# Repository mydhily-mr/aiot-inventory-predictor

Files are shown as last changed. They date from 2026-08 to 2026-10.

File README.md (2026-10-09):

# PRISM — Predictive Replenishment & Inventory Stock Monitoring

**PRISM predicts what you're about to run out of, before you run out.**

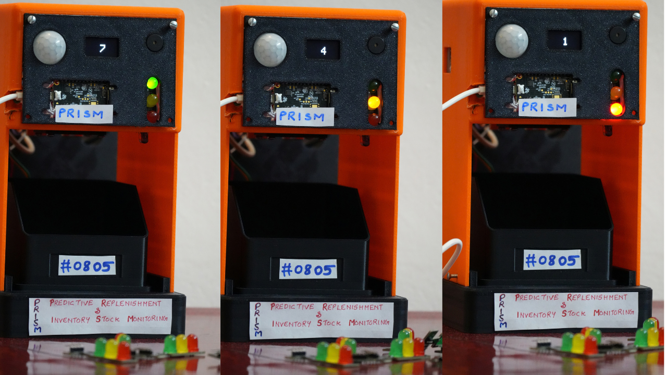
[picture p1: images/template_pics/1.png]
PRISM – three units showing green, yellow and red stock levels


📺 **Demo video:** [youtu.be/odlPvgT5Zeg](https://youtu.be/odlPvgT5Zeg?si=Ek_2I9EwPxp-R_3K)  
📖 **Full build write-up:** [PROJECT_DETAILS.md](https://github.com/mydhily-mr/aiot-inventory-predictor/blob/main/docs/PROJECT_DETAILS.md)  
📺 **Website:** [Website Link](https://mydhily-mr.github.io/prism/)  
🛠️ **Sensor testing docs:** [docs/](https://github.com/mydhily-mr/aiot-inventory-predictor/tree/main/docs)

---

## What is PRISM?

PRISM turns an ordinary component bin into a smart AIoT inventory node. A load cell under the bin counts components in real time on an Analog Devices **MAX32630FTHR**. An IR sensor and the weight drop together estimate each pick. A red/yellow/green LED, an OLED display and a buzzer show the stock level right at the shelf.

Readings flow through a **NodeMCU Wi-Fi gateway** into **Firebase**. A web dashboard gives the stock manager a live view, and a machine-learning model forecasts **days-to-empty** for every bin.

The aim is to know how much stock is left, and also when it is going to run out.

## Why build it?

- **Counts are stale.** Stock is counted by hand or updated at the end of a shift, so the record never matches the shelf.
- **Systems track issues, not what is left.** Barcode and ERP entries record what was booked out, not what is physically in the bin.
- **Stock-outs are found too late.** A bin is found empty after the time to reorder has passed.
- **Reorder points ignore real usage.** Fixed minimum levels don't follow actual consumption or supplier lead time.
- **Workers get no signal.** Nothing at the shelf warns that a bin is nearly empty.

## Key Features

- **Counts by weight:** no scan per pick, because the bin always knows its own count.
- **Sensor fusion for picks:** the IR sensor sees a hand enter, and the weight drop after the hand leaves shows how many pieces were taken.
- **Forecasts learned from data:** reorder timing comes from the measured depletion trend, not a fixed minimum level.
- **Alerts work offline:** the LED, OLED and buzzer run on the MAX32630FTHR itself, so the shelf still warns the worker if Wi-Fi drops.
- **One protocol for any bin:** each bin's identity lives on the device and the gateway is a generic relay, so adding a bin only needs a new `binId`.

## Who It Serves

| Who | What they get | Built with |
|---|---|---|
| Worker at the shelf | Live piece count, green / yellow / red stock light, and a 10-second buzzer at 20% stock | MAX32630FTHR, load cell, OLED, RYG LED, buzzer |
| Stock manager | Live dashboard with stock KPIs, bins ranked by which runs out first, per-bin forecast charts, reorder timing, shipments and FIFO checks | Firebase + web dashboard |
| Purchasing | Days-to-empty from each bin's consumption trend, plus an email alert when a bin drops inside its lead time | Python regression model |

## How It Works

```
Inventory → Sensors → MAX32630FTHR → NodeMCU Wi-Fi → Firebase → Dashboard → Prediction → Email Alert
```

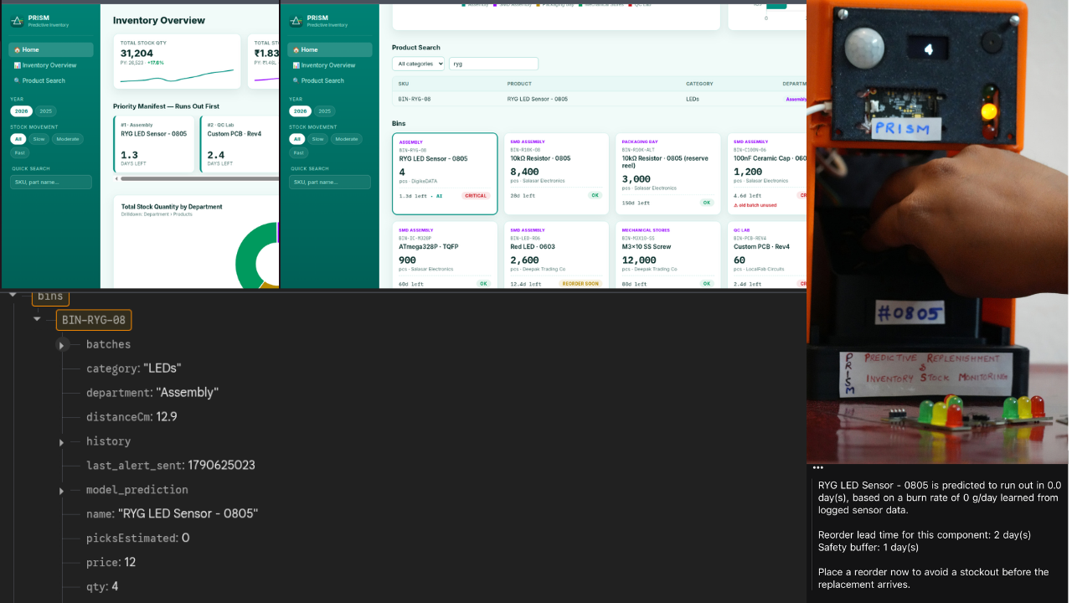
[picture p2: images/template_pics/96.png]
PRISM system concept


### Stock Level Indication

Count estimate: **Number of pieces = (Measured Weight − Empty Tray Weight) / Weight of One Piece**
(demo: tray ≈ 55 g, one RYG LED ≈ 3.55 g)

| Light | Rule | Action |
|---|---|---|
| 🟢 Green | above 50% | Normal |
| 🟡 Yellow | 21% to 50% | Worker is alerted that stock is decreasing |
| 🔴 Red | 20% or less | Red LED + 10-second buzzer, so the worker notifies the store manager |

## Hardware

| Component | Qty |
|---|---|
| [MAX32630FTHR](https://www.analog.com/media/en/technical-documentation/data-sheets/max32630fthr.pdf) + MAX32625PICO (DAPLink) | 1 |
| Load Cell 5 kg + HX711 amplifier | 1 |
| SSD1306 OLED Display 0.96" | 1 |
| HC-SR04 Ultrasonic Sensor | 1 |
| IR Sensor | 1 |
| PIR Sensor | 1 |
| Piezo Buzzer | 1 |
| RYG LED indicator | 1 |
| RYG LEDs (demo inventory items) | 14 |
| NodeMCU (ESP Wi-Fi) | 1 |
| Zero / dotted PCB, jumper wires, 3D-printed enclosure | — |

🛒 Full BOM: [DigiKey MyList](https://www.digikey.in/en/mylists/list/48SZ6VB09U)

### Pin Connections (MAX32630FTHR)

| Module | Pins |
|---|---|
| HX711 | VCC → 3.3 V, GND → GND, DOUT → P5_5 (pin 45), SCK → P5_4 (pin 44) |
| ESP Wi-Fi | GND → GND, D7 (RX) → P3_1 (TX), D8 (TX) → P3_0 (RX) |
| SSD1306 OLED | VCC → 3V3, GND → GND, SDA → P3_4, SCL → P3_5 |
| HC-SR04 Ultrasonic | VCC → 3V3, GND → GND, TRIG → P5_6, ECHO → P4_0 |
| RYG LED | GND → GND, R → P5_0, Y → P5_1, G → P5_2 |
| Piezo Buzzer | VCC → 3V3, GND → GND, SIG → P5_3 |
| IR Sensor | VCC → 3V3, GND → GND, O/P → P3_3 |
| PIR Sensor | VCC → 3V3, GND → GND, OUT → P3_2 via 1K resistor to GND |

Load cell → HX711: Red → E+, Black → E−, Green → A+, White → A−

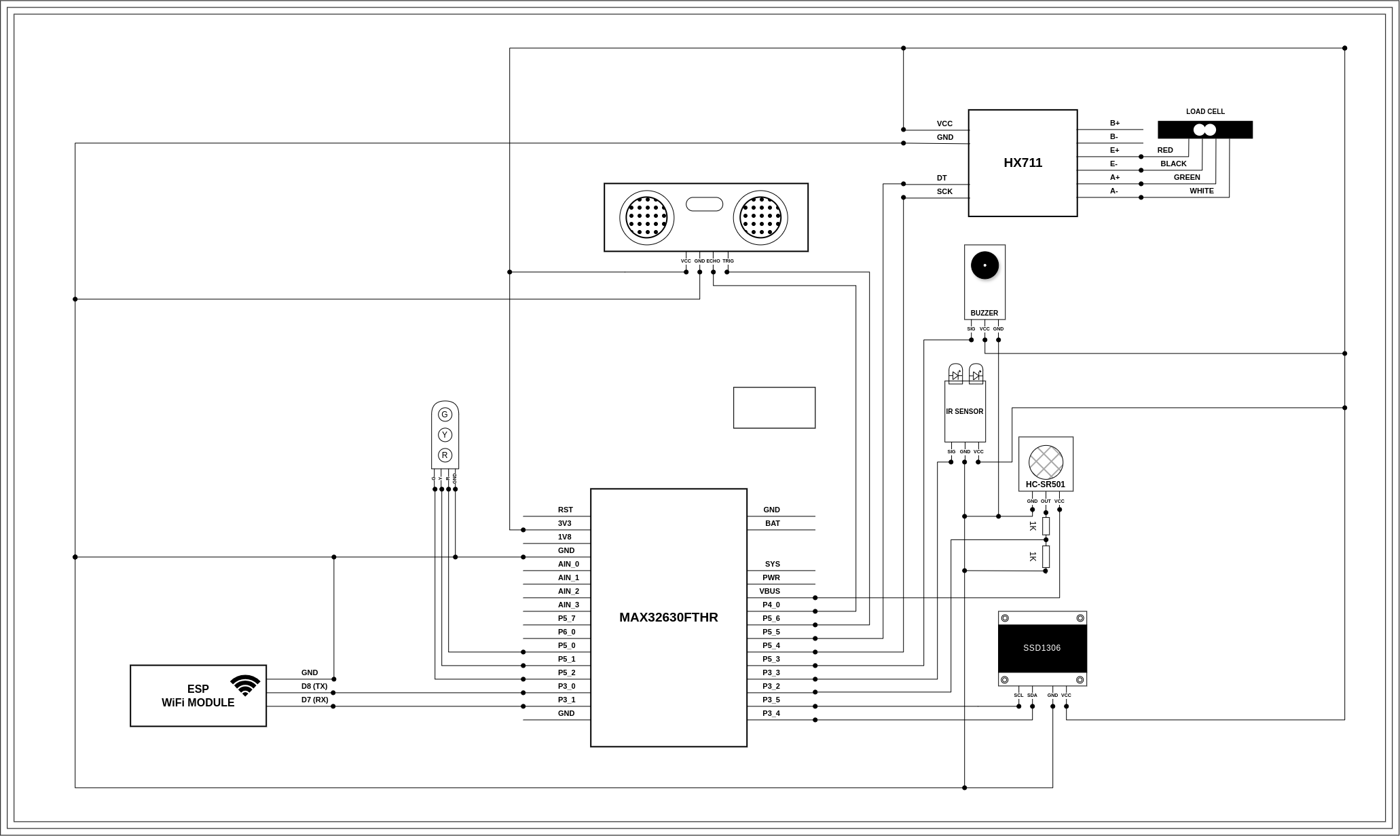
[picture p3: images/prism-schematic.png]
Schematic


## Tech Stack

- **Firmware:** Arduino IDE with the Maxim MAX326xx board package (MAX32630FTHR, DAPLink programmer)
- **Gateway:** NodeMCU Wi-Fi module over UART
- **Cloud:** Firebase Realtime Database
- **Dashboard:** Web GUI with inventory overview, category filtering, per-bin forecasts, trend and history charts, invoice PDF tracking and night mode
- **AI:** Python Linear Regression model for days-to-empty forecasting, with email alerts
- **Enclosure:** Designed in Fusion 360 and 3D-printed

## Getting Started

1. **Set up the board.** In Arduino IDE, add this URL under *File → Preferences → Additional Boards Manager URLs*:
   ```
   https://raw.githubusercontent.com/analogdevicesinc/arduino-max326xx/master/package_maxim_index.json
   ```
   Install **Maxim's 32-bit Microcontroller** from the Boards Manager. Then select **MAX32630FTHR**, your port (e.g. `/dev/ttyACM0`) and the **DAPLink** programmer.
2. **Wire the sensors** using the pin table above.
3. **Test each sensor individually** by following the guides in [`docs/`](https://github.com/mydhily-mr/aiot-inventory-predictor/tree/main/docs).
4. **Flash the firmware**, calibrate the load cell (empty tray weight and single-piece weight), and connect the NodeMCU gateway to Firebase.
5. **Run the dashboard and prediction model** locally.

See [PROJECT_DETAILS.md](https://github.com/mydhily-mr/aiot-inventory-predictor/blob/main/docs/PROJECT_DETAILS.md) for the complete step-by-step build.

## Dashboard

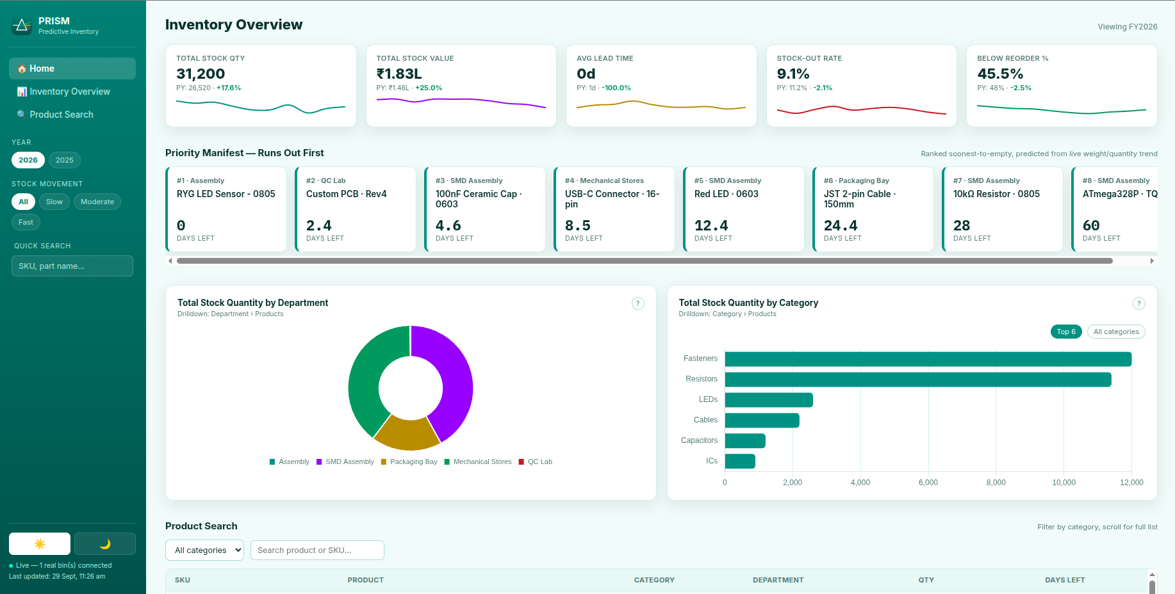
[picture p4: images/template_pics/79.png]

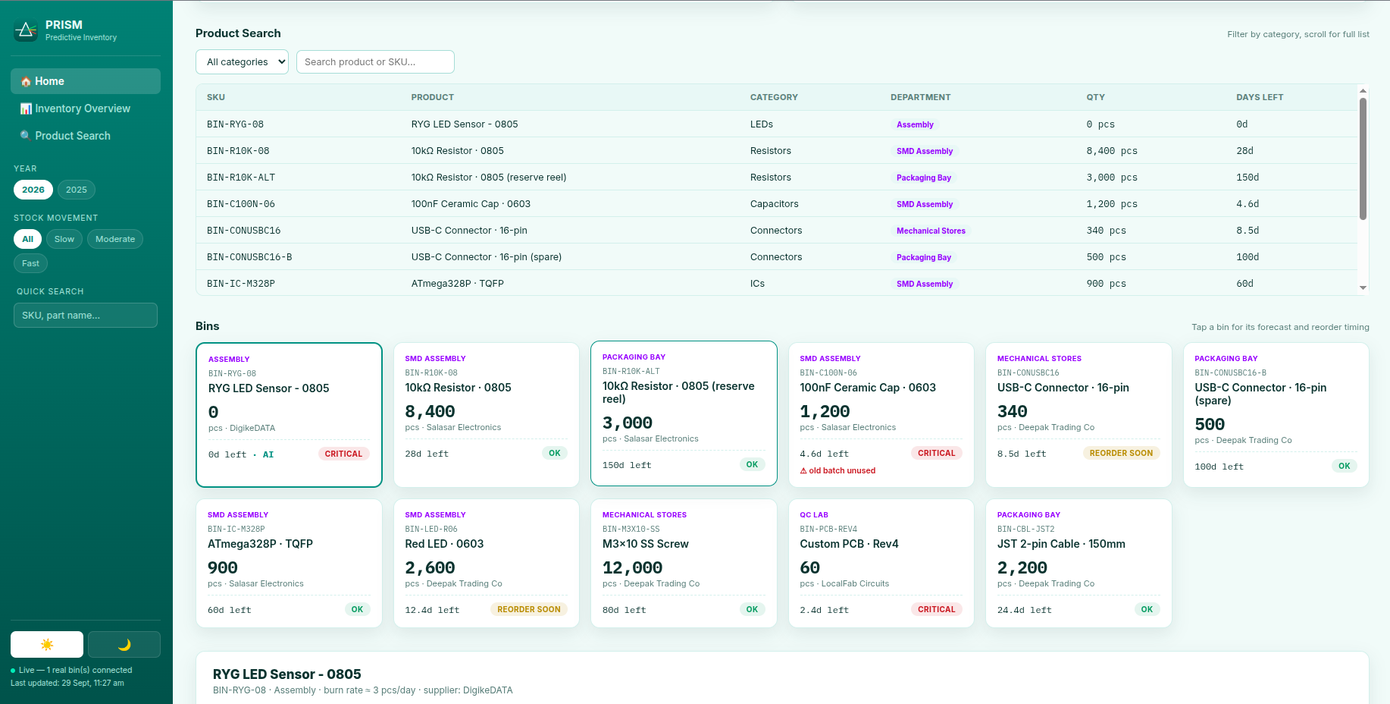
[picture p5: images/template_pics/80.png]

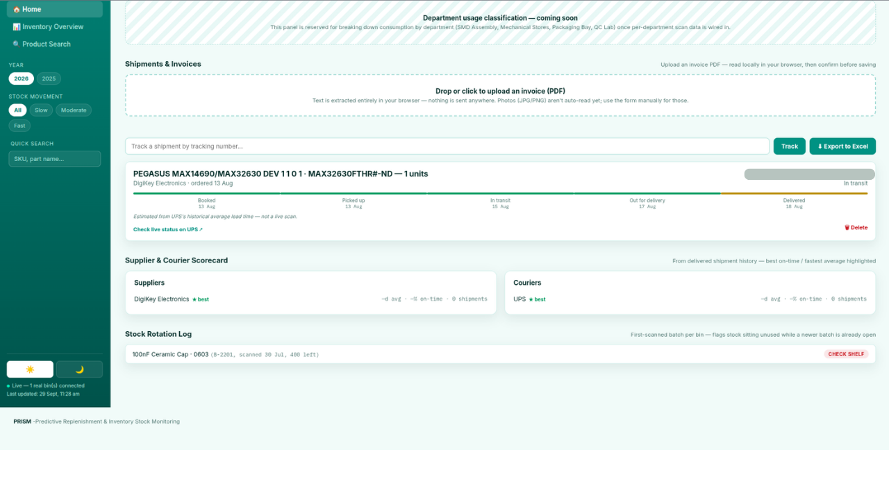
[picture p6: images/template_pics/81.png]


## Project Status

PRISM is a working prototype. The GUI and prediction model currently run locally, and the RYG LED bin is the live real-time dataset. Next steps include more inventory categories, larger datasets, better prediction models and production-level deployment.

## Author

**Mydhily M R**. Built for the AIoT Design Challenge 2026.

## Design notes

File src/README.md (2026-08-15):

# aiot-inventory-predictor
#AI-Based Predictive Inventory Management System (PIMS)

**AIoT Inventory Predictor** is an edge-based IoT system using the **Analog Devices MAX32630FTHR** to monitor material consumption and predict potential stockouts before they disrupt manufacturing.

##Files and Descriptions:
store_board.html  -  Front end website display for the inventory prediction,

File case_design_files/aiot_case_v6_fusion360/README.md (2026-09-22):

# AIoT Smart Storage Bin — Case v6

A case sized to your **real sensor geometry** (measured from the STEP files
in `sensors.zip`, not the PDF's numbers — several of those were clearly
wrong, e.g. HC-SR04 listed as 13x13x8cm when the actual part is
45.7 x 27.3 x 19.3mm). Layout follows your annotated photo (`claud_image.PNG`);
styling (rounded "kiosk" body, raised top sensor pod) takes cues from your
reference photo (`image_reference.jpeg`) without copying the previous
`case_design_v4` design.

## What changed in v6

You flagged three real problems after reviewing v5 — here's what was
actually wrong and what changed:

1. **"Camera/ultrasonic openings on top are closed."** True. The v5 holes
   only went 9mm deep from the pod's outer surface, which landed inside
   the pod's own solid mass — there was an ~11mm plug of material still
   blocking the path down into the hollow shaft (confirmed by ray-casting
   straight down through the mesh: the ray hit solid material well before
   reaching the interior). **Fixed**: the lens hole and both ultrasonic eye
   holes now cut from above the pod all the way through into the hollow
   interior. Re-verified with the same ray-cast test — now the only thing
   a ray hits on the way down is the floor. `verify_openings.py` in this
   folder is that test; run it any time you change hole positions.

2. **"PIR should face outside like the OLED, need a hole for that."** The
   PIR dome hole was actually already a real through-hole in v5 (confirmed
   separately by the same ray-cast method), so no change was needed there.
   What follows from your note is stated explicitly in this version:
   the PIR is on the **front face**, and its 24mm dome hole passes
   completely through the wall so the dome sits flush/exposed at the
   outside surface — the same "faces outward" relationship the OLED
   window has.

3. **NEW: hand-detect IR sensor.** Added the IR LM393 (from `sensors.zip`
   — it was in the parts list but unused in v5) mounted on the **inner
   right wall, right at the front bin opening**, sensing face pointing
   across the access gap. A hand reaching in for a component breaks its
   beam, so it can count access events. No PDF/estimated numbers used
   here — this one's dimensions are measured straight from
   `IR LM393.step`.

While fixing #1, a **real but separate bug** turned up and got fixed too:
the NodeMCU side window in v5 never actually cut through the outer wall —
same class of mistake (a cut positioned a few mm off, landing entirely
inside the already-hollow interior instead of touching the wall), also
caught and confirmed fixed by ray-casting. All other hole/pocket sizes are
untouched from v5 — **every sensor's cutout is still sized off its actual
measured dimensions in `sensor_dims.py`, nothing was shrunk**.

## What's in this folder

| File | What it is |
|---|---|
| `sensor_dims.py` | Every sensor dimension used, with a note on where each came from (measured vs. standard vs. estimated). **Read this first if anything doesn't fit** — it's the one file to edit. |
| `build_case.py` → `case_body_v6.step` / `.stl` | The main enclosure: plinth, tower, all sensor cutouts, top sensor pod, IR sensor mount, back opening. |
| `build_platform.py` → `loadcell_platform.step` / `.stl` | The round turntable that sits on the case floor and holds your HX711 load-cell bar (the "weight measurement" mechanism from your reference photo). |
| `build_bin.py` → `storage_bin_optional.step` / `.stl` | **Optional** printable storage bin, sized to sit on the platform and fit inside the case's bin bay. Skip this if you're using your real "Plastic Bin Box" part instead (see below). |
| `build_back_cover.py` → `back_cover_v6.step` / `.stl` | Screw-on back panel, closes the open back used for wiring access. |
| `verify_openings.py` | The ray-cast test that found and confirmed the fixes above. Re-run after any change to hole positions. |
| `render_sensors_assembly.py` → `sensors_placed_preview_v6.png` | Renders a labelled preview with the real sensor CAD (camera, ultrasonic, Grove Vision AI, OLED, buzzer, NodeMCU) placed where they mount, plus sized placeholder blocks for the others. Sanity-check only, not needed for printing. |

All `build_*.py` files are plain **CadQuery** (Python) scripts — this is
how your previous `case_design_v4` was made too, so the workflow is the
same one you already used.

## Opening and editing in Fusion 360

**Fastest path — just print or view:** File → Open → pick any `.step` file.
Fusion imports it as a solid body you can inspect, measure, and
directly-edit (push/pull faces, add fillets, move holes) right away. Do
this for all 4 parts (`case_body_v6`, `loadcell_platform`,
`storage_bin_optional`, `back_cover_v6`) and you have a fully assembled,
print-ready design in Fusion within a minute.

**To actually change dimensions (recommended if any sensor doesn't fit):**
these parts were generated from code, not sketched by hand, so the real
"parametric" source is the `.py` script, not the STEP file. To resize
something:
1. Open `sensor_dims.py`, change the number(s) for that sensor.
2. Re-run the matching `build_*.py` (needs Python 3 + `pip install cadquery`
   — takes a few minutes to install once).
3. Re-import the new `.step` into Fusion (or just re-open it in Design →
   New Design; it replaces the old one).

This is faster and safer than hand-editing a STEP body in Fusion (which
can break if a hole isn't in exactly the right spot), but if you'd rather
work by hand, the STEP import is a completely normal Fusion body —
direct-edit tools work on it as with any solid.

**Your SolidWorks (.SLDPRT) sensor files** — the PIR, the HX711 load-cell
parts, and the plastic storage bin only came as `.SLDPRT`, which this
Python/CadQuery toolchain can't read (proprietary format). **Fusion 360
opens `.SLDPRT` natively** (File → Open → Upload), so before you print:
open those three parts in Fusion, use Inspect → Measure to check their
real size, and compare against the three flagged entries in
`sensor_dims.py` (`PIR_HCSR501`, `LOAD_CELL_HX711_BAR`, `PLASTIC_BIN`) —
those are the only estimated ones; everything else (including the IR
sensor added in v6) came from measuring your actual STEP files.

## Assembly

- Case sits on its plinth. Inner floor is at `PLINTH_T + T` (17mm) above
  the plinth bottom.
- `loadcell_platform` — place its flange centred at **X=0, Y=-9mm**
  (printed as `platform_center_y` when you run `build_case.py`), flange
  bottom flush on the case's inner floor. Four 2.2mm pilot holes in the
  case floor line up with the platform's four 2.4mm clearance holes —
  self-tapping M2 screws hold it down.
- Storage bin (yours, or the optional printed one) rests on the platform's
  90mm platter, roughly centred, visible through the front bin window —
  see "Does the bin actually fit" below.
- Electronics mount in the three front rows, the left-side window, and the
  new right-side IR mount, as labelled directly in `build_case.py`'s
  comments (search for "Row 1", "Row 2", "Row 3", "LEFT SIDE", "RIGHT
  INNER WALL").
- Grove Vision AI V2 mounts on 4 small internal pegs under the top pod,
  next to the camera — no external hole, it just cables to the camera.
- IR LM393 mounts on 2 small internal pegs on the right inner wall, right
  at the bin opening — also fully internal, no external hole; it just
  needs a clear sightline across the opening.
- Close up with `back_cover_v6`, four screws into the lip (3.2mm holes,
  self-tapping screw or M3).

## Does the bin actually fit inside this case?

Yes, checked geometrically:
- The optional printed bin's footprint (62×42mm bottom, 76×54mm top) sits
  on the platform's 90mm-diameter platter with **7.6mm clearance on every
  corner** (its bottom corners are 37.4mm from centre vs. the platter's
  45mm radius).
- Its height (45mm) plus the platform stack under it puts the bin's rim at
  ~83mm above the case floor — well inside the 92mm-tall bin bay (`BASE_H`)
  before the electronics section starts, and lines up with the 96mm-wide,
  76mm-tall front bin window so it's visible/reachable from the front.
- If you're using your real "Plastic Bin Box" part instead: open it in
  Fusion, check it's under roughly 80×58mm at the base and 45mm tall, and
  it'll sit on the platform the same way. If it's bigger than that, the
  two numbers to change are `PLATFORM_R` (currently 50mm radius) in both
  `build_case.py` and `build_platform.py` — keep them equal in both files
  — and `BIN_WINDOW` sizing in `build_case.py`'s step 6.

## Printing tonight

- PLA or PETG, 0.2mm layers, 15–20% infill, 2–3 wall loops is plenty for
  this size.
- Print the case standing up in its natural orientation (as designed) —
  the open back is a plain cutout, not an overhang, so it needs **no
  supports** for the main body.
- Turn supports ON only if your slicer flags the small internal mounting
  pegs (Grove Vision AI, IR sensor) — they're only ~3-4mm, most printers
  handle them fine without.
- The back cover and platform print flat, no supports needed.
- Everything was verified watertight (single manifold solid, checked with
  `trimesh`) before export, so slicers shouldn't report errors — if one
  does, it's almost always fixed by your slicer's "fix mesh" / re-mesh
  option.

## What to double check before printing

The dimensions below are the ones **not** taken from a measured STEP file
— worth a 2-minute check against your physical parts or the SLDPRT files
in Fusion before committing to a print:
- HX711 load-cell bar length/hole spacing (`sensor_dims.py` → `LOAD_CELL_HX711_BAR`)
- PIR HC-SR501 dome size (`PIR_HCSR501`) — very standard, low risk
- Plastic storage bin footprint (`PLASTIC_BIN`) — biggest unknown, since it
  only affects the printed *optional* bin; if you're using your real bin,
  see "Does the bin actually fit" above.

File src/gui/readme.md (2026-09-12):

store_board_v1 - basic gui
store_board_v2 - Pdf upload support added
store_board_v1 - added pdf upload support, if same pdf uploaded twice replace the exisiting one with popup
               - delet button added for deleting unwanted tracking events

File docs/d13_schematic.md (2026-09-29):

## System Schematic

The overall hardware architecture of the AIoT inventory monitoring system is shown below.

<p align="center">
  AIoT Inventory System Schematic
</p>

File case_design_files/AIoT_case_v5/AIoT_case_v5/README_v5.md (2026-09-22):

# AIoT Smart Inventory Case v5: print and assembly guide

This is a new design based on your reference photo: a tower with an open bin bay, an overhanging "head" that holds the electronics, and a base that hides the load cell under the bin. It is not a modified v4. Every sensor opening was sized from your GrabCAD models, or from datasheets where no model was given. I also placed all the sensors in a full 3D assembly and ran a collision check: **0 collisions**.

Overall size is 132 × 179 mm footprint and 226 mm tall (tower 196 mm plus base 30 mm).

---

## 1. What's in this folder

| Folder / file | What it is | Use it for |
|---|---|---|
| `STEP_for_Fusion360/00_CASE_ASSEMBLY_printed_parts_only.step` | All printed parts in their assembled positions (1.8 MB) | **Open this first in Fusion 360** |
| `STEP_for_Fusion360/00_FULL_ASSEMBLY_with_sensors.step` | Same, plus every sensor placed inside (47 MB, slower to open) | Checking the fit visually |
| `STEP_for_Fusion360/01…09_*.step` | Each part on its own | Editing one part |
| `print_ready_STL/*.stl` | Every part already turned the right way for the print bed | **Drag straight into your slicer (Cura / PrusaSlicer / Bambu Studio)** |
| `STL_assembled_position/*.stl` | Same parts in assembled position | Reference only |
| `renders/*.png` | Pictures of the design | Showing people |
| `source_python/` | The script that generates everything (CadQuery) | Changing sizes precisely (see section 7) |

### Parts list

| # | Part | Qty | Print on bed as |
|---|---|---|---|
| 01 | Tower body (sides + head) | 1 | Lying on its **open back** |
| 02 | Base (plinth + load-cell pocket) | 1 | Upright |
| 03 | Faceplate, for a **1.3" OLED** | 1 | Front face down |
| 03b | *Alternative* faceplate for a **0.96" OLED** | only if your OLED is 0.96" | Front face down |
| 04 | Back cover | 1 | Flat |
| 05 | Weighing platform (the bin sits on it) | 1 | Upright |
| 06 | Load-cell spacer | 1 | Flat |
| 07 | Camera plate, **standard Pi camera OV5647** (25 × 24 mm board, like your PDF photo) | 1 | Flat |
| 07b | *Alternative* camera plate for the **wide-angle 32 × 32 mm** OV5647 (your GrabCAD model) | only if you have that one | Flat |
| 08 | Storage bin (pick-bin with a low front, like the blue bin in your reference) | 1 or more | Upright |
| 09 | 4 small standoffs for the MAX32630FTHR | 1 set | Flat |

**Which OLED and camera do you have?** Your GrabCAD OLED model is 1.3", but the photo in your PDF could be either 1.3" or 0.96". The camera in your PDF photo is the small 25 × 24 mm board, but your GrabCAD camera is the 32 × 32 mm wide-angle one. Measure your parts with a ruler before printing and pick the matching 03/03b and 07/07b. Both are small, quick prints.

---

## 2. Opening in Fusion 360

1. Fusion 360 → **File → Open → Open from my computer…** → choose `00_CASE_ASSEMBLY_printed_parts_only.step`. It uploads, then opens with each part as its own component in the browser on the left.
2. **If the model appears lying on its back:** Fusion's default is "Y up" and these files are "Z up". Go to **Preferences → General → Design → Default modeling orientation → Z up**, then re-open. You can also just rotate the view; nothing is actually wrong with the file.
3. **Editing:** STEP files open as solid bodies without the original timeline. You can still edit them directly:
   - **Press Pull** (shortcut Q) on any face moves it. Click the inside of a hole and type a new size.
   - **Move/Copy** (M) on a face moves a hole or window.
   - Sketch on a face, then **Extrude → Cut** to add a hole.
   - To print a part: right-click the body → **Save as Mesh** → STL (or 3MF).
4. The 47 MB full assembly also shows the sensors (green) sitting in their mounts. Use **Inspect → Section Analysis** to look inside.

---

## 3. Printing

**Material:** PLA or PETG. Use black or dark grey for the case to match the reference.

**Settings:** 0.4 mm nozzle, 0.2 mm layers (0.28 mm is fine for the body and base to save time), 3 walls/perimeters, 15 % infill, **supports OFF**, brim ON for the tower body.

Every part is designed to print **without supports** in the orientation in `print_ready_STL`. I checked this with an overhang scan. The remaining overhangs are small bridges (≤ 20 mm) or 45° slopes.

**Bed size needed:** the largest parts are 122 × 196 mm (tower body and back cover) and 132 × 179 mm (base). They fit a 220 × 220 mm bed (Ender-3, Bambu A1/P1, Prusa MK3/MK4). **They will not fit a 180 mm bed** (Bambu A1 mini, Prusa Mini). Tell me if that's your printer and I'll split the tower into two halves.

**Rough time:** these are estimates only; your slicer will give the real figure. About 400 g of PLA in total. Roughly 8–10 h on a fast printer (Bambu, Prusa MK4), or 18–24 h on an Ender-3-class printer at normal speed. Since you're short on time:
- **Start the tower body first.** It's the longest print (about 40 % of the total).
- Next: base → faceplate + camera plate + spacer + standoffs (these can share one plate) → platform → bin → back cover.
- The back cover is only needed to close the case, so it can be printed last.

---

## 4. Hardware list

| Where | Screws |
|---|---|
| Faceplate → tower | 4 × M3 × 10 (self-tapping into the 2.5 mm pilot holes) |
| Back cover → tower | 4 × M3 × 10 |
| Back cover → base | 2 × M3 × 8 |
| Tower → base (through the side walls into the base lip) | 4 × M3 × 8 |
| 1.3" OLED → faceplate (screws from the front, nuts behind) | 4 × M2.5 × 8 + nuts |
| MAX32630FTHR → front of faceplate (through printed standoffs) | 4 × M2.5 × 10 + nuts |
| NodeMCU → inside left wall (into the bosses) | 4 × M3 × 6 |
| Camera plate → head floor | 4 × M3 × 10 + nuts |
| Camera → camera plate | 4 × M2 × 6 (standard camera) or M2.5 × 6 (wide camera) |
| IR sensor → its tab | 1 × M3 × 10 + nut |
| Load cell → base (from underneath, socket head) | 2 × M4 × 12 |
| Platform → spacer → load cell (countersunk, from the top) | 2 × M4 × 16 flat-head |
| Under the base | 4 rubber feet, 12 mm (optional) |
| HC-SR04, PIR, buzzer, RYG LED, Grove Vision AI, HX711 | Located by frames/rails; a dab of **hot glue** holds them |

M3 and M2.5 "laptop" screw kits work well here.

---

## 5. Where every sensor goes

The sizes below are real board sizes. The sizes in your PDF are **Amazon package sizes**, not board sizes (for example, it lists the HC-SR04 as "13 × 13 × 8 cm"; the board itself is 45 × 20 mm), so I didn't use them for fitting.

| Sensor | Location | How it mounts | Size source |
|---|---|---|---|
| **HC-SR501 PIR** | Faceplate top-left; the dome pokes out the front through a 23.4 mm hole | Dome sits in the hole, PCB in a frame behind, hot glue | Datasheet (32.3 × 24.3 PCB, Ø23 dome) |
| **SSD1306 OLED** | Faceplate top-centre, behind a window; pins at the top | Glass drops into a 1.9 mm recess; 4 × M2.5 screws from the front (1.3") | **Your GrabCAD model**: PCB 35.7 × 34, holes 30.4 × 28.6, active area 30.4 × 15.5 |
| **Piezo buzzer module** | Faceplate top-right; buzzer pokes through a 12.4 mm hole, pins pointing down | U-frame behind, hot glue | Your GrabCAD buzzer (Ø12) + PDF (13.3 mm wide module) |
| **RYG LED module** | Faceplate right, vertical slot (like a real traffic light) | LEDs poke through the 32 × 10 slot, hot glue | Estimate. The slot fits 5 mm or 8 mm LEDs at 8–11 mm spacing |
| **MAX32630FTHR** | **Front** of the faceplate (shown off like the board in your reference photo) on 4 mm standoffs; header pins go through the opening behind it for Dupont wires | 4 × M2.5 through **slotted** holes (±1.5 mm) | Feather format 50.8 × 22.86, holes 45.72 × 17.78 |
| **NodeMCU + 0.96" OLED** | Inside the **left side wall** of the head; its OLED shows through a side window; USB end toward the back | 4 × M3 into bosses (4 mm standoff) | **Your GrabCAD model**: PCB 57.8 × 31.5, holes 53.5 × 26.5 |
| **Pi camera OV5647** | Head floor, lens looking straight down at the bin centre | On its camera plate (07 or 07b), which screws onto the floor | PDF photo (25 × 24) / **your GrabCAD** (32 × 32) |
| **Grove Vision AI V2** | Inside the **right side wall**, in two rails; slides in from the back with the camera connector (CSI) toward the front | Rails + dab of glue (the board has no mounting holes) | **Your GrabCAD model**: 40 × 20 |
| **HC-SR04 ultrasonic** | Head floor behind the camera, both "eyes" looking down into the bin through 20 mm holes | Side guides + ledges, hot glue; pins point to the back | **Your GrabCAD model** (the holes also fit the common Ø16 @ 26 mm version) |
| **IR sensor LM393** | Just inside the front edge of the hood, LEDs pointing straight down: a **hand trigger** that fires when someone reaches into the bin | Stands on edge against a tab, 1 × M3; LEDs through two Ø5.6 holes | **Your GrabCAD model** |
| **Load cell** (75 × 12.7 × 12.7, 4 × M4) | In the base pocket, running front-to-back under the bin | Back end bolted to the base riser from below; front end bolted through the spacer to the platform | Drawing in your load-cell zip |
| **HX711** | In the base pocket beside the load cell | Frame (21.8 × 34.8 inside) + tape/glue | Typical 34 × 21 board |

**Load cell direction:** the end with the **wires** goes to the **back** (the fixed end on the riser), and the arrow on the cell points **down**. The platform must only touch the spacer. It has a 3 mm gap to the base on every side, and the fit check confirms that.

**Camera view:** at this height a standard ~62° camera sees roughly the middle 100 × 75 mm of the bin. The wide-angle camera sees the whole bin.

---

## 6. Assembly order

1. **Base:** bolt the load cell onto the riser from underneath (2 × M4 × 12), wire end at the back. Glue the HX711 in its frame. Route its 4 wires out through the notch in the back lip.
2. **Platform:** put the spacer on the front end of the load cell, then the platform on top, and fix with 2 × M4 × 16 countersunk screws from the top. Check that the platform floats freely.
3. **Head floor (inside the tower, from the back):** camera + camera plate, HC-SR04, IR sensor on its tab, and the Grove Vision AI slid into the right-wall rails. Connect the camera ribbon to the Grove board.
4. **Left wall:** NodeMCU (OLED facing the window).
5. **Faceplate:** fit the PIR, OLED, buzzer and RYG LED from behind, and the MAX32630FTHR on the front. Wire everything, then screw the faceplate into the front of the head.
6. Lower the tower onto the base (it slides over the lip) and fix with 4 × M3 through the side walls.
7. Pass the wires from the base up through the slot at the back of the head floor. Fit the back cover (6 × M3); the USB cables come out through its two slots.
8. Put the bin on the platform. The rim stops it sliding around.

---

## 7. Changing sizes precisely (optional)

`source_python/build_case_v5.py` rebuilds every part. All the important numbers are in the PARAMETERS block at the top: bin size, wall thickness, positions of each sensor on the faceplate (`PIR_UV`, `OLED_UV`, …), head floor layout, and so on.

```
pip install cadquery trimesh
python build_case_v5.py                  # writes ./out/*.step and *.stl
python assembly_check.py                 # re-runs the collision check (needs the GrabCAD sensor folders)
```

For example, to make the bin bigger, change `BIN_W, BIN_L, BIN_H`. The platform, base pocket and tower resize automatically.

---

## 8. Measure these before printing

These are the parts I had to size from datasheets rather than from your models:

- **MAX32630FTHR mounting holes.** Assumed Feather standard 45.7 × 17.8 mm; the holes are slotted so small differences are OK.
- **RYG LED module.** The slot takes 3 LEDs up to 8 mm across and 11 mm apart.
- **PIR.** The dome should be about 23 mm across.
- **OLED:** 1.3" or 0.96"? **Camera:** 25 mm or 32 mm board? Pick the matching faceplate and camera plate.

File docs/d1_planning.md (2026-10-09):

[← Back to README](../README.md)

## Introduction
<!-- **14 Aug 2026** -->

### Data Collection

Feedback was gathered from real inventory users about common problems in physical stock rooms:

| # | Identified Issue | How PRISM addresses it |
|---|---|---|
| 1 | Manually updating stock in software takes too much time. | Automated sensor updates: load cell → Wi-Fi → cloud database. |
| 2 | Stock-outs are noticed too late, usually when the bin is already empty. | Local RYG LED + buzzer warning, plus AI days-to-empty forecast. |
| 3 | It's hard to know exactly where things are and how much is left in each bin. | OLED on every bin showing live count, and a web dashboard for the stock manager. |
| 4 | Nobody knows how fast a component is really being consumed. | Hand-pick detection (IR) and weight-drop history feed a consumption-rate model. |

**Existing Systems**

FIFO
- The components received first are used first. This helps prevent old or perishable components from remaining in inventory for too long. PRISM stores each delivery as a separate batch so the oldest batch can be identified.

Kanban System
- Uses visual signals, such as cards or digital alerts, to indicate when components need to be replenished. PRISM's green / yellow / red LED and buzzer work as a digital Kanban signal at the bin itself.

Lean Manufacturing
- Focuses on reducing waste, excess inventory, and unnecessary processes. The goal is to keep only the inventory needed for production.

Six Sigma
- Uses data and statistical methods to reduce errors and variation in processes. In inventory management, it can help improve demand forecasting and reduce inventory-related mistakes.

Bulk Manufacturing
- Produces large quantities of products or components at once. This can reduce production costs but may lead to excess inventory if demand is not accurately predicted.

**Current situation vs. our improved model**

Most inventory systems only ask *"How much stock do we have?"*

Our system asks four questions instead:
- Is the **quantity** correct, right now, without anyone counting?
- Is anyone **picking** from the bin, and how fast?
- Is the bin **running low**, and is the worker warned on the spot?
- **When will it run out**, so it can be reordered in time?

### Implementation Model

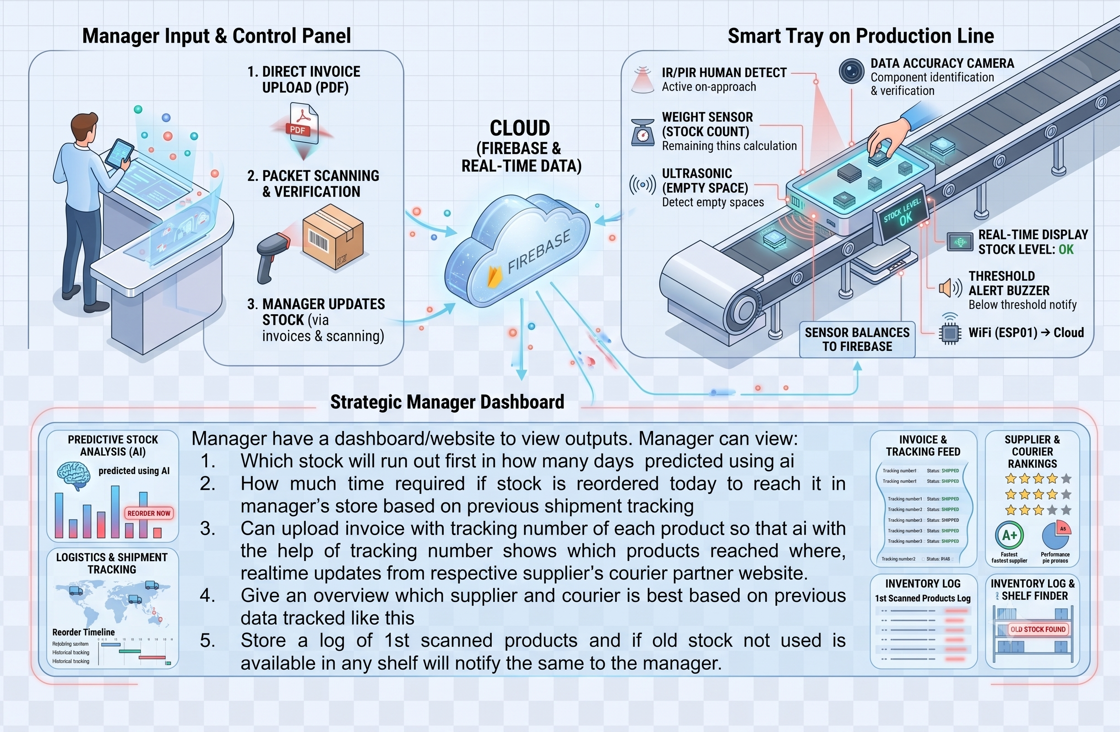
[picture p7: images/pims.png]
Sample Output

   *Sample Output*

> **`Fig 1.1`** — System architecture flowchart (Smart Inventory Bin → Load Cell / IR / Ultrasonic → MAX32630FTHR → NodeMCU Wi-Fi gateway → Firebase Realtime Database → Web Dashboard + AI Forecast)

The flow works like this:

1. **Three sensors feed the controller:**
   - **Load cell + HX711** → *"How many?"* (quantity from weight)
   - **IR reflective sensor** → *"Is someone picking?"* (hand-pick estimate)
   - **HC-SR04 ultrasonic** → *"How full is the bin?"* (fill level)
2. All sensors feed the **MAX32630FTHR** microcontroller, which calculates the piece count and drives the **OLED**, the **RYG LEDs** and the **buzzer** locally. The bin keeps warning the worker even if Wi-Fi is down.
3. The MAX32630FTHR sends compact `META` (bin details, every 30 s) and `DATA` (live readings, every 2 s) messages over UART to a **NodeMCU (ESP8266)**.
4. The NodeMCU writes them to **Firebase Realtime Database** over HTTPS.
5. The **web dashboard** reads Firebase live and shows stock, batches, days left and alerts to the stock manager.
6. A **Python forecasting script** (scikit-learn linear regression on weight history) writes a days-to-empty prediction back to Firebase, and the dashboard shows it with an AI badge.

**What each part tracks:**

| # | Thing to Track | Description | Solution |
|---|---|---|---|
| 1 | Quantity | How many pieces are in the bin? | Load cell + HX711; count = (weight − container tare) ÷ weight per piece |
| 2 | Picking activity | Is a hand taking parts out? | IR reflective sensor (estimated picks, cross-checked with weight drop) |
| 3 | Fill level | How full is the bin? | HC-SR04 ultrasonic distance |
| 4 | Local warning | Does the worker know the bin is low? | RYG LEDs + buzzer + OLED |
| 5 | Future availability | When will the bin be empty? | AI days-to-empty forecast |
| 6 | Remote visibility | Can the manager see every bin? | Firebase + web dashboard |

**Design note.** The first concept used a camera and RFID to verify that the *right* component was in the bin. This prototype focuses on counting, warning and forecasting using weight, IR and ultrasonic sensing only. Component identity checking by camera or RFID is left as a future extension.

### Circuit Diagram & Wiring

**Pin-connection reference** (MAX32630FTHR; verify against the final wiring before publishing):

| Component | Interface | MAX32630FTHR Pin(s) | Notes |
|---|---|---|---|
| HX711 + load cell | Digital (DT / SCK) | see sketch | One HX711 per bin |
| OLED (SSD1306) | I²C | `SDA`, `SCL` | Shows count with + / − change |
| HC-SR04 ultrasonic | Digital | `P5_6`, `P4_0` | Trigger / echo (use `useVDDIOH`) |
| IR reflective sensor | Digital in | `P3_3` | Hand-pick detection |
| Red / Yellow / Green LEDs | Digital out | `P5_0`, `P5_1`, `P5_2` | Each with a series resistor |
| Buzzer | Digital out via NPN transistor | `P5_3` | Active-LOW in this build (LOW = on) |
| NodeMCU gateway | UART (Serial2, 9600) | `TX`, `RX` | Wi-Fi to Firebase |

### Complete Product

**Pipeline:** `Sense → Count → Warn → Predict`

### Components Required

**Hardware used in the prototype:**

| Hardware | Purpose | Quantity |
|---|---|---|
| MAX32630FTHR | Edge controller | 1 |
| Load cell | Weight measurement | 1 |
| HX711 | Load-cell interface | 1 |
| OLED display (SSD1306) | Local count and status display | 1 |
| IR reflective sensor | Hand-pick detection | 1 |
| HC-SR04 ultrasonic sensor | Fill-level measurement | 1 |
| Red / Yellow / Green LEDs | Stock status indication | 3 |
| Buzzer + NPN transistor | Critical low-stock alert | 1 |
| NodeMCU (ESP8266) | Wi-Fi gateway to Firebase | 1 |
| Storage bin | Physical inventory container | 1 |
| Breadboard | Prototyping | 1–2 |
| Wires / connectors / resistors | Interconnects | As required |

**Future work (not in this prototype):**

| Hardware | Purpose |
|---|---|
| Camera | Component identity verification |
| RFID reader and tags | Automatic bin identification |
| Temperature / humidity sensor | Environmental monitoring |
| Multiple bins on one gateway | Scaling to a full shelf |
| Custom PCB | Final prototype consolidation |

**Reference builds / inspiration:**

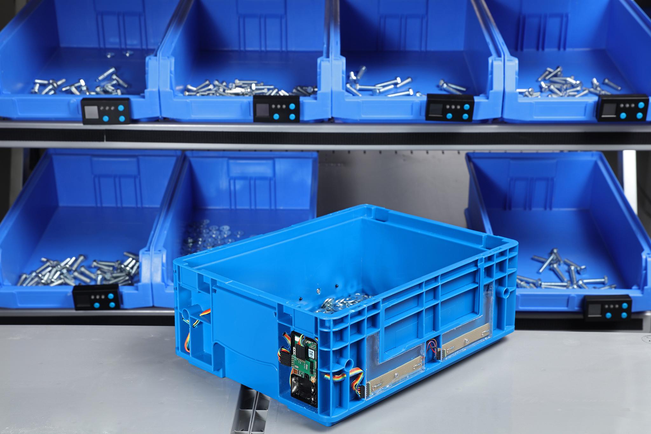
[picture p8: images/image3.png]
Reference 1
 — "IoT-Based Smart Retail Shelf Monitoring System" demo: bottles on a shelf next to a reader module and an OLED showing item count.

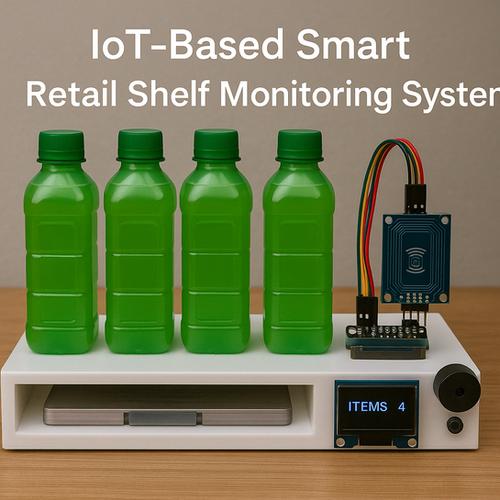
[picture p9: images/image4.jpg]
Reference 2
 — Load cell mounted under a shelf bracket (close-up of the sensor and mounting hardware).

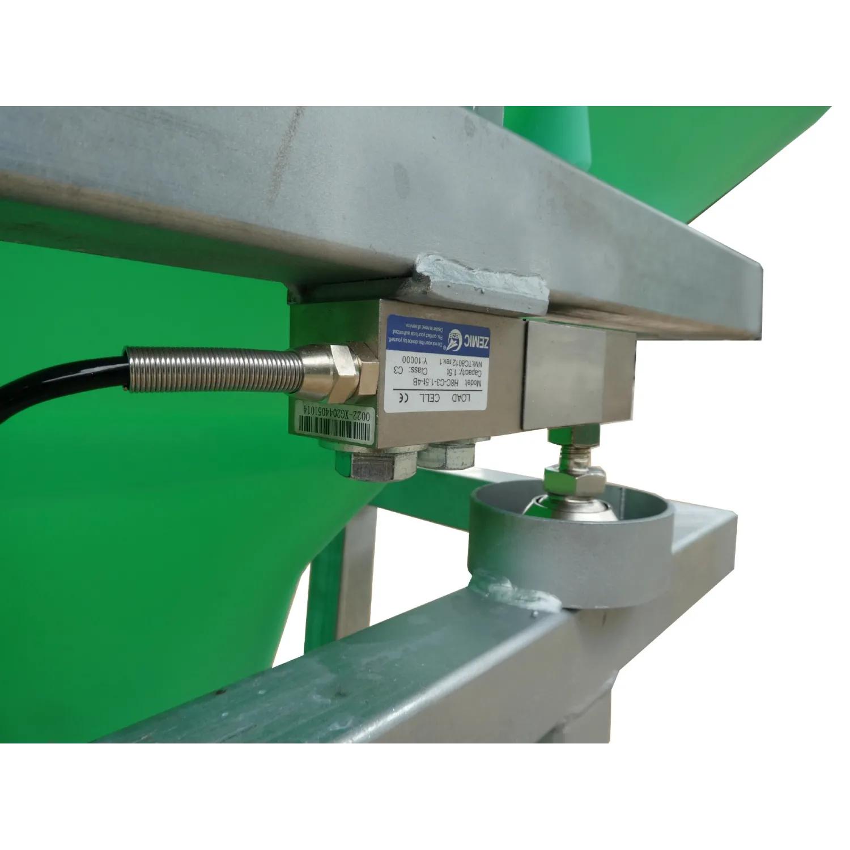
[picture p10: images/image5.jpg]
Reference 3
 — Tablet dashboard mockup showing inventory info, live graphs and a weekly inventory bar chart.

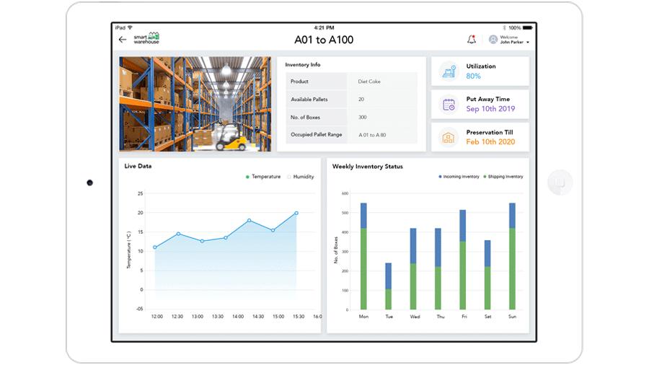
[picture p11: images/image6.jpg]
Reference 4
 — Warehouse shelving fitted with labeled bins and IoT gateway/sensor modules along the shelf rail.

---
[← Back to README → ](../README.md)

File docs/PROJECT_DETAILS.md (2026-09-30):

**Name:** Mydhily M R

## Members (maximum 8 members):

| S. No. | Name | Role / Contribution | Contact (Optional) |
|---|---|---|---|
| 1. | Mydhily | Team lead: hardware, MAX32630FTHR firmware, NodeMCU gateway, Firebase, dashboard, AI forecasting |  -<br>[-](mailto:-)<br>[-](mailto:-) |

## Project Checklist

**Phase 1**

| Item | Status |
|---|---|
| Project Title | **Done** |
| Cover Image | **Done** |
| List of Components | **Done** |
| Detailed Project Description | **Done** |
| Schematics | **Done** |
| Code | **Done** |
| CAD/ PCB Design If any *Optional | **Done** |
| Photo of project | **Done** |
| Video displaying working of Project | **Done** |
| BONUS/OPTIONAL: Video explaining working of the project | **Done** |

# PRISM — Predictive Replenishment & Inventory Stock Monitoring

**PRISM predicts what you're about to run out of, before you run out.**

## Cover Image:

Figure 1: Cover image – three PRISM units showing green, yellow and red stock levels

## Video:

**[https://youtu.be/odlPvgT5Zeg?si=Ek_2I9EwPxp-R_3K](https://youtu.be/odlPvgT5Zeg?si=Ek_2I9EwPxp-R_3K)**

## Component List:

DigiKey MyList (BOM): **[MyList link Click here](https://www.digikey.in/en/mylists/list/48SZ6VB09U)**

| Sl No | Name | Qty | Datasheet | Link |
|---|---|---|---|---|
| 1 | MAX32630 FTHR | 1 | [Datasheet Link](https://www.analog.com/media/en/technical-documentation/data-sheets/max32630fthr.pdf) | [Link to Buy](https://www.digikey.in/en/products/detail/analog-devices-inc-maxim-integrated/MAX32630FTHR/6575544) |
| 2 | Load Cell 5 Kg | 1 | [Datasheet Link](https://cdn.sparkfun.com/assets/e/5/f/5/6/TAL220B.pdf) | [Link to Buy](https://www.digikey.in/en/products/detail/sparkfun-electronics/14729/9555603) |
| 3 | HX711 BOARD | 1 | [Datasheet Link](https://mm.digikey.com/Volume0/opasdata/d220001/medias/docus/5858/333005%20Load%20cell%20amplifier%20HX711%20board%20datasheet.pdf) | [Link to Buy](https://www.digikey.in/en/products/detail/soldered-electronics/333005/21720457) |
| 4 | SSD1306 OLED Display 0.96" | 1 | Datasheet Link | Link to Buy |
| 5 | Ultrasonic Sensor | 1 | [Datasheet Link](https://www.digikey.in/en/products/detail/adafruit-industries-llc/3942/9658069) | [Link to Buy](https://mm.digikey.com/Volume0/opasdata/d220001/medias/docus/692/3942_Web.pdf) |
| 6 | Piezo Buzzer | 1 | Datasheet Link | Link to Buy |
| 7 | PIR Sensor | 1 | [Datasheet Link](https://mm.digikey.com/Volume0/opasdata/d220001/medias/docus/8924/ST0012%20%20%20HC-SR501%20Human%20Body%20Pyroelectricity%20Infrared%20Sensor%20Module.pdf) | [Link to Buy](https://www.digikey.in/en/products/detail/sunfounder/ST0012/22116811) |
| 8 | IR Sensor | 1 | Datasheet Link | Link to Buy |
| 9 | Dotted PCB | 1 | Datasheet Link | Link to Buy |
| 10 | Bread Board | 1 | [Datasheet Link](https://mm.digikey.com/Volume0/opasdata/d220001/medias/docus/2329/239_Web.pdf) | [Link to Buy](https://www.digikey.in/en/products/detail/adafruit-industries-llc/239/7244929) |
| 11 | Jumper Wires | | [Datasheet Link](https://mm.digikey.com/Volume0/opasdata/d220001/medias/docus/8913/100862.pdf) | [Link to Buy](https://www.digikey.in/en/products/detail/soldered-electronics/555033/29271434) |
| 12 | Glue Gun | 1 | Datasheet Link | Link to Buy |
| 13 | Soldering ion | 1 | Datasheet Link | Link to Buy |
| 14 | RYG LED | 14 | | |

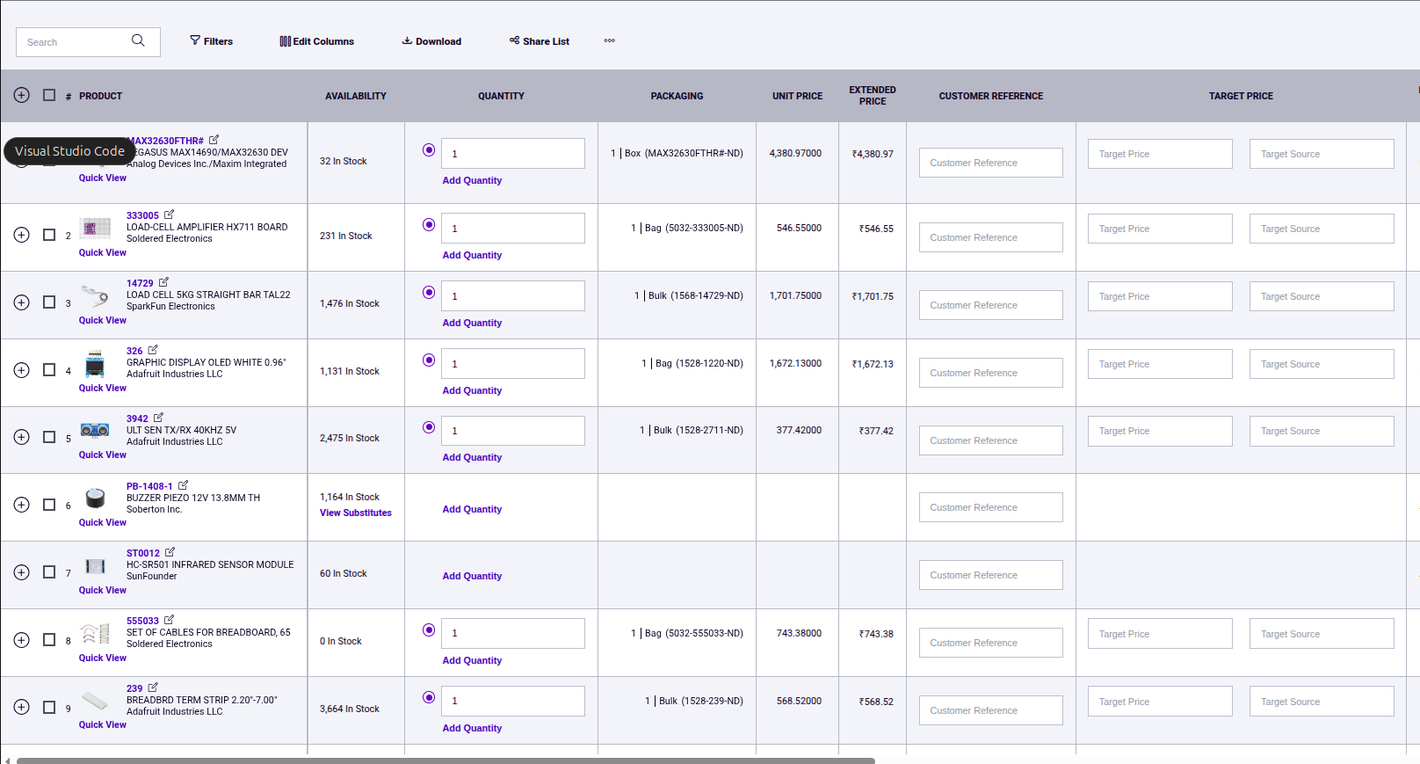
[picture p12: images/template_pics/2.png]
Figure 2: DigiKey MyList (BOM) – list of project components (https://www.digikey.in/en/mylists/list/48SZ6VB09U)


**Click on Any Product** To Open List

---

## Project Explanation Step By Step :

### Introduction

In a busy electronics lab or production floor, a small component bin can look fine until someone reaches for it and finds it empty. By then, the shortage has already become a problem.

**PRISM** turns an ordinary component bin into a smart inventory system that keeps track of what is actually inside it.The idea is simple: instead of waiting for a bin to become empty, PRISM tries to tell you that it is going to happen before it does.

PRISM is the result of that idea — **not just knowing how much stock is left, but knowing when we need to start worrying about what comes next.**

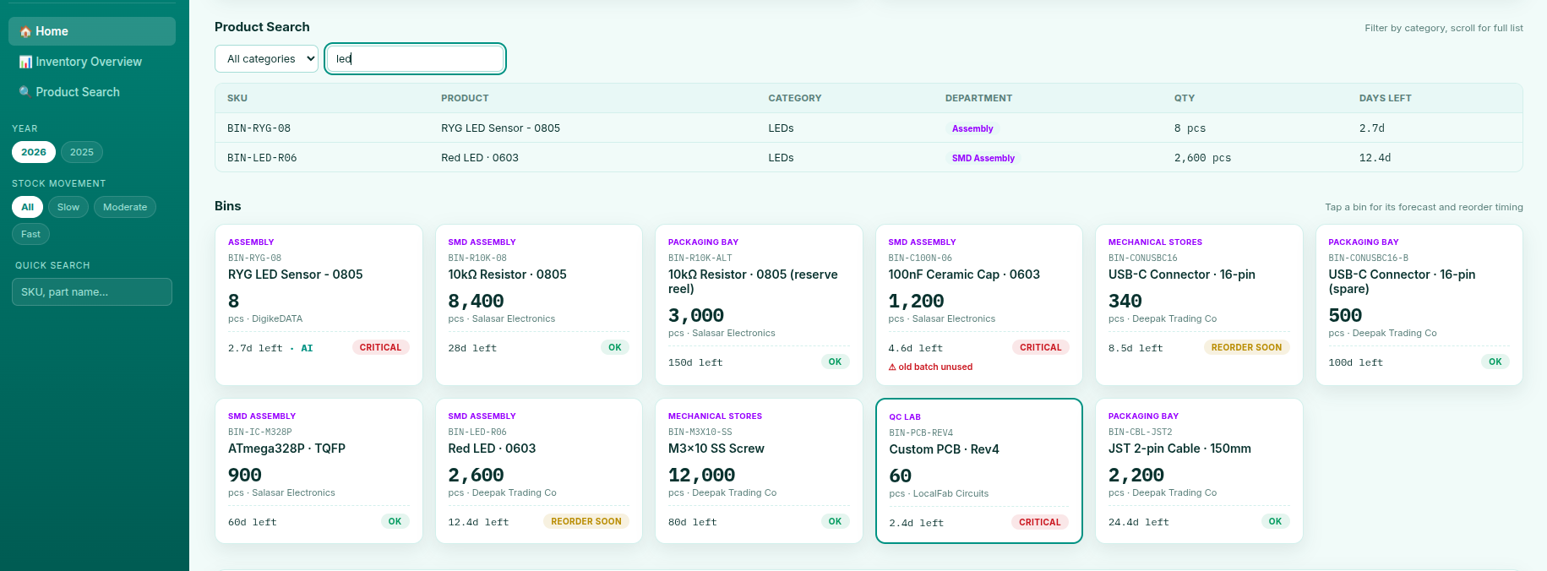
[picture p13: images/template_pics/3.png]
Figure 3: PRISM dashboard – product search and bin-wise stock view


### Inspiration - What leads to PRISM?

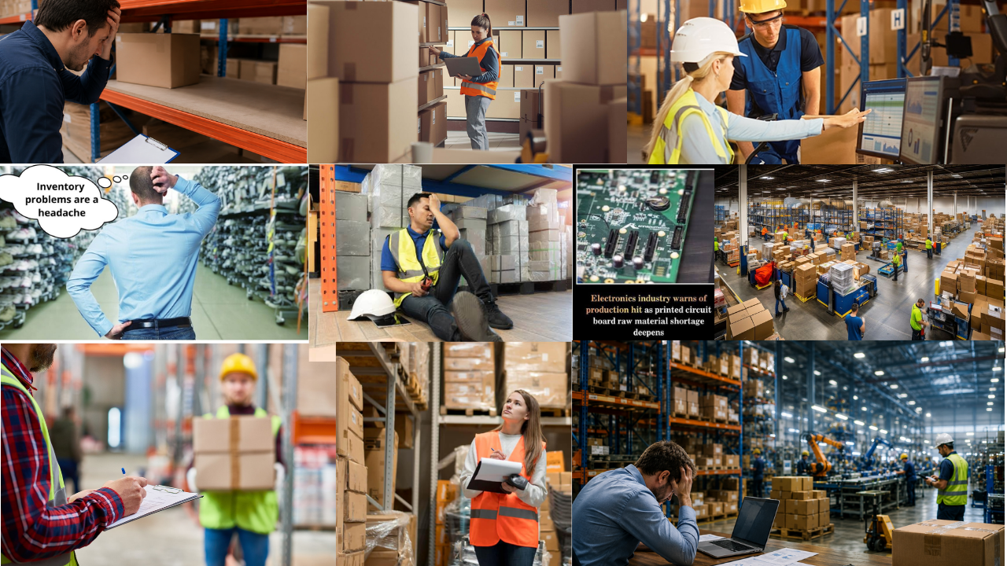
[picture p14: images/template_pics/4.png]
Figure 4: Inventory problems in manufacturing and production environments
 

I have faced this problem myself several times — needing a component for a project or a task, only to find out that the bin was empty or the required quantity wasn't available.

But when I started talking to colleagues working in different manufacturing and production environments, I realized this problem was much bigger than I had experienced.

I heard stories of production lines being stopped for an entire day because just **one small component was out of stock**. People would come to work, sit idle, and wait because the missing part hadn't been identified or replenished in time.

What surprised me was that this wasn't limited to electronics. Similar frustrations were being experienced by colleagues working in **mechanical, automotive, electronics, and other manufacturing industries**.

The problem wasn't always a lack of inventory management. The real problem was knowing **what is physically available right now — and when it is going to run out**.

That made me think:

**Why wait until a component is unavailable before we know there is a shortage?**

I wanted to build something that could continuously watch the physical stock, detect when components were being consumed, and warn us before a small shortage turns into a production stoppage.

That idea became **PRISM.**

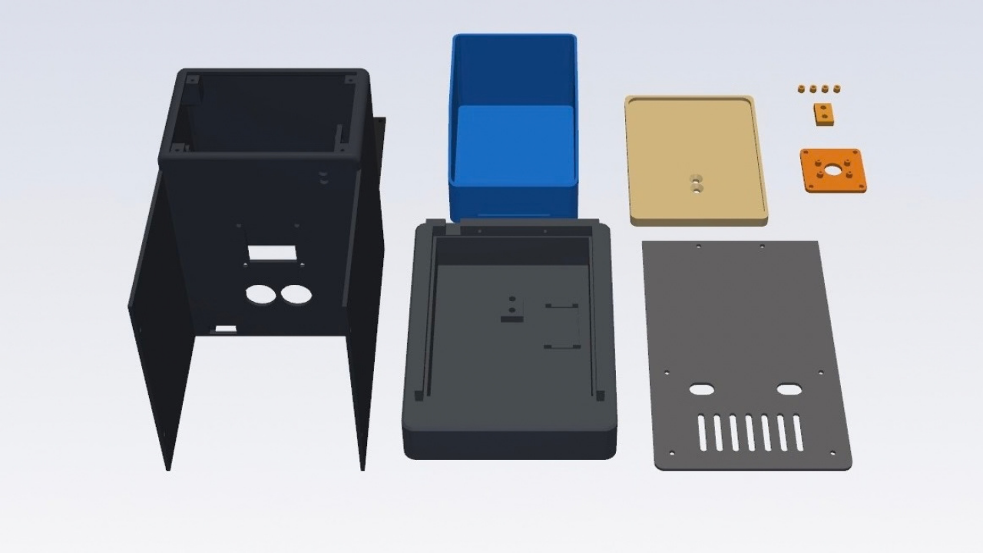
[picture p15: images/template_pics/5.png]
Figure 5: PRISM enclosure – exploded CAD view of all parts


### The Problem Statement

- **Counts are stale:** Stock is counted by hand or updated in a spreadsheet at the end of a shift, so the record never matches the shelf.
- **Systems track issues**, not what is left. Barcode and ERP entries record what was booked out, not what is physically in the bin.
- **Stock-outs are found too late**. A bin is discovered empty at the shelf, after the time to reorder has already passed.
- **Reorder points ignore real usage**. Fixed minimum levels do not follow the actual consumption rate or the supplier's real lead time.
- **Workers get no signal**. Nothing at the shelf tells the person picking parts that the bin is nearly empty.

### Existing Systems

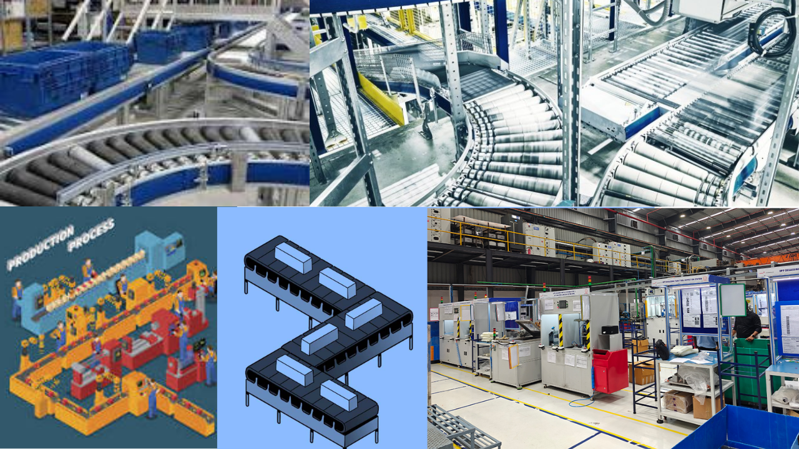
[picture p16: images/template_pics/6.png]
Figure 6: Existing systems – production lines, conveyors and manufacturing processes


**FIFO**

The components received first are used first. This helps prevent old or perishable components from remaining in inventory for too long.

**Kanban System**

Uses visual signals, such as cards or digital alerts, to indicate when components need to be replenished. It helps maintain the required stock level and avoid shortages.

**Lean Manufacturing**

Focuses on reducing waste, excess inventory, and unnecessary processes. The goal is to keep only the inventory needed for production.

**Six sigma**

Uses data and statistical methods to reduce errors and variations in processes. In inventory management, it can help improve demand forecasting and reduce inventory-related mistakes.

**Bulk Manufacturing**

Produces large quantities of products or components at once. This can reduce production costs but may lead to excess inventory if demand is not accurately predicted.

## The PRISM-Overview

### What Makes PRISM Different?

Instead of relying on manual stock checks or simply recording what components were issued, PRISM monitors the physical stock inside the bin itself. A load cell continuously measures the weight of the contents and estimates the number of components remaining, while an IR sensor helps identify when parts are picked. Local LEDs, an OLED display, and a buzzer provide immediate feedback to the person working at the shelf.

But PRISM doesn't stop at knowing what is available right now.

The bin sends its readings through a Wi-Fi gateway to Firebase, where the inventory can be monitored through a web dashboard. The system tracks the consumption trend and uses it to estimate how many days are left before the stock runs out.

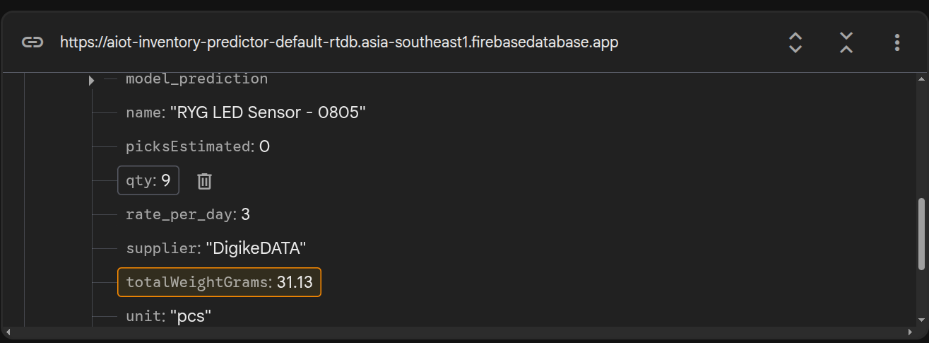
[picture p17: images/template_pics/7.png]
Figure 7: Firebase Realtime Database – model prediction data for the RYG LED bin


This means the system can move from simply saying "this bin is low" to giving the team an early warning that "this bin is going to run out soon."

The goal is simple: instead of discovering a shortage when someone needs the last component, PRISM gives workers, stock managers, and purchasing teams time to react before that shortage becomes a production problem.

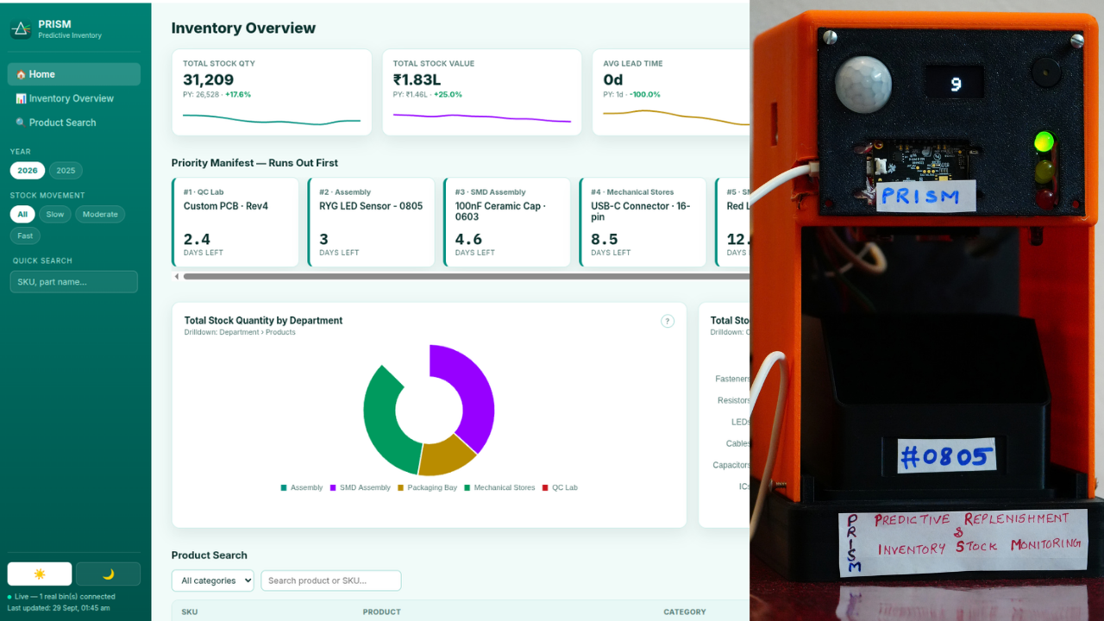
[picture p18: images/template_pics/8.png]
Figure 8: Inventory Overview dashboard alongside the PRISM node


### What PRISM does

PRISM serves three people from one bin:

| **Who** | **What they get** | **Built with** |
|---|---|---|
| Worker at the shelf | Live piece count with a + / − change marker, a green / yellow / red stock light, and a 10-second buzzer when stock falls to 20% | MAX32630FTHR, load cell, OLED, RYG LED, buzzer |
| Stock manager | A live dashboard: stock KPIs, bins ranked by which runs out first, forecast chart per bin, reorder timing against supplier lead time, shipments and FIFO checks | Firebase + web dashboard |
| Purchasing | Days-to-empty learned from each bin's consumption trend, plus an email / WhatsApp alert when a bin drops inside its lead time | Python regression model |

Figure 9: PRISM concept – manager input & control panel, smart tray on production line, and strategic manager dashboard

### What makes it different

**Counts by weight.** No scan per pick: the bin knows its own count at all times.

**Sensor fusion for picks**. The IR sensor sees a hand enter; the weight drop after the hand leaves says how many pieces were taken.

**Forecasts learned from data.** Reorder timing comes from the measured depletion trend, not a fixed minimum level.

**Alerts work offline**. The LED, OLED and buzzer run on the MAX32630FTHR itself, so the shelf still warns the worker if Wi-Fi drops.

**One protocol for any bin.** Each bin's identity lives on the device; the gateway is a generic relay, so a new bin needs only a new `binId` .

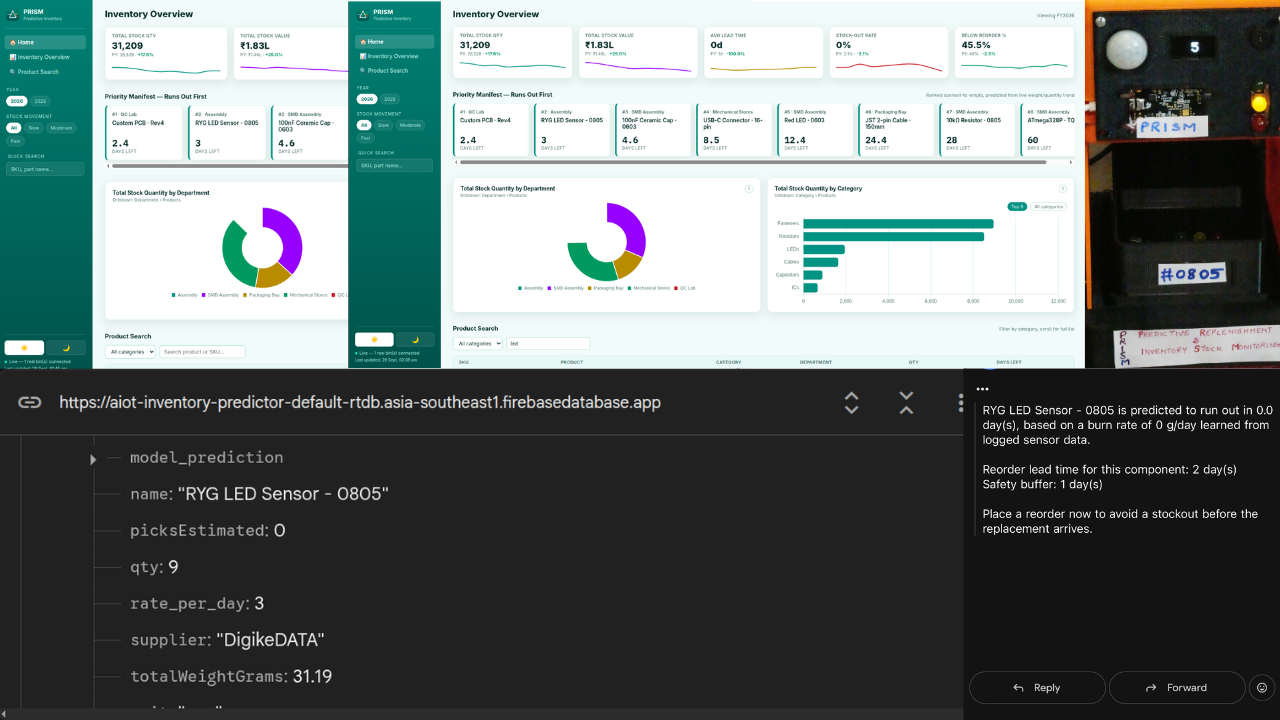
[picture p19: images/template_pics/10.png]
Figure 10: Dashboard, Firebase data and email alert – complete PRISM output view


### How PRISM Works: Complete Flow

A load cell under the bin counts components in real time on an Analog Devices MAX32630FTHR, an IR sensor and the weight drop together estimate each pick, and a red/yellow/green LED, OLED and buzzer tell the worker the stock level right at the shelf. Readings flow through a NodeMCU Wi-Fi gateway into Firebase, where a web dashboard gives the stock manager a live view and a machine-learning model forecasts days-to-empty for every bin.

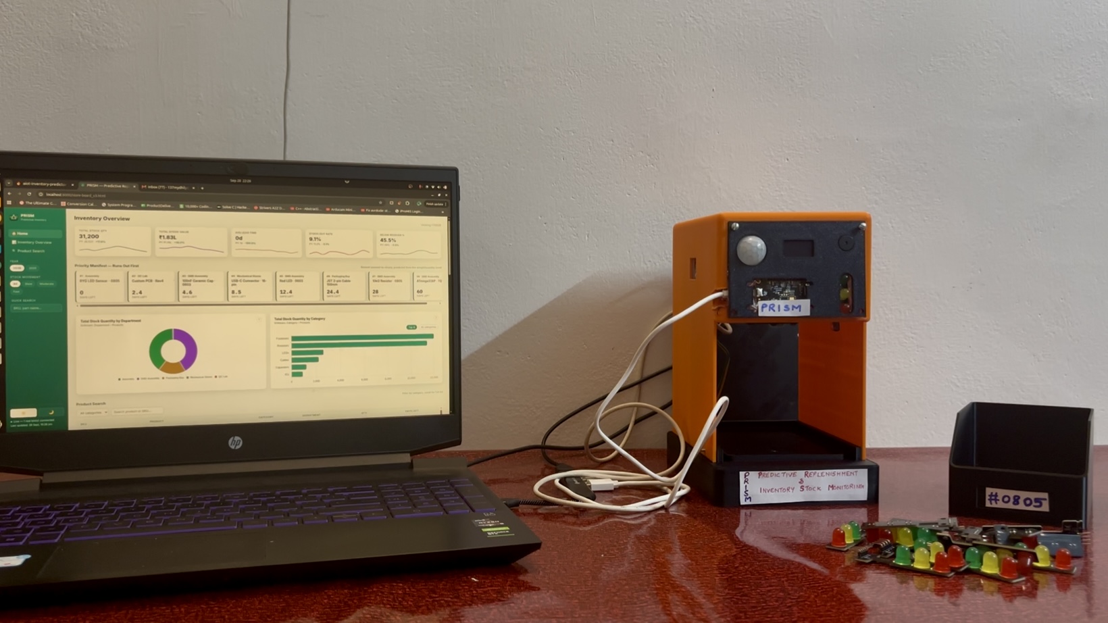
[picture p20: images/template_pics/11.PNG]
Figure 11: PRISM node with the inventory dashboard running on a laptop


### Why did I build this?

This project started with a simple question: **why do we only realize that a component bin is empty when we actually need something from it?**

In an electronics lab, storeroom, or production floor, hundreds of small components can sit quietly in storage bins. The problem is that the stock inside those bins keeps changing, while the inventory record often doesn't. Someone takes a few components, another person takes a few more, and eventually the bin is empty — usually when someone needs that exact part.

I wanted to build something that could actually keep an eye on the bin.

PRISM turns an ordinary component storage bin into a smart inventory node. It uses weight sensing to estimate how many components are left, detects when parts are picked, and gives an immediate indication of the stock level using an RGB LED, OLED display and buzzer. The data is also sent to the cloud so the inventory can be monitored remotely.

But I didn't want PRISM to simply tell me "the bin is almost empty." I wanted it to answer a more useful question:

**"When is this bin going to become empty?"**

That's where the prediction part comes in. PRISM analyses the consumption trend and **estimates the number of days remaining before the stock runs out,** giving enough time to plan a reorder instead of discovering the shortage at the last moment.

This project has been a journey of sensors, wiring, calibration, firmware, debugging, failed experiments, and plenty of moments where something worked perfectly one minute and completely refused to work the next.

It is not a polished commercial product. It is a real working prototype that I built to explore how embedded systems, IoT, cloud monitoring and machine learning can come together to solve a very ordinary but very real problem.

So, this is the story of PRISM — a bin that doesn't just store components, but keeps track of them and tries to warn you before they run out.

Let's dive into how PRISM was built.

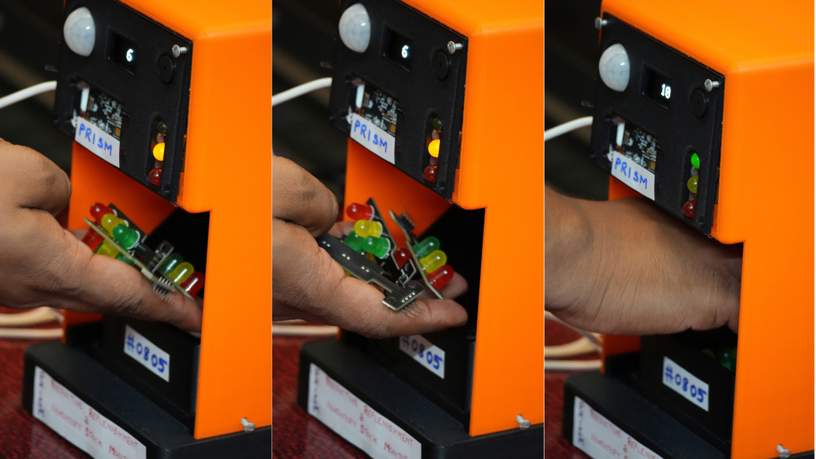
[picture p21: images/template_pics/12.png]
Figure 12: Worker picking RYG LEDs from the PRISM bin


### Components Required

DigiKey MyList (BOM): **[MyList link Click here](https://www.digikey.in/en/mylists/list/48SZ6VB09U)**

| Sl No | Name | Qty | Datasheet | Link |
|---|---|---|---|---|
| 1 | MAX32630 FTHR | 1 | [Datasheet Link](https://www.analog.com/media/en/technical-documentation/data-sheets/max32630fthr.pdf) | [Link to Buy](https://www.digikey.in/en/products/detail/analog-devices-inc-maxim-integrated/MAX32630FTHR/6575544) |
| 2 | Load Cell 5 Kg | 1 | [Datasheet Link](https://cdn.sparkfun.com/assets/e/5/f/5/6/TAL220B.pdf) | [Link to Buy](https://www.digikey.in/en/products/detail/sparkfun-electronics/14729/9555603) |
| 3 | HX711 BOARD | 1 | [Datasheet Link](https://mm.digikey.com/Volume0/opasdata/d220001/medias/docus/5858/333005%20Load%20cell%20amplifier%20HX711%20board%20datasheet.pdf) | [Link to Buy](https://www.digikey.in/en/products/detail/soldered-electronics/333005/21720457) |
| 4 | SSD1306 OLED Display 0.96" | 1 | Datasheet Link | Link to Buy |
| 5 | Ultrasonic Sensor | | [Datasheet Link](https://www.digikey.in/en/products/detail/adafruit-industries-llc/3942/9658069) | [Link to Buy](https://mm.digikey.com/Volume0/opasdata/d220001/medias/docus/692/3942_Web.pdf) |
| 6 | Piezo Buzzer | | Datasheet Link | Link to Buy |
| 7 | PIR Sensor | | [Datasheet Link](https://mm.digikey.com/Volume0/opasdata/d220001/medias/docus/8924/ST0012%20%20%20HC-SR501%20Human%20Body%20Pyroelectricity%20Infrared%20Sensor%20Module.pdf) | [Link to Buy](https://www.digikey.in/en/products/detail/sunfounder/ST0012/22116811) |
| 8 | IR Sensor | | Datasheet Link | Link to Buy |
| 9 | Dotted PCB | | Datasheet Link | Link to Buy |
| 10 | Bread Board | | [Datasheet Link](https://mm.digikey.com/Volume0/opasdata/d220001/medias/docus/2329/239_Web.pdf) | [Link to Buy](https://www.digikey.in/en/products/detail/adafruit-industries-llc/239/7244929) |
| 11 | Jumper Wires | | [Datasheet Link](https://mm.digikey.com/Volume0/opasdata/d220001/medias/docus/8913/100862.pdf) | [Link to Buy](https://www.digikey.in/en/products/detail/soldered-electronics/555033/29271434) |
| 12 | Glue Gun | | Datasheet Link | Link to Buy |
| 13 | Soldering ion | | Datasheet Link | Link to Buy |

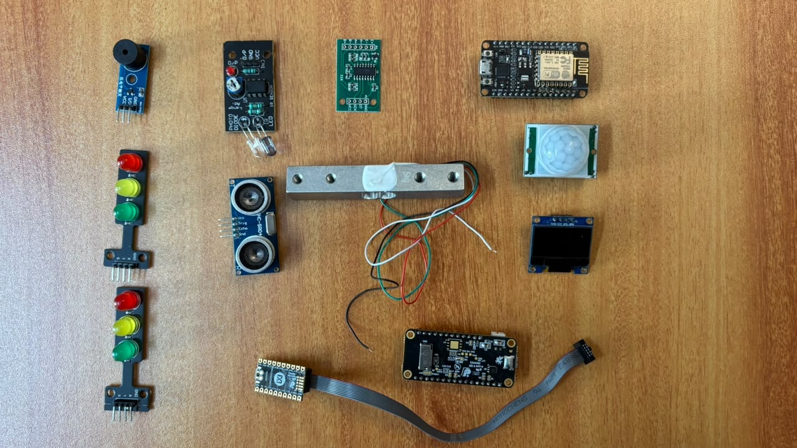
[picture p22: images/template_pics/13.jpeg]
Figure 13: All components used in PRISM laid out


## Step 1: MAX32630 FTHR Board Set up

The development board and programming cable are provided separately. The initial board setup and programming steps were completed by following the official DAPLink documentation.

Reference: [https://daplink.io/](https://daplink.io/)

**Connections:**

Ribbon cable orientation — the cable has a colored stripe on one edge (marking pin 1).

It looks seated straight into both headers, but it's worth double-checking that the stripe lines up with the pin-1 marking (usually a small triangle, dot, or square pad) on both the PICO's connector and the target's header.

A cable seated backward or offset by one pin is a classic cause of exactly this "board not found" symptom, since the boards will still power up fine but SWD communication will fail.

Give the MCU board its own power The MAX32625PICO cannot supply power to every target board through the debug header alone. If your MCU is only powered through the PICO connection (rather than its own USB/power cable), connect a separate powered USB cable directly to the MCU board as well, so both boards are independently powered during programming.

**On Windows11 PC:**

Download the firmware file.

While holding down the boards reset button, connect the boards USB debug port to the computer. It should enumerate and mount as BOOTLOADER or MAINTENANCE. For boards that enumerate as BOOTLOADER see our blog to determine if an update for the DAPLink bootloader is available.

Drag-and-drop the firmware file onto the mounted drive. Wait for the file copy operation to complete.

Power cycle the board - Disconnect the USB cable from the board to remove power, then reconnect it normally without holding any buttons.

It will now enumerate and mount as DAPLIN or the name of the board.

Windows has removed the wmic command, and the older Maxim daplink tool, so try the below method:

**Export the compiled binary**

In Arduino IDE, go to Sketch → Export Compiled Binary. This saves the .bin file into your sketch's own folder permanently, instead of a temp folder that gets wiped — open the sketch folder afterward (Sketch → Show Sketch Folder) and you'll see it there.

**Open the DAPLINK drive**

Open File Explorer and confirm the DAPLINK drive is mounted (it should show a drive letter next to the label DAPLINK, alongside DETAILS.TXT).

**Copy the .bin file onto the DAPLINK drive**

Simply drag the exported .bin file from your sketch folder and drop it onto the DAPLINK drive, just like copying a file to a USB stick. The drive will briefly disappear and remount as it flashes the firmware.

**Check for success**

If something went wrong, a FAIL.TXT file will appear on the drive explaining why. If it succeeds, the board will reset and your Blink sketch should start running — with Auto Reset enabled on your board, this happens automatically.

**Note:**

Even though I flashed the board using Windows 11 PC, later I switched to Ubuntu 20.04 LTS, because driver support was limited in Windows.

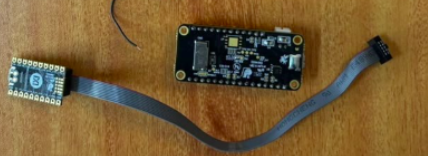
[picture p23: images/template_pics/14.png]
Figure 14: MAX32630FTHR board connected to the MAX32625PICO debug adapter with ribbon cable


## Step 2: MAX32630 FTHR Board Installation in Arduino IDE

MAX32630 board Pin Diagram

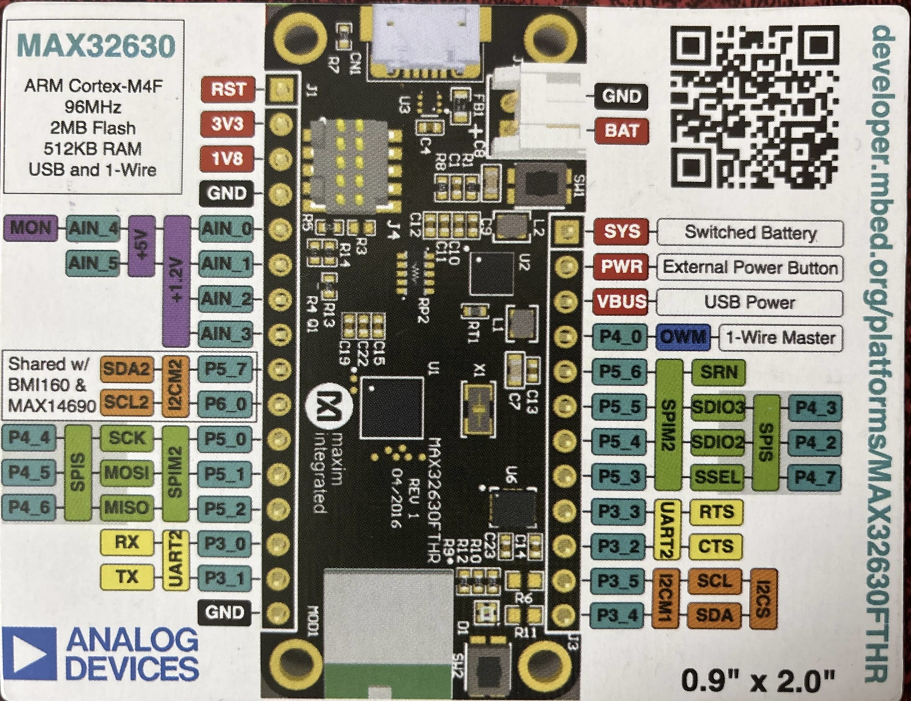
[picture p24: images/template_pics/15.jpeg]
Figure 15: MAX32630FTHR pin diagram


**1. Install MAX32630FTHR board on Ubuntu**

To install the MAX32630 (such as the MAX32630FTHR) board in the Arduino IDE, add Maxim's JSON package URL to your preferences and install the board via the Boards Manager.

Add Maxim's JSON URL:

[https://raw.githubusercontent.com/analogdevicesinc/arduino-max326xx/master/package_maxim_index.json](https://raw.githubusercontent.com/analogdevicesinc/arduino-max326xx/master/package_maxim_index.json)

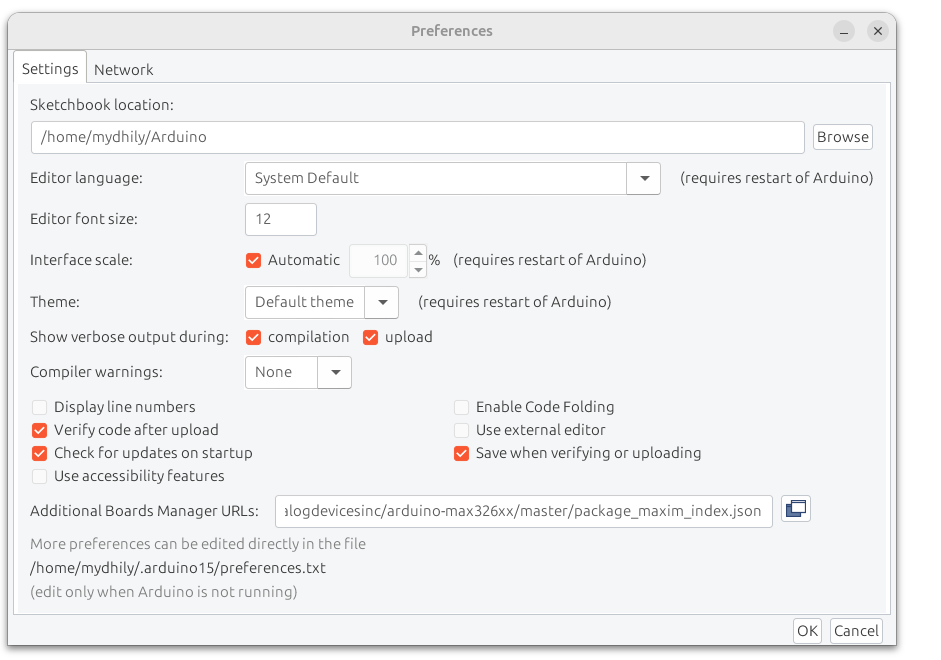
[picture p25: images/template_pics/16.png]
Figure 16: Arduino IDE Preferences – Additional Boards Manager URL added


Add Maxim's JSON URL in **File --> Preferences** and click **OK**.

Then, open the Boards Manager via **Tools > Board**, search for maxim, and install Maxim's 32-bit Microcontroller

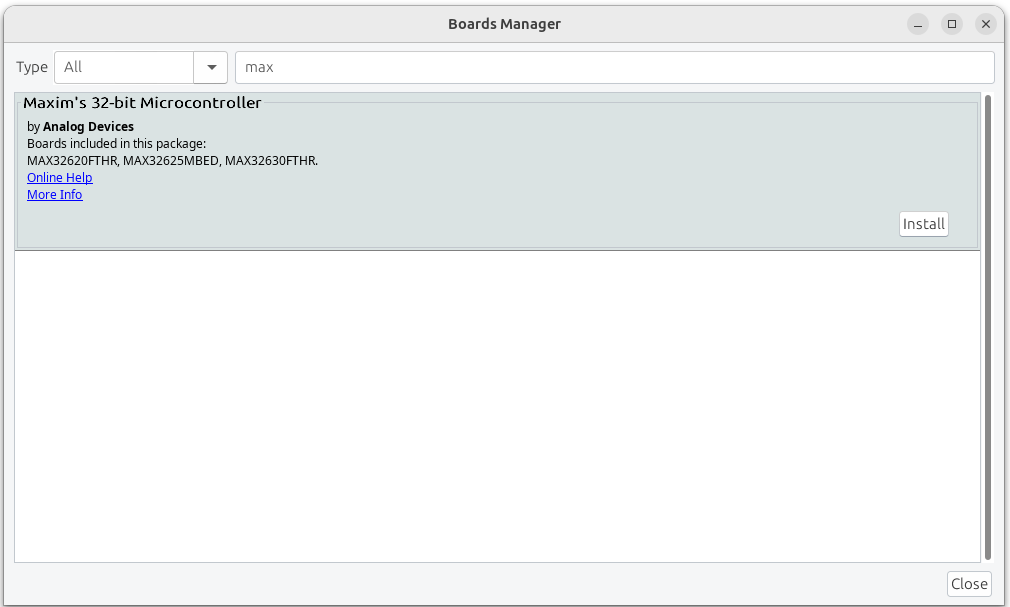
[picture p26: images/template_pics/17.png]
Figure 17: Arduino Boards Manager – installing Maxim's 32-bit Microcontroller package


After installation, select MAX32630FTHR under Tools > Board, choose your connected board's serial port in Tools > Port, and set the programmer to DAPLink under Tools > Programmer.

Now connect the PICO and Board both to your PC.

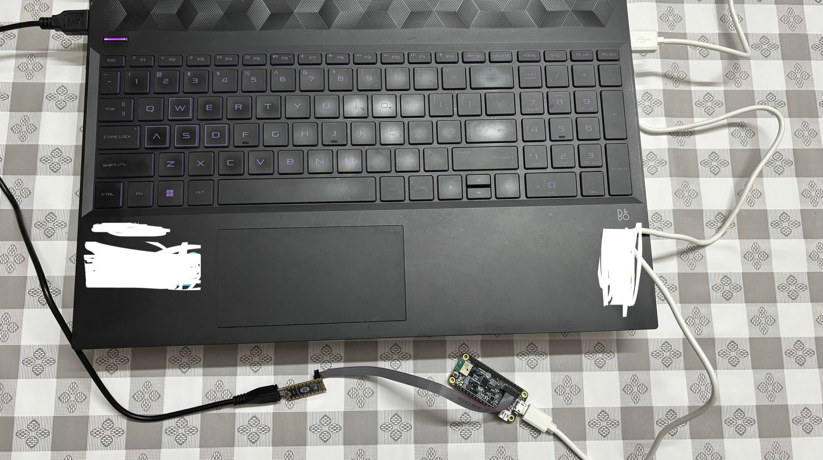
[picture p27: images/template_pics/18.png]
Figure 18: MAX32625PICO and MAX32630FTHR connected to the PC


Now try the first program to test the board is OK or not, a simple hello world as shown in the example will be fine.

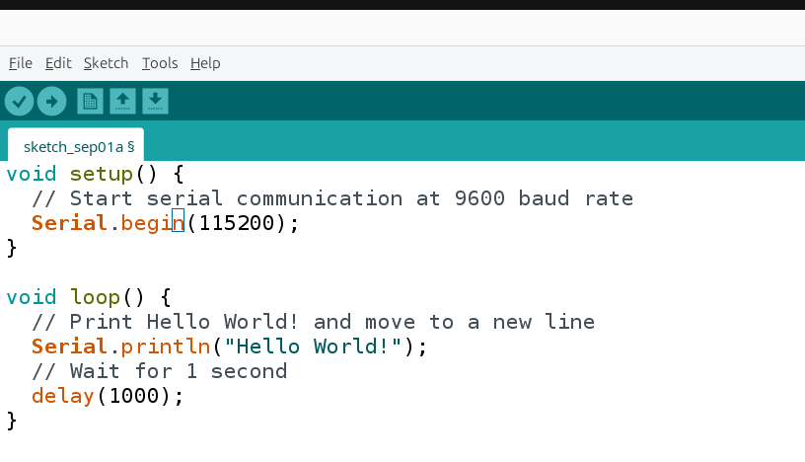
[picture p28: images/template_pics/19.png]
Figure 19: Hello World test sketch in Arduino IDE


Select Board as MAX32630FTHR , Port /dev/ttyACM0, Programmer DAPLINK , then open Serial Monitor, Select baud rate as 115200.

Click on Upload to upload the program and observe the output in the serial monitor.

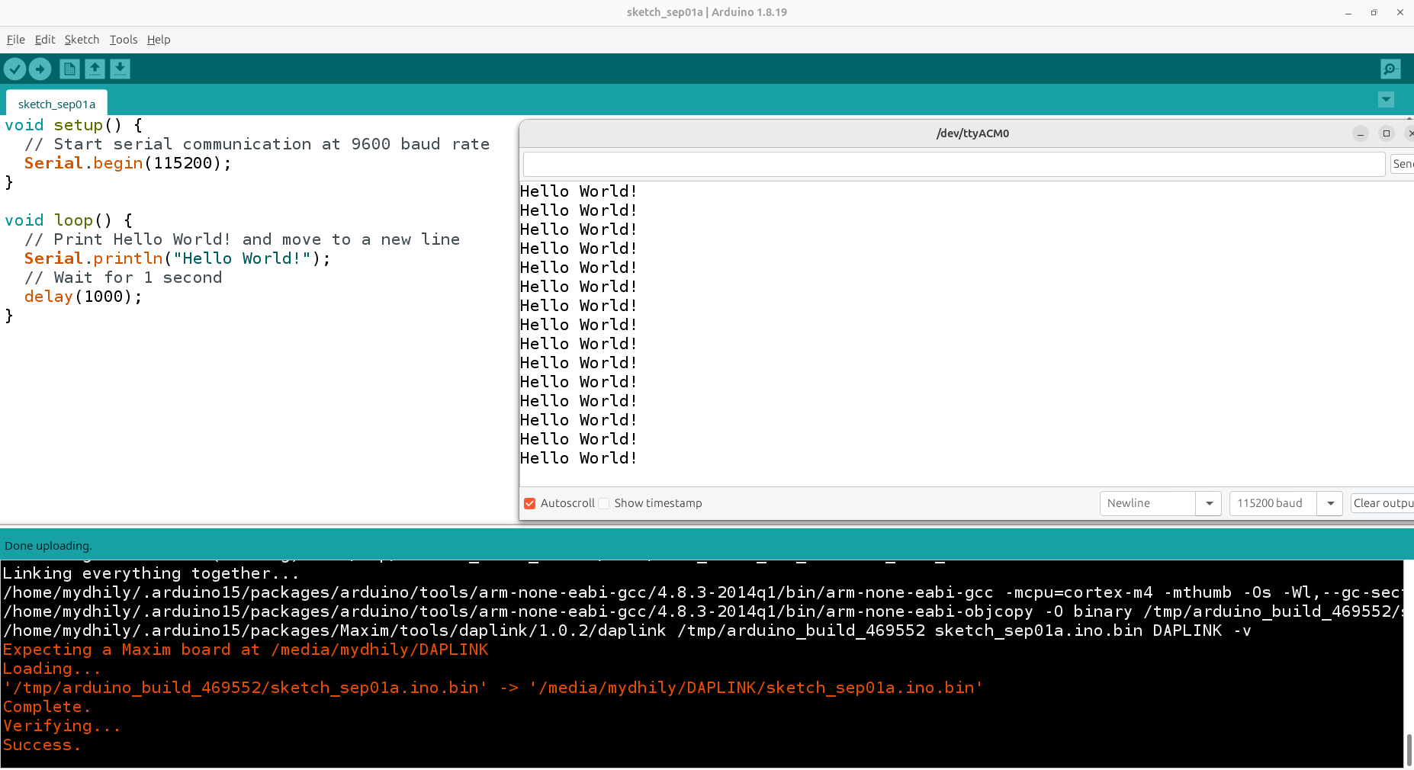
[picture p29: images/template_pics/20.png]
Figure 20: Successful upload and "Hello World" output in the Serial Monitor


If the steps till above work, Congarts!!!! Now you can start using the MAX32630 board with other examples or sensors you are going to use.

## Step 3: Individual Sensor Testing

After installing the MAX32630 and successfully running the Hello World example, I moved on to testing each sensor individually before starting the complete system integration. The detailed testing procedures, schematics, and pin connections for each sensor are documented on my GitHub page and can be referred to for reproducing the setup.

**Github repo:** **[Documentation](https://github.com/mydhily-mr/aiot-inventory-predictor/tree/main/docs)**

Individual sensor testing became the single most time-consuming phase of the project and had a major impact on the overall project timeline. Nearly half of my total project time was consumed by getting the individual sensors to work reliably. What I initially expected to be a relatively short validation stage turned into an extended debugging process, with different hardware and software issues appearing with different peripherals.

For example, In Wi-Fi communication, I used UART and encountered clock-related and power related issues when working with different baud rates. The OLED display introduced another major challenge because of compatibility issues in the Wire library. I had to investigate the Wire driver, identify the issue, and modify the library to get the OLED working correctly with my setup. Since the issue appeared to be related to the MAX32630 Arduino environment, I also attempted to contribute my fix to the official MAX32630 Arduino repository.

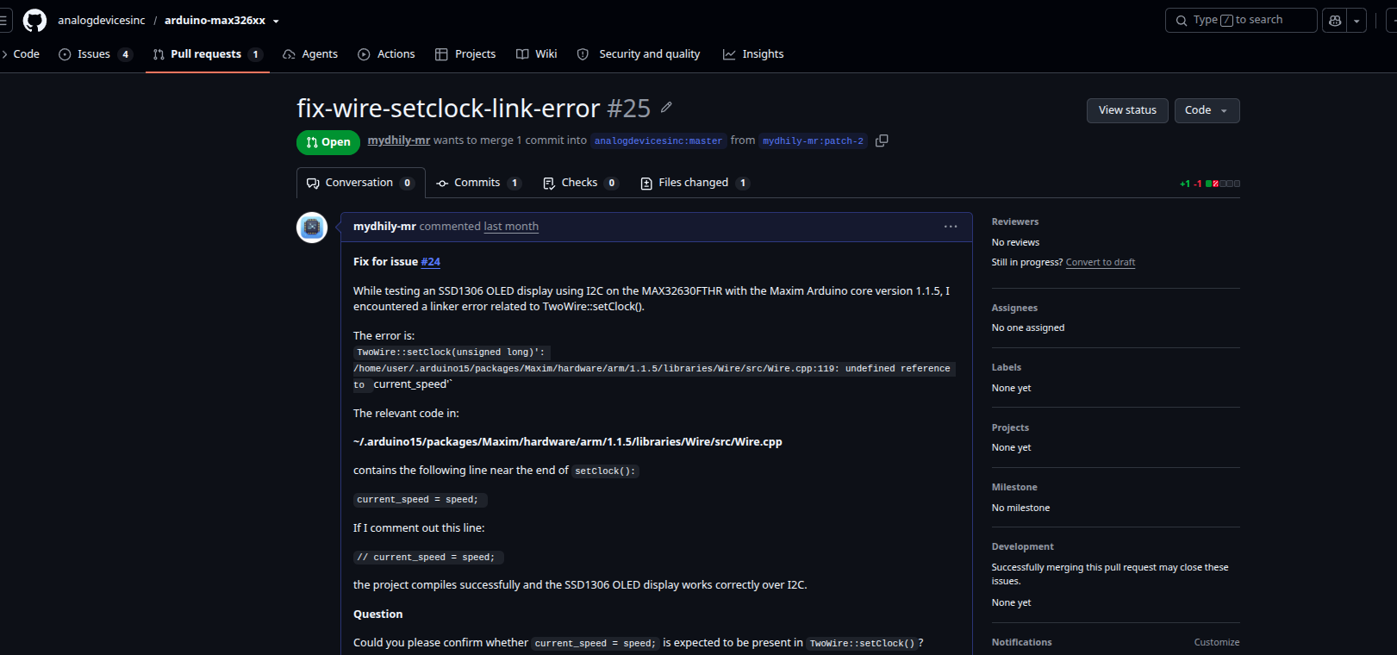
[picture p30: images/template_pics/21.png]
Figure 21: Pull request "fix-wire-setclock-link-error" submitted to the official MAX32630 Arduino repository


Although I am not completely certain that my modification is the correct or final solution for all configurations, it resolved the issue in my setup, and I submitted the changes to the official repository so that the issue and potential fix could be reviewed by the maintainers. I also documented the issue and my changes on the relevant official project page.

Figure 22: OLED display test showing "Hello World"

<!-- ![Figure 23: RYG LED test setup on breadboard](../images/template_pics/23.jpeg) -->

RYG LED Demonstration

This debugging phase significantly reduced the time available for the remaining stages of the project. Tasks that were originally planned for system integration and higher-level functionality had to be pushed later because the individual components first had to be made stable. In practical terms, almost half of the project schedule was spent not on building the final system, but on making the individual sensors and their supporting libraries work correctly with the MAX32630.

Despite this setback, I eventually got all the individual sensors working successfully. More importantly, the process gave me a much better understanding of the MAX32630 platform, its peripheral interfaces, clock configuration, and the challenges involved in adapting existing Arduino libraries to a new hardware platform. Once the individual components were validated, I could proceed with system integration on a much more stable foundation.

Figure 24: Individual sensor testing – ultrasonic sensor, RYG LED and load cell setup

Figure 25: Individual sensor testing – breadboard setup 1

Figure 26: Individual sensor testing – breadboard setup 2

Figure 27: Individual sensor testing – breadboard setup 3

Figure 28: Individual sensor testing – breadboard setup with OLED

Figure 29: Individual sensor testing – breadboard setup with Wi-Fi module

**Note: Individual Sensor Testing**

The detailed procedures and results for individual sensor testing are documented in the project's GitHub repository under the Documentation (docs) section. I have not reproduced the complete testing procedures here to avoid duplicating the documentation.

The GitHub documentation includes the required setup, wiring details, testing procedure, and verification steps for each sensor. Anyone who wants to reproduce or verify the individual sensor tests can refer to the documentation and follow the steps provided there.

**GitHub Documentation**: [Documentation](https://github.com/mydhily-mr/aiot-inventory-predictor/tree/main/docs)

## Step 4: Design the Enclosure in Fusion 360

Figure 30: Enclosure parts designed in Fusion 360

Once the individual sensor testing was completed and the components were working reliably, I moved on to the hardware design phase. At this point, I had only about two weeks remaining, so completing both the PCB design and the 3D-printed enclosure within the available time was a significant challenge, especially since I did not have much experience with either PCB design or CAD-based mechanical design.

Because of this limited timeline, I made a deliberate decision to use a zero-PCB approach for the prototype. Instead of spending the remaining time designing, fabricating, and debugging a custom PCB, I kept the tested modules and sensors as separate components and focused on getting them mechanically integrated into the prototype. This allowed me to prioritize the core functionality of the system and use the remaining time for CAD design, assembly, and system integration.

The CAD design itself required several iterations. Inventory management systems are generally deployed at a much larger scale in industrial environments, so I wanted the prototype to demonstrate the same underlying concept while keeping the physical implementation small enough for a practical demonstration.

Figure 31: CAD design iterations in Fusion 360

Figure 32: Hand-annotated enclosure layout and CAD model

In a typical production environment, every component would move through a defined production or conveyor line, with the inventory management system positioned along this flow. Based on this concept, I decided to place my system at the entry and exit points of the production line, so that every item would pass through the system for detection and inventory tracking, similar in concept to how passengers pass through a scanner at a metro station.

Figure 33: CAD model with component placement – front and section views

For the prototype, I scaled this concept down to a single compact system with a storage bin that fits within the enclosure. This allowed me to demonstrate the core inventory management workflow on a smaller scale while retaining the basic concept of how the system could be expanded for a larger industrial setup.

Figure 34: 3D-printed enclosure – front, back and inner views

For the CAD design, I searched the GrabCAD library for 3D models of each individual sensor and component used in the system. I then imported the relevant models and integrated them into my overall enclosure design. After positioning and aligning each component based on the actual hardware dimensions and mounting requirements, I assembled and refined the complete CAD model to create the final prototype design.

Figure 35: 3D-printed enclosure parts

### Enclosure Features

The enclosure is made up of multiple parts:

**Main Body** – Houses the main controller board and sensor modules, with dedicated cutouts for the Type-C port, display, RYG LED indicators, and piezo buzzer. A central opening provides access to the main board and simplifies installation and maintenance.

**Sensor Base** – Provides a dedicated mounting area for the HX711 module and load cell, allowing the weight-sensing mechanism to be securely integrated into the enclosure.

**Top Cover** – Provides a mounting surface for the IR sensor, ultrasonic sensor, positioned to face downward into the storage box for monitoring and inventory detection.

**Mounting & Fastening** – The enclosure is designed with mounting provisions to keep the internal components securely positioned and allow the complete node to be installed on the intended storage box.

**3D-Printed Construction** – The enclosure was fabricated using 3D printing based on the custom CAD design, allowing the dimensions and component cutouts to be tailored to the actual hardware.

Figure 36: Assembled 3D-printed enclosure – front, back and side views

## Step 5: Hardware Assembly

After finalizing the CAD design, I sent the design files to a nearby 3D printing service and received the printed enclosure. With the mechanical structure ready, I could finally move on to integrating the sensor modules and communication hardware that had already been tested individually.

The next step was to carefully solder the required components and establish reliable electrical connections. The components that needed to be soldered included the RYG LED, piezo buzzer, HX711 module with the load cell, and other required sensor and communication connections. The soldering had to be done carefully, particularly because the available space inside the enclosure was limited and the components had to be positioned without interfering with one another.

Figure 37: Handwritten pin connection notes

**Pin Connections:**

#### load cell + HX711

| Load Cell | HX711 |
|---|---|
| Red Wire | E+ |
| Black Wire | E- |
| Green Wire | A+ |
| White Wire | A- |

#### HX711 + MAX32630FTHR

| HX711 pin | MAX32630FTHR |
|---|---|
| VCC | 3.3 V |
| GND | GND |
| DOUT | P5_5 (pin 45 in software) |
| SCK | P5_4 (pin 44 in software) |

#### Wi-Fi + MAX32630FTHR

| ESP Wi-Fi | MAX32630FTHR |
|---|---|
| GND | GND |
| D7 (RX) | P3_1 (TX) |
| D8 (TX) | P3_0 (RX) |

#### SSD1306 OLED Display + MAX32630FTHR

| OLED | MAX32630FTHR |
|---|---|
| VCC | 3V3 |
| GND | GND |
| SDA | P3_4 |
| SCL | P3_5 |

#### HCSR-04 Ultrasonic Sensor + MAX32630FTHR

| Ultrasonic | MAX32630FTHR |
|---|---|
| VCC | 3V3 |
| GND | GND |
| TRIG | P5_6 |
| ECHO | P4_0 |

#### RYG LED + MAX32630FTHR

| RYG | MAX32630FTHR |
|---|---|
| GND | GND |
| R | P5_0 |
| Y | P5_1 |
| G | P5_2 |

#### Piezo Buzzer + MAX32630FTHR

| OLED | MAX32630FTHR |
|---|---|
| VCC | 3V3 |
| GND | GND |
| SIG | P5_3 |

#### IR Sensor + MAX32630FTHR

| IR | MAX32630FTHR |
|---|---|
| VCC | 3V3 |
| GND | GND |
| O/P | P3_3 |

#### PIR Sensor + MAX32630FTHR

| PIR | MAX32630FTHR |
|---|---|
| VCC | 3V3 |
| GND | GND |
| OUT | 1K resistor one end |
| 1K resistor junction | P3_2 |
| 1K resistor other end | GND |

**Schematics:**

Figure 38: PRISM circuit schematic

**Soldering Preparation**

Before starting the assembly, I prepared a clean and static-free workspace. The soldering iron was heated to approximately 350 °C for leaded solder or 370–380 °C for lead-free solder. Tweezers and flux were kept ready to handle the smaller pins and make the soldering process more precise.

<!--![Figure 39: Soldering the components](../images/template_pics/39.png) -->

Soldering the components

Soldering wire connections

<!-- ![Figure 40: Soldering wire connections](../images/template_pics/40.png) -->

**Continuity Testing**

After soldering each module, I performed a continuity test using a multimeter in continuity mode. I checked the connection between each module pin and its corresponding PCB pad or trace. A beep or near-zero resistance indicated that the connection was electrically continuous and properly soldered.

Soldering wire connections

Performing the continuity test after each component helped identify wiring or soldering problems early, before proceeding with the complete system integration.

Figure 41: Load cell and HX711 wired inside the sensor base

Figure 42: Sensor base with HX711 module and load cell

Soldering wire connections

<!-- ![Figure 43: Fixing components in the sensor base using a glue gun](../images/template_pics/43.png) -->

## Step 6: Build Process

The build process came together over an intense 2 days of designing, 3D printing, soldering, testing, and troubleshooting. I started by fabricating the custom enclosure and then gradually integrated the sensor modules, communication hardware, indicators, buzzer, and weight-sensing components into the case.

Figure 44: Front panel with OLED display mounted

Figure 45: MAX32630FTHR and PIR sensor mounted on the front panel

Figure 46: Sensor base and front panel modules during assembly

Figure 47: Workbench during build – Zero PCB wiring and pin notes

Figure 48: Enclosure frame with wiring in progress 

<!-- ![Enclosure frame with wiring in progress](../images/template_pics/48a.gif) -->

A Zero PCB was used to organize and simplify the wiring between the modules. It provided a convenient way to distribute GND and VCC connections and make the required signal connections between the different components, helping keep the wiring compact and organized inside the enclosure.

Figure 49: Enclosure with side panel open during wiring

It wasn't a perfectly linear process. There were several rounds of testing, adjustments, wiring changes, and mechanical fixes to make everything fit and work together properly. Getting the load cell and HX711 working reliably, positioning the ultrasonic sensor and camera correctly, and fitting all the modules inside the 3D-printed enclosure required a lot of patience and trial and error.

Figure 50: Enclosure side view with modules and wiring

These two days involved a lot of hands-on work and problem-solving. Each issue helped me better understand the practical challenges of combining electronics, sensors, wiring, and a custom 3D-printed enclosure into a single working system.

<!-- ![Figure 51: Internal wiring of the enclosure](images/template_pics/51.png) -->

Figure 52: Internal wiring – controller and modules

Figure 53: Fitting the wiring inside the enclosure

Each problem along the way helped me understand the system better, from electronics and soldering to mechanical design, sensor integration, and debugging. By the end, the enclosure had evolved from a CAD design into a working physical node with the components properly integrated and ready for the next stage of testing.

Figure 54: Internal wiring close-up

Figure 55: Front panel wiring from the inside

## Step 7: Final Assembly

Figure 56: Final assembled PRISM node – front view

After integrating all the sensors, modules, wiring, and supporting electronics, the complete system was assembled inside the custom 3D-printed enclosure. The final assembly provided a compact and organized integration of the sensing and control components, with all major connections securely routed and the individual modules positioned according to the enclosure design. The completed unit represents the final physical implementation of the node, ready for testing and deployment.

Figure 57: Final assembly – side view with USB connection

Figure 58: Final assembly – front view with storage bin

Figure 59: Final assembly – angled view

## Step 8: Hardware Testing and Troubleshooting

Figure 60: PRISM node connected to laptop for hardware testing

With the complete hardware assembly finished and only four days remaining before the final submission, the next priority was to verify that every sensor and module was functioning correctly. Since I had already prepared individual test setups for each sensor, the testing process was much easier and more systematic.

During the initial testing, I discovered that the display and RYG LED were not working at all. After checking the components, the issue was traced back to wiring problems rather than faulty hardware. I had to rewire both modules and test the connections again. This troubleshooting and rewiring process took nearly four hours, but eventually both the display and RYG LED were working perfectly.

Figure 61: Hardware testing with serial output on laptop

After resolving these issues, I went through each sensor and module individually once again to verify their operation. This final round of individual testing gave me confidence that the components were functioning correctly before moving forward with the complete integrated system.

## Step 9: Sensor Integration and Demo Implementation

After completing the individual testing of each sensor, the next major step was to combine the separate sensor programs into a single working demonstration. This was more involved than simply merging the code, because each sensor had its own initialization, reading method, timing requirements, and output logic. I had to make sure that adding one sensor did not interfere with the operation of the others.

Figure 62: OLED showing live LED count with green stock indicator

For the initial demonstration, I decided to use the RYG LEDs as the primary inventory item, since they were available in sufficient quantity for repeated testing. I then built the inventory monitoring logic around the actual measurements obtained from the hardware.

The first step was integrating and calibrating the load cell with the HX711. I measured the weight of an empty tray, which was approximately 55 g, and then measured an individual RYG LED, which was approximately 3.55 g. The tray weight therefore had to be separated from the actual inventory weight before calculating the quantity.

Figure 63: Code – HX711 load cell calibration and startup

The approximate number of LEDs can be calculated using:

Number of LEDs = (Measured Weight − Empty Tray Weight) / Weight of One LED

For example, if the measured weight of the tray and LEDs is 232.75 g:

Inventory weight = 232.75 − 55 = 177.75 g

Estimated LED count = 177.75 / 3.55 ≈ 50 LEDs

This provided a practical way to estimate the remaining inventory from the load-cell measurement rather than manually counting every LED.

Figure 64: Code – main loop with piece count calculation

I then introduced the inventory thresholds into the system. For the demonstration, the full inventory was considered to be 13 LEDs. When the estimated count falls below 50% of the initial inventory, the RYG indication is used to alert the worker that the stock level is decreasing. This makes the worker the first point of awareness, allowing the shortage to be identified and reported before the situation becomes critical.

Figure 65: Code – RYG LED update based on percentage remaining

When the estimated inventory falls below 20%, the system enters a more critical state. A red LED indication is activated along with a 10-second buzzer. The buzzer is specifically intended to make the severity of the situation more noticeable, so that the worker can immediately recognize that the remaining inventory requires urgent attention and notify the store manager.

Figure 66: Code – buzzer start, stop and update logic

**Challenges During Sensor Integration**

The integration itself required several iterations. The individual sensor programs worked correctly when tested separately, but combining them introduced new problems. I had to coordinate the sensor initialization, reading intervals, calculations, threshold checks, and output indications within the same program without blocking the operation of other sensors.

For example, the weight sensor cannot simply be treated as an instantaneous reading. Its values need to be read and processed carefully to avoid fluctuations being interpreted as actual inventory changes. Similarly, the IR sensor needed to be considered together with the weight measurement so that a detected object removal could be correlated with an actual decrease in inventory.

I therefore added the IR sensor as a second source of information. When a worker removes an LED or another component, the IR sensor can detect the removal while the load cell checks whether the overall weight has also decreased. Using these two observations together provides an additional verification mechanism instead of relying entirely on a single sensor.

Figure 67: Code – IR-based pick estimator

I also integrated the ultrasonic sensor to provide another measurement of the inventory level. The sensor measures the distance between itself and the objects inside the bin. When more objects are present, the surface of the inventory is closer to the sensor, resulting in a smaller measured distance. As the inventory decreases, the distance increases. This gives another physical measurement that can be compared with the weight-based estimation.

Figure 68: Code – ultrasonic distance measurement 

Bringing these sensors together required repeated testing because the readings do not behave identically. Weight measurements can fluctuate, IR detection represents an event, and ultrasonic sensing provides a distance value that changes continuously. The challenge was therefore not only to make each sensor work, but to make their outputs contribute meaningfully to the same inventory-monitoring logic.

These combined sensor tests formed the offline implementation and demonstration setup for the project. The objective at this stage was to validate the complete sensing concept using measurable inventory changes before moving toward the final integrated implementation.

Figure 69: Offline demo – green, yellow and red stock indications

## Step 10: IoT Integration and Firebase Data Flow

After completing the offline sensor integration and validating the inventory logic, the next step was to add the IoT layer. The objective was to take the data already being generated locally by the sensors and make it available remotely through Firebase.

The overall data flow was structured as:

**Sensors → Main Controller → Wi-Fi Module → Internet → Firebase → Dashboard / Prediction**

Figure 70: Code – reading sensor data from the load cell

The main controller first collects the readings from the different sensors. These include the estimated inventory count, load-cell weight, IR detection status, ultrasonic distance, and inventory-level indication. The controller processes these raw sensor readings locally and generates the values required by the inventory-monitoring logic.

Figure 71: Serial Monitor – calibration, load cell, distance and data sent

### Wi-Fi Integration

To transfer this information to the cloud, I integrated a Wi-Fi module with the controller. The first stage was establishing communication between the controller and the Wi-Fi module. The Wi-Fi module was configured with the required network credentials and used to establish an internet connection.

Figure 72: Serial Monitor – Wi-Fi gateway connected and sending data to Firebase (HTTP 200)

Once the connection was available, the controller could send the processed sensor values through the Wi-Fi interface. I had to ensure that the communication between the controller and Wi-Fi module was working correctly before attempting to send data to Firebase. This involved checking the transmitted values and making sure that the sensor readings being generated locally were reaching the communication layer correctly.

Figure 73: Serial Monitor – load cell and distance data being transmitted

After establishing the Wi-Fi connection, I configured the system to transmit the inventory-related data to Firebase. Instead of treating each sensor independently, the relevant readings were sent as part of the inventory data generated by the node.

Figure 74: Firebase Realtime Database – connection status and bins

### Firebase Data Flow

Figure 75: Firebase Realtime Database – BIN-RYG-08 data

The data flow begins when a sensor produces a physical measurement. For example, the load cell measures the weight of the contents, which is processed to estimate the number of LEDs remaining. Similarly, the IR sensor provides object-removal information, while the ultrasonic sensor provides the distance to the inventory.

The controller processes these readings and prepares the corresponding values for transmission. The Wi-Fi module then sends the data over the internet to Firebase, where the values can be stored and accessed remotely.

This creates a continuous path from the physical inventory to the cloud:

**Physical Inventory → Sensor Measurements → Local Processing → Wi-Fi Transmission → Firebase Storage**

Figure 76: Firebase data and Serial Monitor side by side

With the data now available in Firebase, the same dataset can be used for the next stages of the project. The immediate goal is to use it for remote inventory visualization, allowing the current inventory status and sensor readings to be displayed without directly accessing the hardware. The accumulated historical data can then provide the input required for inventory trend analysis and prediction.

This IoT integration therefore forms the bridge between the physical sensing system and the software side of the project, allowing the measurements collected by the node to become remotely accessible data rather than remaining only on the device.

Figure 77: Firebase – model prediction and history data

## Step 11: GUI and Inventory Management Dashboard

After completing the hardware and IoT integration, the next stage was to develop the GUI for inventory monitoring and management. Since the system is intended for factory production environments and store or stock managers, I chose a dashboard layout inspired by the type of Power BI-style interfaces commonly used for industrial and business data monitoring. The focus was to make the important inventory information visible without requiring the manager to go through individual sensor readings.

 Figure 78: Dashboard – Inventory Overview 

Figure 79: Dashboard – product search and bins

The main dashboard begins with an inventory overview, providing a quick summary of the current stock situation. Below this, individual components are displayed along with their estimated remaining inventory and the number of days before they are expected to go out of stock. Charts are also provided for individual components so that managers can understand inventory levels and changes more easily through visual trends rather than relying only on numerical values.

Figure 80: Dashboard – shipments & invoices, supplier & courier scorecard

The dashboard also includes category-based searching and filtering, allowing managers to select a particular product category and view the corresponding inventory information. The system can also display the contents of individual storage bins, including the estimated quantity of components currently present in each bin.

Figure 81: Dashboard – category-based product search

Another part of the interface focuses on inventory trends. Graphs are used to show how stock levels and consumption rates change over time, making it easier to identify increasing or decreasing inventory trends. Historical inventory information, including previous-year data, is also included to provide a basis for comparing current stock behaviour with past records.

Figure 82: Dashboard – stock forecast chart for RYG LED Sensor bin

Since the system may be used for extended periods, I also added a night mode to make the dashboard more comfortable to use in low-light environments.

Figure 83: Dashboard – night mode

At the current prototype stage, the RYG LED inventory is the primary real-time dataset connected to the dashboard. Its quantity and inventory status are updated using the data received from the physical sensing system. The other components and interface elements are being used to demonstrate how the system can be extended as more real-time inventory data becomes available.

Figure 84: Dashboard – live RYG LED bin card with forecast

Figure 85: Dashboard – priority watchlist showing RYG LED bin

Figure 86: Invoice PDF tracking – uploading an invoice PDF

### Invoice PDF Tracking

<!-- ![Figure 87: Invoice PDF tracking – confirming shipment details](images/template_pics/87.png) -->

Figure 88: Invoice PDF tracking – shipment added with tracking link

I also added a separate invoice PDF tracking feature to make inventory updates easier to manage from existing company records. The idea is to allow relevant invoice documents to be associated with inventory transactions rather than requiring the store manager to manually search through separate records.

Figure 89: Courier tracking details for the shipment

Figure 90: Email alert – low-stock prediction and reorder notification

By tracking invoice information alongside inventory data, the manager can refer back to the corresponding purchase or stock information when required. This provides an additional connection between the physical inventory, the digital inventory records, and the documentation associated with stock movement.

Figure 91: Terminal – local server and prediction model running

### Inventory Prediction and Alerts

For the initial prediction implementation, I used a Linear Regression model to analyse the available inventory data and estimate future stock behaviour. The model uses the collected inventory information to generate a prediction of the expected stock trend. The implementation details and model-related code are documented separately in the project's GitHub repository.

Github Documentations: [https://github.com/mydhily-mr/aiot-inventory-predictor/tree/main/docs](https://github.com/mydhily-mr/aiot-inventory-predictor/tree/main/docs)

The prediction system is also connected to an email alert mechanism. When the predicted or monitored inventory reaches a low-stock condition, the system can generate an email notification so that the responsible person can take action before the component is completely depleted.

Figure 92: Final PRISM prototype with laptop

At this stage, both the GUI and the AI prediction model are hosted locally, since the current implementation is a prototype. The local setup allows me to test the complete workflow, from sensor data collection and Firebase transmission to dashboard visualization, prediction, and alert generation, before moving toward a fully deployed production system.

Figure 92: Final PRISM prototype with laptop

## Step 12: Final Outputs and Demonstration Results

Figure 92: Final PRISM prototype with laptop

The final outcome of the project is a working AIoT-based inventory monitoring prototype that connects the physical inventory sensing system with cloud data storage, a management dashboard, and an inventory prediction module.

The completed hardware node integrates the load cell and HX711, IR sensor, ultrasonic sensor, RYG indicators, display, buzzer, Wi-Fi module, and supporting electronics within the custom 3D-printed enclosure. The individual sensors were tested separately before being integrated, and the final assembly was then tested as a complete system.

Figure 93: Final demonstration – PRISM node with RYG LEDs 

During the final demonstration, the RYG LEDs were used as the primary inventory item. The load cell was calibrated using an empty tray weight of approximately 55 g, while the measured weight of a single RYG LED was approximately 3.55 g. These measurements were used to estimate the number of LEDs remaining based on changes in the total measured weight.

| Light | Rule | Demo bin (capacity 12) |
|---|---|---|
| Green | above 50% | 7 to 13 pieces |
| Yellow | 21% to 50% | 3 to 6 pieces |
| Red | 20% or less | 0 to 2 pieces |

Figure 94: Final demonstration – dashboard, Firebase data and email alert

The inventory logic was demonstrated using two stock-level thresholds. When the estimated inventory falls below 50%, the system provides an RYG indication to notify the worker that the stock level is decreasing. When the inventory falls below 20%, the system activates the red indicator and a 10-second buzzer alert, representing a more critical shortage that requires the worker to notify the store manager.

Figure 95: Final demonstration – worker picking components from the bin

The IR sensor and ultrasonic sensor were also incorporated into the demonstration as additional inventory measurements. The IR sensor provides an indication when a component is removed, while the ultrasonic sensor measures the distance to the inventory inside the bin. These readings provide additional information that can be compared with the weight-based inventory calculation.

Figure 96: Final PRISM node – different views

### IoT and Dashboard Results

The sensor readings generated by the physical node were successfully passed through the Wi-Fi communication layer to Firebase. This established the complete data path from the physical inventory to the cloud database.

The dashboard then uses the available data to present the inventory information in a manager-oriented interface. The final GUI includes an inventory overview, component-level stock information, estimated days remaining, category-based filtering, individual bin information, inventory trend charts, and historical data. A night-mode interface was also implemented for easier extended use.

At the current prototype stage, the RYG LED inventory is the primary real-time dataset displayed in the dashboard. Changes made to the physical inventory are reflected in the corresponding inventory data, demonstrating the connection between the hardware sensing layer and the software interface.

Figure 97: Dashboard alongside the Firebase Realtime Database

### Prediction and Alert Results

The prediction module was implemented using Linear Regression to analyse the available inventory data and estimate future stock behaviour. The predicted inventory information is intended to help identify potential shortages before the stock reaches a critical level.

An email notification mechanism was also implemented as part of the prototype. When the inventory reaches the defined low-stock condition, the system can generate an alert for the responsible personnel. This extends the system beyond passive monitoring by providing a mechanism for notifying the user when attention is required.

Figure 98: Email alert received for low stock

### Overall Demonstration

The final prototype demonstrates the complete workflow:

**Inventory → Sensors → Controller → Wi-Fi → Firebase → Dashboard → Prediction → Email Alert**

Figure 99: Complete workflow – dashboard, Firebase, PRISM node and email alert

The final output is therefore not limited to a physical sensing node. It demonstrates an integrated workflow in which inventory changes are detected at the hardware level, processed locally, transmitted to the cloud, visualized through a management dashboard, analysed for future stock behaviour, and used to generate alerts.

The current implementation is intentionally maintained as a local prototype for demonstration and validation. It provides the complete functional foundation that can later be extended with additional inventory categories, larger datasets, improved prediction models, and production-level deployment.

---

## Schematics

Figure 100: PRISM complete circuit schematic

## Project Video:

**[https://youtu.be/odlPvgT5Zeg?si=Ek_2I9EwPxp-R_3K](https://youtu.be/odlPvgT5Zeg?si=Ek_2I9EwPxp-R_3K)**

## Code:

**(Any: Github link, Drive link, Dropbox supported shared with viewer rights)**

LInk:- **[https://github.com/mydhily-mr/aiot-inventory-predictor](https://github.com/mydhily-mr/aiot-inventory-predictor)**

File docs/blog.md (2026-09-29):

**Name:** Mydhily M R

## Members (maximum 8 members):

| S. No. | Name | Role / Contribution | Contact (Optional) |
|---|---|---|---|
| 1. | Mydhily M R | Team lead: hardware, MAX32630FTHR firmware, NodeMCU gateway, Firebase, dashboard, AI forecasting | +91 7034710672<br>[mydhily@cdac.in](mailto:mydhily@cdac.in)<br>[mydhily37@gmail.com](mailto:mydhily37@gmail.com) |

## Project Checklist

**Phase 1**

| Item | Status |
|---|---|
| Project Title | **Done** |
| Cover Image | **Done** |
| List of Components | **Done** |
| Detailed Project Description | **Done** |
| Schematics | **Done** |
| Code | **Done** |
| CAD/ PCB Design If any *Optional | **Done** |
| Photo of project | **Done** |
| Video displaying working of Project | **Done** |
| BONUS/OPTIONAL: Video explaining working of the project | **Done** |

# Title: PRISM — Predictive Replenishment & Inventory Stock Monitoring

**Tag line:** **PRISM predicts what you're about to run out of, before you run out.**

## Cover Image:

Figure 1: Cover image – three PRISM units showing green, yellow and red stock levels

## Video:

**[https://youtu.be/odlPvgT5Zeg?si=Ek_2I9EwPxp-R_3K](https://youtu.be/odlPvgT5Zeg?si=Ek_2I9EwPxp-R_3K)**

## Component List:

DigiKey MyList (BOM): **[MyList link Click here](https://www.digikey.in/en/mylists/list/48SZ6VB09U)**

| Sl No | Name | Qty | Datasheet | Link |
|---|---|---|---|---|
| 1 | MAX32630 FTHR | 1 | [Datasheet Link](https://www.analog.com/media/en/technical-documentation/data-sheets/max32630fthr.pdf) | [Link to Buy](https://www.digikey.in/en/products/detail/analog-devices-inc-maxim-integrated/MAX32630FTHR/6575544) |
| 2 | Load Cell 5 Kg | 1 | [Datasheet Link](https://cdn.sparkfun.com/assets/e/5/f/5/6/TAL220B.pdf) | [Link to Buy](https://www.digikey.in/en/products/detail/sparkfun-electronics/14729/9555603) |
| 3 | HX711 BOARD | 1 | [Datasheet Link](https://mm.digikey.com/Volume0/opasdata/d220001/medias/docus/5858/333005%20Load%20cell%20amplifier%20HX711%20board%20datasheet.pdf) | [Link to Buy](https://www.digikey.in/en/products/detail/soldered-electronics/333005/21720457) |
| 4 | SSD1306 OLED Display 0.96" | 1 | Datasheet Link | Link to Buy |
| 5 | Ultrasonic Sensor | 1 | [Datasheet Link](https://www.digikey.in/en/products/detail/adafruit-industries-llc/3942/9658069) | [Link to Buy](https://mm.digikey.com/Volume0/opasdata/d220001/medias/docus/692/3942_Web.pdf) |
| 6 | Piezo Buzzer | 1 | Datasheet Link | Link to Buy |
| 7 | PIR Sensor | 1 | [Datasheet Link](https://mm.digikey.com/Volume0/opasdata/d220001/medias/docus/8924/ST0012%20%20%20HC-SR501%20Human%20Body%20Pyroelectricity%20Infrared%20Sensor%20Module.pdf) | [Link to Buy](https://www.digikey.in/en/products/detail/sunfounder/ST0012/22116811) |
| 8 | IR Sensor | 1 | Datasheet Link | Link to Buy |
| 9 | Dotted PCB | 1 | Datasheet Link | Link to Buy |
| 10 | Bread Board | 1 | [Datasheet Link](https://mm.digikey.com/Volume0/opasdata/d220001/medias/docus/2329/239_Web.pdf) | [Link to Buy](https://www.digikey.in/en/products/detail/adafruit-industries-llc/239/7244929) |
| 11 | Jumper Wires | | [Datasheet Link](https://mm.digikey.com/Volume0/opasdata/d220001/medias/docus/8913/100862.pdf) | [Link to Buy](https://www.digikey.in/en/products/detail/soldered-electronics/555033/29271434) |
| 12 | Glue Gun | 1 | Datasheet Link | Link to Buy |
| 13 | Soldering ion | 1 | Datasheet Link | Link to Buy |
| 14 | RYG LED | 14 | | |

Figure 2: DigiKey MyList (BOM) – list of project components (https://www.digikey.in/en/mylists/list/48SZ6VB09U)

**Click on Any Product** To Open List

---

## Project Explanation Step By Step :

### Introduction

In a busy electronics lab or production floor, a small component bin can look fine until someone reaches for it and finds it empty. By then, the shortage has already become a problem.

**PRISM** turns an ordinary component bin into a smart inventory system that keeps track of what is actually inside it.The idea is simple: instead of waiting for a bin to become empty, PRISM tries to tell you that it is going to happen before it does.

PRISM is the result of that idea — **not just knowing how much stock is left, but knowing when we need to start worrying about what comes next.**

Figure 3: PRISM dashboard – product search and bin-wise stock view

### Inspiration - What leads to PRISM?

Figure 4: Inventory problems in manufacturing and production environments

I have faced this problem myself several times — needing a component for a project or a task, only to find out that the bin was empty or the required quantity wasn't available.

But when I started talking to colleagues working in different manufacturing and production environments, I realized this problem was much bigger than I had experienced.

I heard stories of production lines being stopped for an entire day because just **one small component was out of stock**. People would come to work, sit idle, and wait because the missing part hadn't been identified or replenished in time.

What surprised me was that this wasn't limited to electronics. Similar frustrations were being experienced by colleagues working in **mechanical, automotive, electronics, and other manufacturing industries**.

The problem wasn't always a lack of inventory management. The real problem was knowing **what is physically available right now — and when it is going to run out**.

That made me think:

**Why wait until a component is unavailable before we know there is a shortage?**

I wanted to build something that could continuously watch the physical stock, detect when components were being consumed, and warn us before a small shortage turns into a production stoppage.

That idea became **PRISM.**

Figure 5: PRISM enclosure – exploded CAD view of all parts

### The Problem Statement

- **Counts are stale:** Stock is counted by hand or updated in a spreadsheet at the end of a shift, so the record never matches the shelf.
- **Systems track issues**, not what is left. Barcode and ERP entries record what was booked out, not what is physically in the bin.
- **Stock-outs are found too late**. A bin is discovered empty at the shelf, after the time to reorder has already passed.
- **Reorder points ignore real usage**. Fixed minimum levels do not follow the actual consumption rate or the supplier's real lead time.
- **Workers get no signal**. Nothing at the shelf tells the person picking parts that the bin is nearly empty.

### Existing Systems

Figure 6: Existing systems – production lines, conveyors and manufacturing processes

**FIFO**

The components received first are used first. This helps prevent old or perishable components from remaining in inventory for too long.

**Kanban System**

Uses visual signals, such as cards or digital alerts, to indicate when components need to be replenished. It helps maintain the required stock level and avoid shortages.

**Lean Manufacturing**

Focuses on reducing waste, excess inventory, and unnecessary processes. The goal is to keep only the inventory needed for production.

**Six sigma**

Uses data and statistical methods to reduce errors and variations in processes. In inventory management, it can help improve demand forecasting and reduce inventory-related mistakes.

**Bulk Manufacturing**

Produces large quantities of products or components at once. This can reduce production costs but may lead to excess inventory if demand is not accurately predicted.

## The PRISM-Overview

### What Makes PRISM Different?

Instead of relying on manual stock checks or simply recording what components were issued, PRISM monitors the physical stock inside the bin itself. A load cell continuously measures the weight of the contents and estimates the number of components remaining, while an IR sensor helps identify when parts are picked. Local LEDs, an OLED display, and a buzzer provide immediate feedback to the person working at the shelf.

But PRISM doesn't stop at knowing what is available right now.

The bin sends its readings through a Wi-Fi gateway to Firebase, where the inventory can be monitored through a web dashboard. The system tracks the consumption trend and uses it to estimate how many days are left before the stock runs out.

Figure 7: Firebase Realtime Database – model prediction data for the RYG LED bin

This means the system can move from simply saying "this bin is low" to giving the team an early warning that "this bin is going to run out soon."

The goal is simple: instead of discovering a shortage when someone needs the last component, PRISM gives workers, stock managers, and purchasing teams time to react before that shortage becomes a production problem.

Figure 8: Inventory Overview dashboard alongside the PRISM node

### What PRISM does

PRISM serves three people from one bin:

| **Who** | **What they get** | **Built with** |
|---|---|---|
| Worker at the shelf | Live piece count with a + / − change marker, a green / yellow / red stock light, and a 10-second buzzer when stock falls to 20% | MAX32630FTHR, load cell, OLED, RYG LED, buzzer |
| Stock manager | A live dashboard: stock KPIs, bins ranked by which runs out first, forecast chart per bin, reorder timing against supplier lead time, shipments and FIFO checks | Firebase + web dashboard |
| Purchasing | Days-to-empty learned from each bin's consumption trend, plus an email / WhatsApp alert when a bin drops inside its lead time | Python regression model |

Figure 9: PRISM concept – manager input & control panel, smart tray on production line, and strategic manager dashboard

### What makes it different

**Counts by weight.** No scan per pick: the bin knows its own count at all times.

**Sensor fusion for picks**. The IR sensor sees a hand enter; the weight drop after the hand leaves says how many pieces were taken.

**Forecasts learned from data.** Reorder timing comes from the measured depletion trend, not a fixed minimum level.

**Alerts work offline**. The LED, OLED and buzzer run on the MAX32630FTHR itself, so the shelf still warns the worker if Wi-Fi drops.

**One protocol for any bin.** Each bin's identity lives on the device; the gateway is a generic relay, so a new bin needs only a new `binId` .

Figure 10: Dashboard, Firebase data and email alert – complete PRISM output view

### How PRISM Works: Complete Flow

A load cell under the bin counts components in real time on an Analog Devices MAX32630FTHR, an IR sensor and the weight drop together estimate each pick, and a red/yellow/green LED, OLED and buzzer tell the worker the stock level right at the shelf. Readings flow through a NodeMCU Wi-Fi gateway into Firebase, where a web dashboard gives the stock manager a live view and a machine-learning model forecasts days-to-empty for every bin.

Figure 11: PRISM node with the inventory dashboard running on a laptop

### Why did I build this?

This project started with a simple question: **why do we only realize that a component bin is empty when we actually need something from it?**

In an electronics lab, storeroom, or production floor, hundreds of small components can sit quietly in storage bins. The problem is that the stock inside those bins keeps changing, while the inventory record often doesn't. Someone takes a few components, another person takes a few more, and eventually the bin is empty — usually when someone needs that exact part.

I wanted to build something that could actually keep an eye on the bin.

PRISM turns an ordinary component storage bin into a smart inventory node. It uses weight sensing to estimate how many components are left, detects when parts are picked, and gives an immediate indication of the stock level using an RGB LED, OLED display and buzzer. The data is also sent to the cloud so the inventory can be monitored remotely.

But I didn't want PRISM to simply tell me "the bin is almost empty." I wanted it to answer a more useful question:

**"When is this bin going to become empty?"**

That's where the prediction part comes in. PRISM analyses the consumption trend and **estimates the number of days remaining before the stock runs out,** giving enough time to plan a reorder instead of discovering the shortage at the last moment.

This project has been a journey of sensors, wiring, calibration, firmware, debugging, failed experiments, and plenty of moments where something worked perfectly one minute and completely refused to work the next.

It is not a polished commercial product. It is a real working prototype that I built to explore how embedded systems, IoT, cloud monitoring and machine learning can come together to solve a very ordinary but very real problem.

So, this is the story of PRISM — a bin that doesn't just store components, but keeps track of them and tries to warn you before they run out.

Let's dive into how PRISM was built.

Figure 12: Worker picking RYG LEDs from the PRISM bin

### Components Required

DigiKey MyList (BOM): **[MyList link Click here](https://www.digikey.in/en/mylists/list/48SZ6VB09U)**

| Sl No | Name | Qty | Datasheet | Link |
|---|---|---|---|---|
| 1 | MAX32630 FTHR | 1 | [Datasheet Link](https://www.analog.com/media/en/technical-documentation/data-sheets/max32630fthr.pdf) | [Link to Buy](https://www.digikey.in/en/products/detail/analog-devices-inc-maxim-integrated/MAX32630FTHR/6575544) |
| 2 | Load Cell 5 Kg | 1 | [Datasheet Link](https://cdn.sparkfun.com/assets/e/5/f/5/6/TAL220B.pdf) | [Link to Buy](https://www.digikey.in/en/products/detail/sparkfun-electronics/14729/9555603) |
| 3 | HX711 BOARD | 1 | [Datasheet Link](https://mm.digikey.com/Volume0/opasdata/d220001/medias/docus/5858/333005%20Load%20cell%20amplifier%20HX711%20board%20datasheet.pdf) | [Link to Buy](https://www.digikey.in/en/products/detail/soldered-electronics/333005/21720457) |
| 4 | SSD1306 OLED Display 0.96" | 1 | Datasheet Link | Link to Buy |
| 5 | Ultrasonic Sensor | | [Datasheet Link](https://www.digikey.in/en/products/detail/adafruit-industries-llc/3942/9658069) | [Link to Buy](https://mm.digikey.com/Volume0/opasdata/d220001/medias/docus/692/3942_Web.pdf) |
| 6 | Piezo Buzzer | | Datasheet Link | Link to Buy |
| 7 | PIR Sensor | | [Datasheet Link](https://mm.digikey.com/Volume0/opasdata/d220001/medias/docus/8924/ST0012%20%20%20HC-SR501%20Human%20Body%20Pyroelectricity%20Infrared%20Sensor%20Module.pdf) | [Link to Buy](https://www.digikey.in/en/products/detail/sunfounder/ST0012/22116811) |
| 8 | IR Sensor | | Datasheet Link | Link to Buy |
| 9 | Dotted PCB | | Datasheet Link | Link to Buy |
| 10 | Bread Board | | [Datasheet Link](https://mm.digikey.com/Volume0/opasdata/d220001/medias/docus/2329/239_Web.pdf) | [Link to Buy](https://www.digikey.in/en/products/detail/adafruit-industries-llc/239/7244929) |
| 11 | Jumper Wires | | [Datasheet Link](https://mm.digikey.com/Volume0/opasdata/d220001/medias/docus/8913/100862.pdf) | [Link to Buy](https://www.digikey.in/en/products/detail/soldered-electronics/555033/29271434) |
| 12 | Glue Gun | | Datasheet Link | Link to Buy |
| 13 | Soldering ion | | Datasheet Link | Link to Buy |

Figure 13: All components used in PRISM laid out
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

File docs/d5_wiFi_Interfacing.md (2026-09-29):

# Individual Sensor Testing

# WiFi Module Interfacing — MAX32630FTHR + NodeMCU (ESP8266)

### Goal

The MAX32630FTHR (this project's main board, per the competition abstract) has no
built-in WiFi. This session covers getting sensor data off the MAX32630FTHR and
into Firebase Realtime Database over WiFi, using a NodeMCU (ESP8266) as a
dedicated WiFi bridge.

### Issues faced and how each was solved

1. **`dtostrf()` not declared.** Used to format the sensor float as a string;
   this AVR-only convenience function isn't implemented on this core. Fixed by
   using standard `sprintf(buf, "%.2f", value)` instead — confirmed safe on
   this core by checking its link flags (`--specs=nosys.specs`, full newlib,
   not the stripped `newlib-nano` that famously breaks floating-point
   `sprintf` on some ARM cores).
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

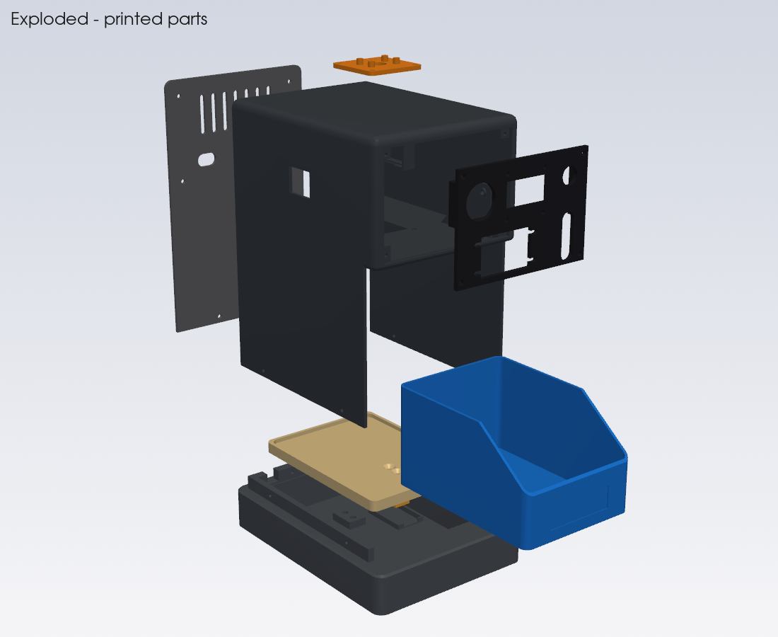
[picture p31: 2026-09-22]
case_design_files/AIoT_case_v5/AIoT_case_v5/renders/6_exploded.png

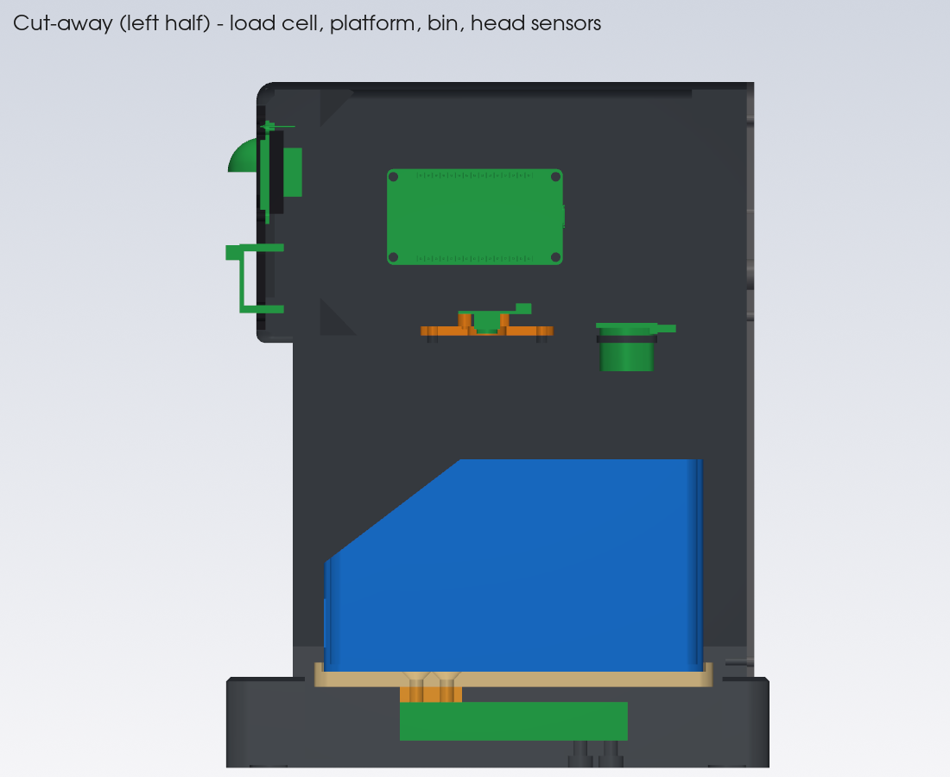
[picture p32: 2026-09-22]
case_design_files/AIoT_case_v5/AIoT_case_v5/renders/3_section_side.png

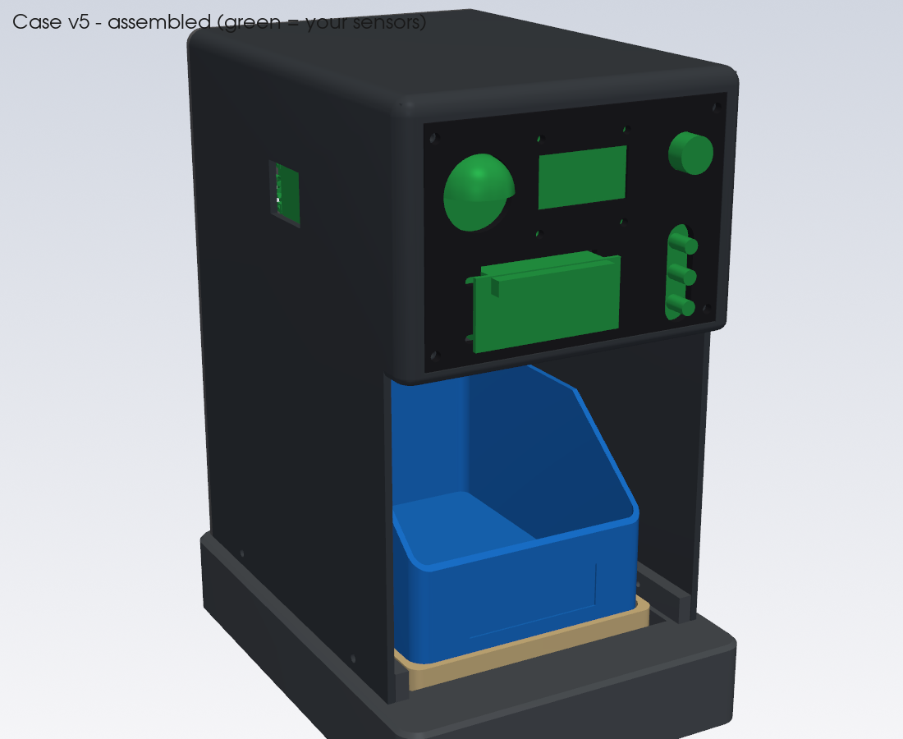
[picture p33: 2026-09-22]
case_design_files/AIoT_case_v5/AIoT_case_v5/renders/1_hero_front.png

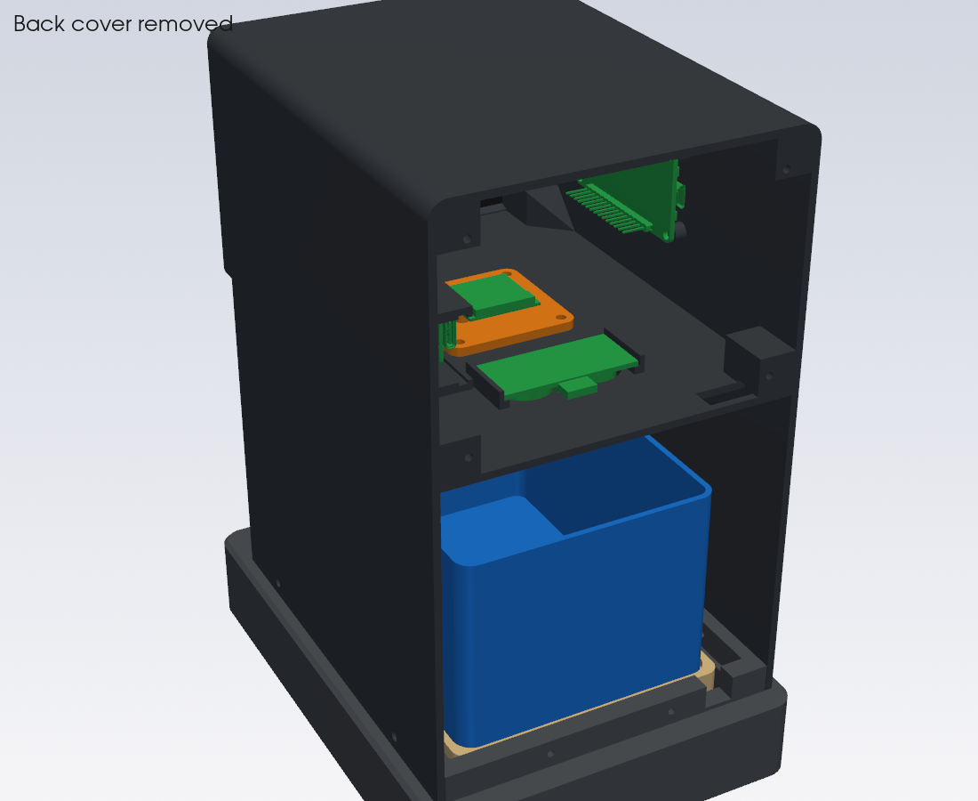
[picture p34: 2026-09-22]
case_design_files/AIoT_case_v5/AIoT_case_v5/renders/4_back_open.png

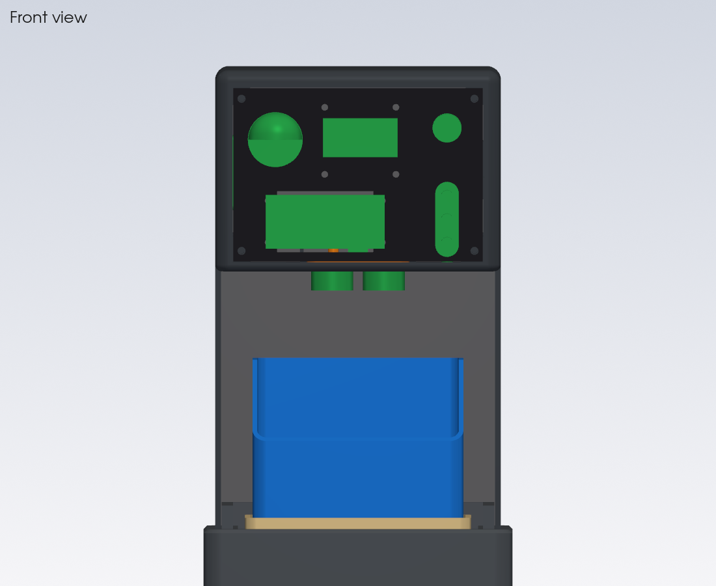
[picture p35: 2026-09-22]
case_design_files/AIoT_case_v5/AIoT_case_v5/renders/2_front.png

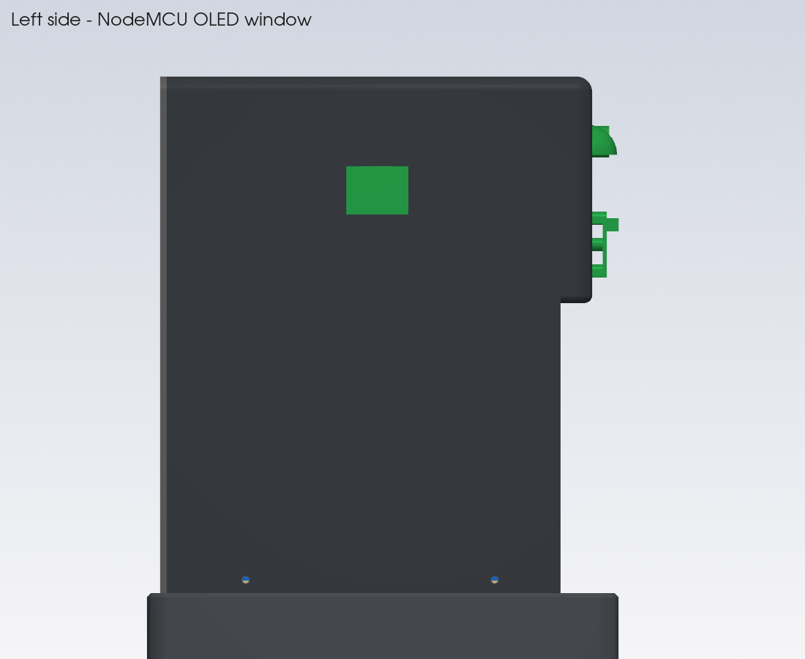
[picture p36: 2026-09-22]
case_design_files/AIoT_case_v5/AIoT_case_v5/renders/5_left_side.png

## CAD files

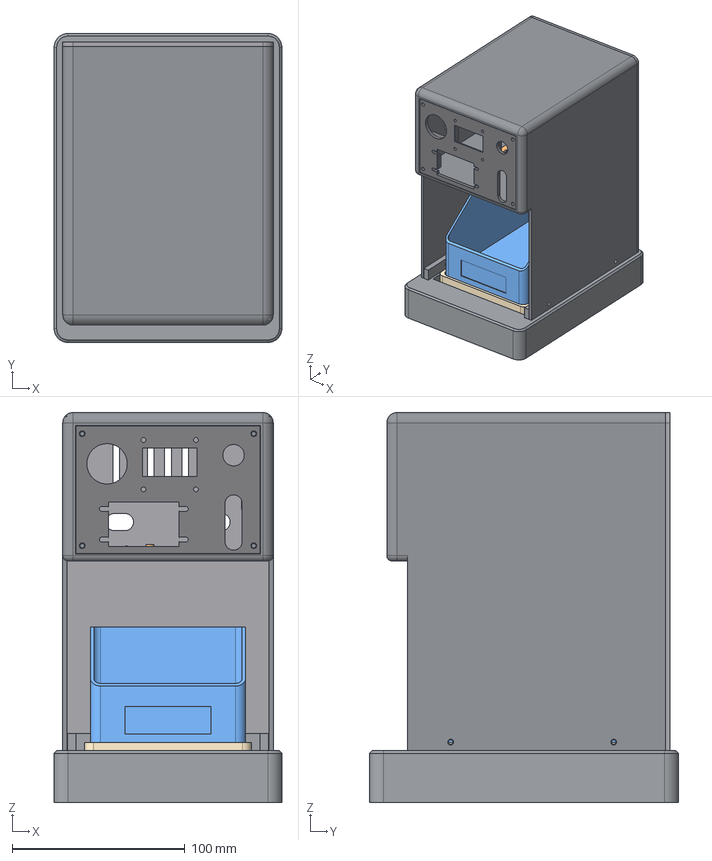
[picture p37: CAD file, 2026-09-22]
case_design_files/AIoT_case_v5/AIoT_case_v5/STEP_for_Fusion360/00_CASE_ASSEMBLY_printed_parts_only.step
132.0 x 179.0 x 226.0 mm
01_tower_body
02_base
03_faceplate_oled1.3in
04_back_cover
05_weigh_platform
06_loadcell_spacer
07_camera_plate_std_OV5647
08_storage_bin

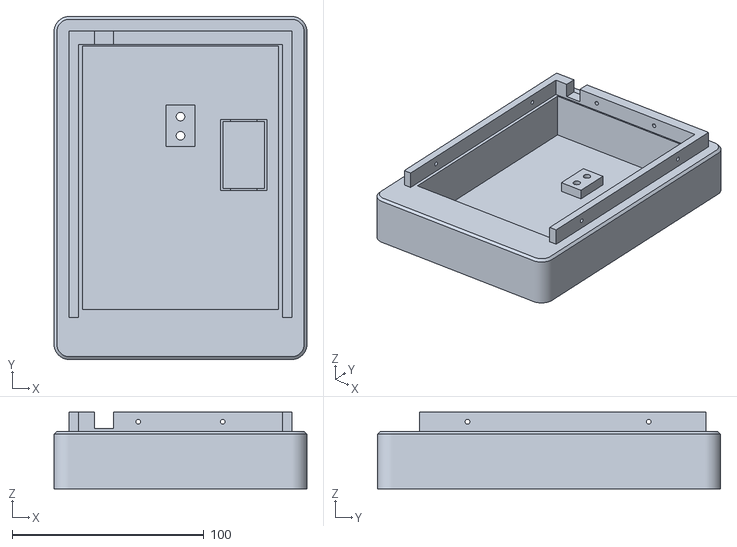
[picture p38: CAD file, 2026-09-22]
case_design_files/AIoT_case_v5/AIoT_case_v5/print_ready_STL/02_base.stl
132.0 x 179.0 x 40.0

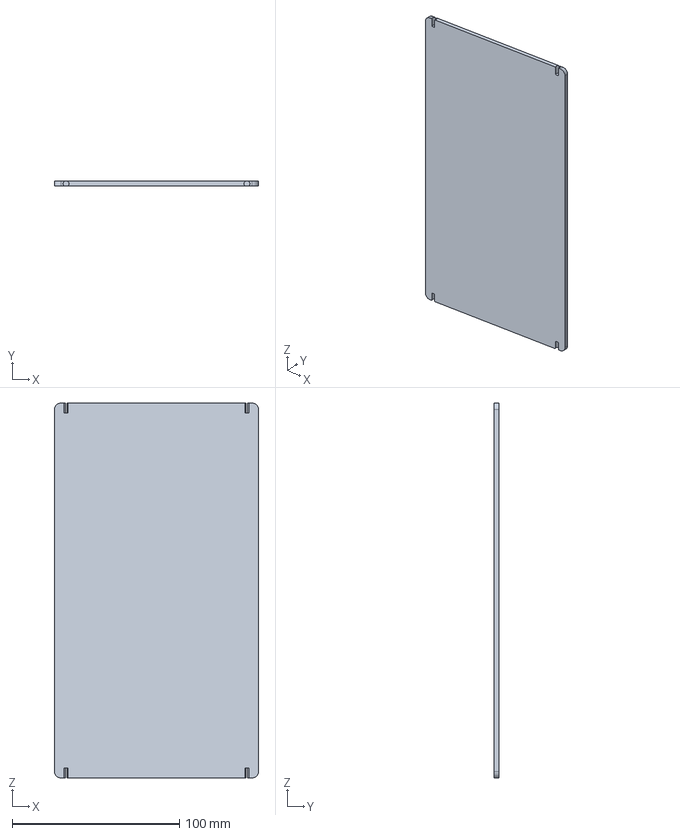
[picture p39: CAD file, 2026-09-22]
case_design_files/aiot_case_v6_fusion360/back_cover_v6.step
122.0 x 3.00 x 224.0 mm

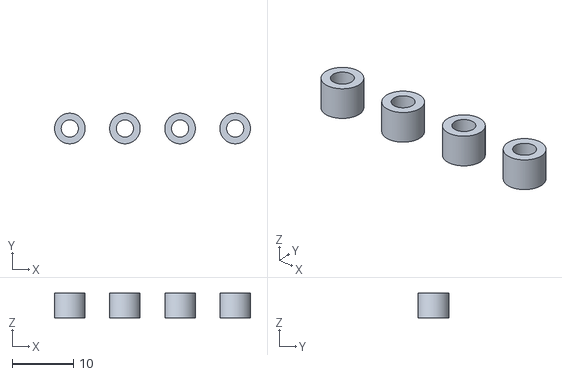
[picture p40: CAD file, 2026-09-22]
case_design_files/AIoT_case_v5/AIoT_case_v5/print_ready_STL/09_MAX32630_standoffs_x4.stl
32.0 x 5.00 x 4.00

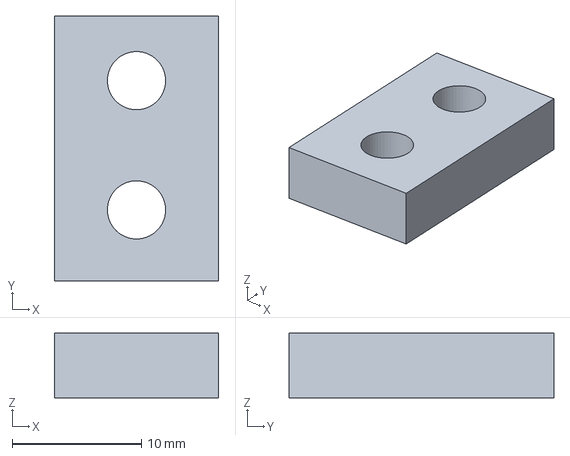
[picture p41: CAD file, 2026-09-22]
case_design_files/AIoT_case_v5/AIoT_case_v5/STEP_for_Fusion360/06_loadcell_spacer.step
12.7 x 20.5 x 5.00 mm

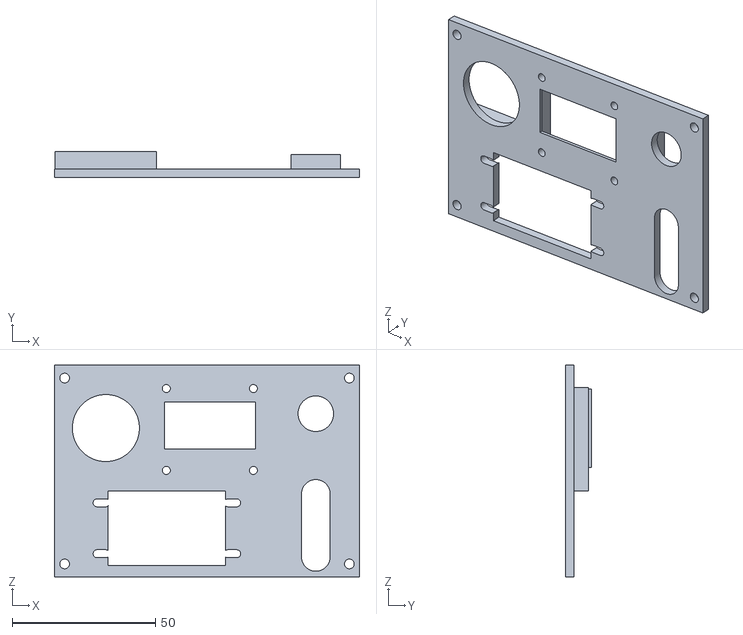
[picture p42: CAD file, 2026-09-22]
case_design_files/AIoT_case_v5/AIoT_case_v5/STL_assembled_position/03_faceplate_oled1.3in.stl
106.5 x 9.00 x 74.0

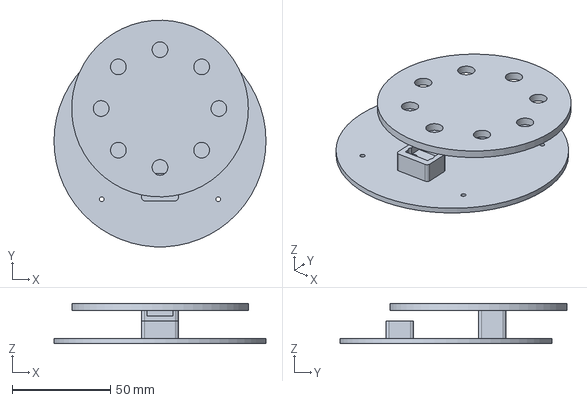
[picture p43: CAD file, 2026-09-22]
case_design_files/aiot_case_v6_fusion360/loadcell_platform.step
108.0 x 115.4 x 20.5 mm

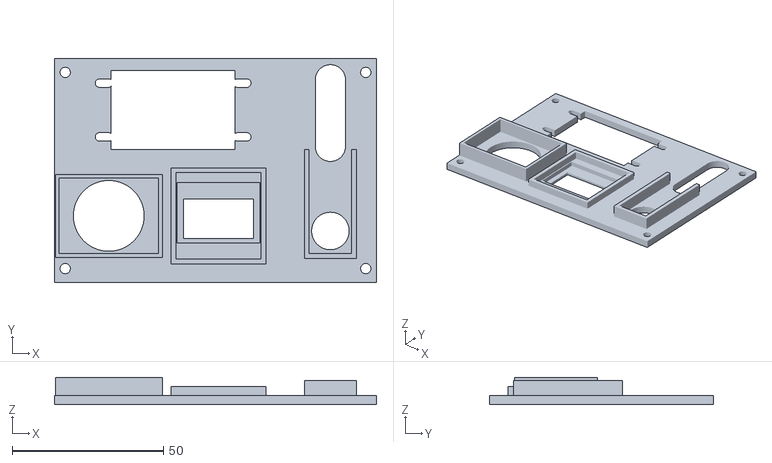
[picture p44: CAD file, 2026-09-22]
case_design_files/AIoT_case_v5/AIoT_case_v5/print_ready_STL/03b_faceplate_oled0.96in_ALT.stl
106.5 x 74.0 x 9.00

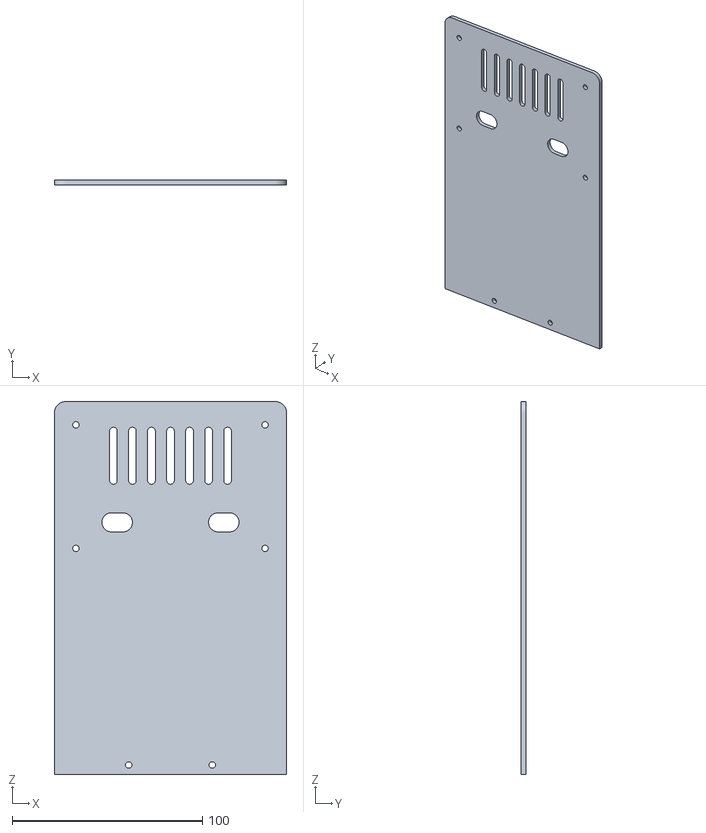
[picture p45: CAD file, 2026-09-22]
case_design_files/AIoT_case_v5/AIoT_case_v5/STL_assembled_position/04_back_cover.stl
122.0 x 2.50 x 196.0

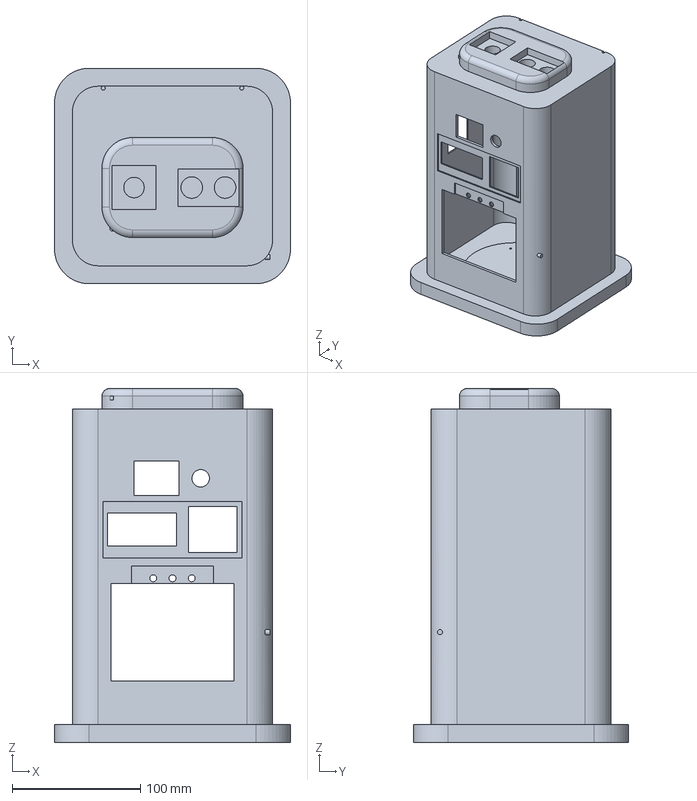
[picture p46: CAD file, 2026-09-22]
case_design_files/aiot_case_v6_fusion360/case_body_v6.step
184.0 x 168.0 x 276.0 mm

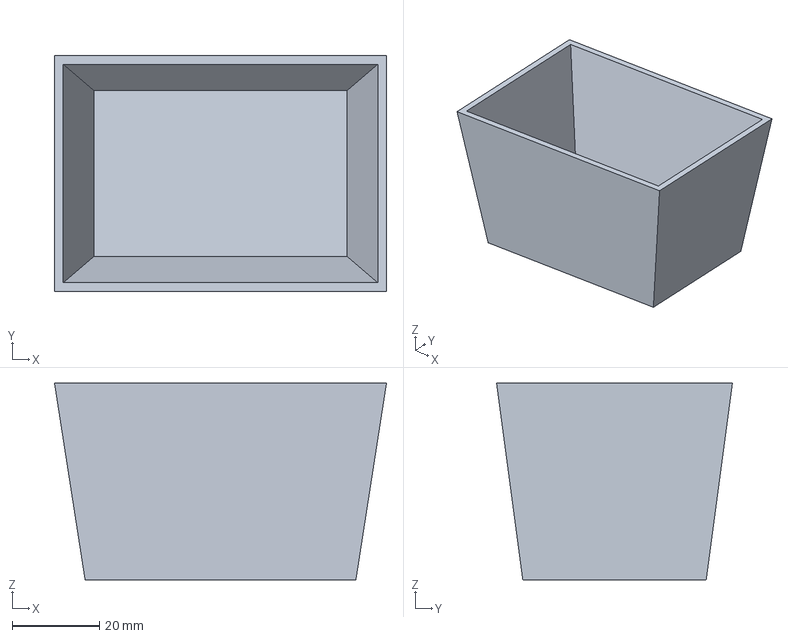
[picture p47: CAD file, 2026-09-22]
case_design_files/aiot_case_v6_fusion360/storage_bin_optional.step
76.0 x 54.0 x 45.0 mm

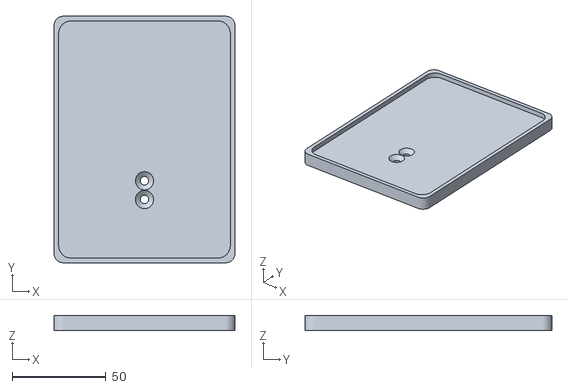
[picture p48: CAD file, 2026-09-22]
case_design_files/AIoT_case_v5/AIoT_case_v5/print_ready_STL/05_weigh_platform.stl
96.5 x 131.5 x 8.00

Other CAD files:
case_design_files/AIoT_case_v5/AIoT_case_v5/STEP_for_Fusion360/02_base.step
case_design_files/AIoT_case_v5/AIoT_case_v5/STL_assembled_position/02_base.stl
case_design_files/AIoT_case_v5/AIoT_case_v5/STEP_for_Fusion360/03b_faceplate_oled0.96in_ALT.step
case_design_files/AIoT_case_v5/AIoT_case_v5/print_ready_STL/04_back_cover.stl
case_design_files/AIoT_case_v5/AIoT_case_v5/STEP_for_Fusion360/04_back_cover.step
case_design_files/AIoT_case_v5/AIoT_case_v5/STL_assembled_position/09_MAX32630_standoffs_x4.stl
case_design_files/AIoT_case_v5/AIoT_case_v5/STEP_for_Fusion360/01_tower_body.step
case_design_files/AIoT_case_v5/AIoT_case_v5/STEP_for_Fusion360/03_faceplate_oled1.3in.step
case_design_files/AIoT_case_v5/AIoT_case_v5/STEP_for_Fusion360/05_weigh_platform.step
case_design_files/AIoT_case_v5/AIoT_case_v5/STEP_for_Fusion360/07_camera_plate_std_OV5647.step
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

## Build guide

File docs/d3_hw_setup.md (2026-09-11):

[← Back to README](../README.md)

## Day 2 - First Hello World on MAX32630FTHR board
<!-- **01/09/2026** -->

## MAX32630 board Pin Diagram
  MAX32630 board Pin Diagram— MAX32630 board Pin Diagram.

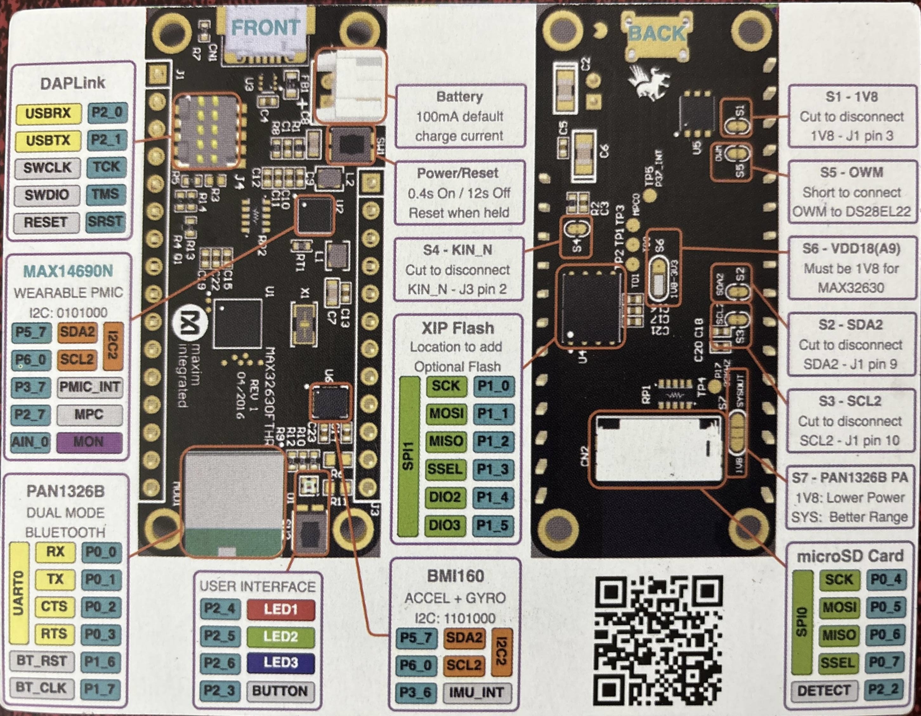
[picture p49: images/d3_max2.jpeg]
  — MAX32630 board Pin Diagram.

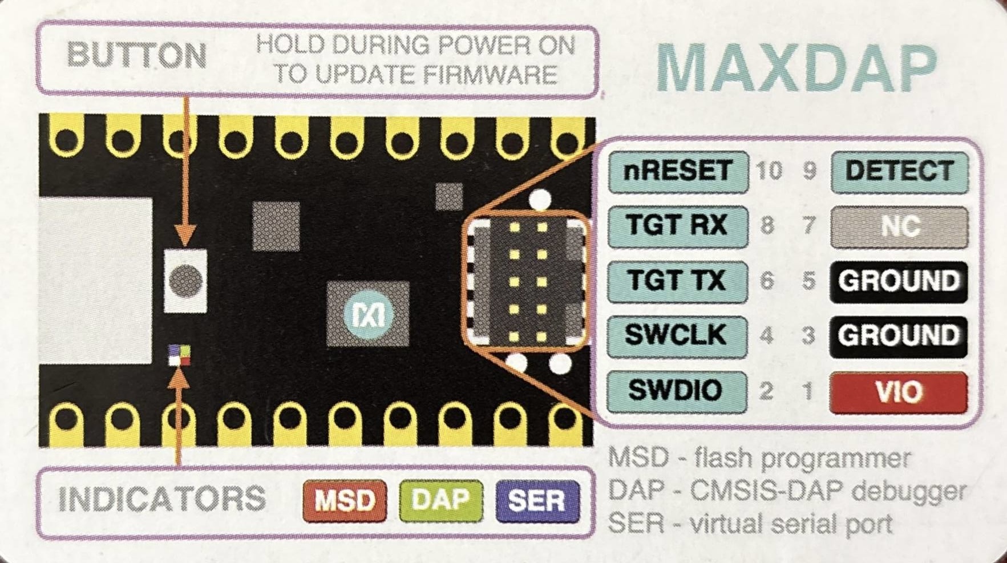
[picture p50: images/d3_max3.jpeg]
  — MAXDAP board Pin Diagram.

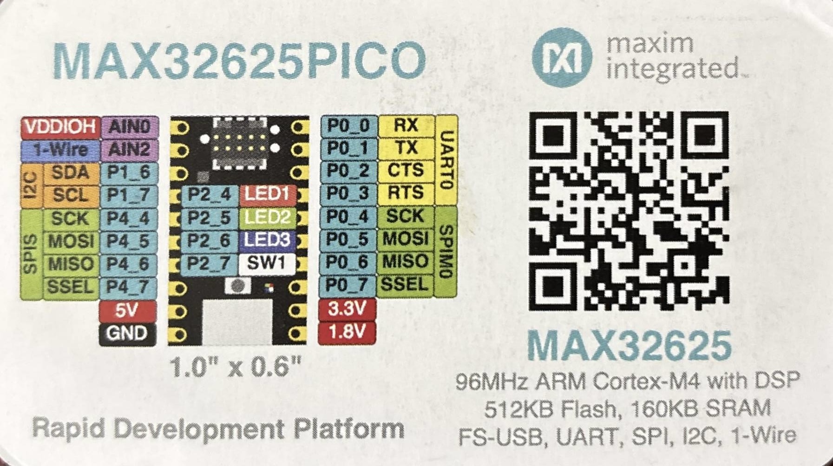
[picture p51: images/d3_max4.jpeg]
  — MAX32625PICO board Pin Diagram.

## Prerequisties
- Arduino IDE 1.18.9
- Ubuntu 20.04 LTS

### 1. Install MAX32630FTHR board on Ubuntu

- To install the MAX32630 (such as the MAX32630FTHR) board in the Arduino IDE, add Maxim's JSON package URL to your preferences and install the board via the Boards Manager.

- Add Maxim's JSON URL:
  ```bash
  https://raw.githubusercontent.com/analogdevicesinc/arduino-max326xx/master/package_maxim_index.json
  ```
  board Install— Add Maxim's JSON URL in File --> Preferences and click OK.

- Then, open the Boards Manager via Tools > Board, search for maxim, and install Maxim's 32-bit Microcontroller

  Arduino Board Manager— Click on Install and wait for the installation to be completed.

- After installation, select MAX32630FTHR under Tools > Board, choose your connected board's serial port in Tools > Port, and set the programmer to DAPLink under Tools > Programmer.

- Now connect the PICO and Board both to your PC.

  Connecting Board— Connect both MAX32625PICO and MAX32630FTHR board using USB cables provided.

- Now try the first program to test the board is OK or not, a simple hello world as shown in the example will be fine.

  Connecting Board— Click on Install and wait for the installation to be completed.
  
- Select Board as ```MAX32630FTHR ```, Port ``` /dev/ttyACM0 ```, Programmer ``` DAPLINK ``` , then open Serial Monitor, Select baud rate as ``` 115200 ```.

- Click on ``` Upload ``` to upload the program and observe the output in serial monitor.

  Output— If everything is fine you will see the success message after uploading and the output in serial monitor as in the given image.

  - If steps till above works, Congarts!!!! 
  Now you can start using MAX32630 board with other examples or sensors you are going to use.

  - Here i have provided test odes for each individual sensors i am using as a seperate chapter. Refer the same for details. 

---
[← Back: Software Architecture & Code](software-architecture.md) · [← Back to README](../README.md)

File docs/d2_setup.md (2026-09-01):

[← Back to README](../README.md)

## Day 2 - Installations and GUI
<!-- **15/08/2026** -->

Started a GitHub repo. GUI front end: HTML-based website.

## Required Softwares
- Python
- scikit-learn

### 1. Open Command Prompt and check Python

- Press the **Windows key**, type `cmd`, press **Enter** — a black window opens; this is where you'll type every command below.
- Type:
  ```bash
  python --version
  ```
  If you see something like `Python 3.12.x`, you're set — skip to the next step.
- If you see an error, go to [python.org](https://www.python.org), download Python, and during install tick **"Add python.exe to PATH"** before clicking **Install** — this is the single most common thing beginners miss.

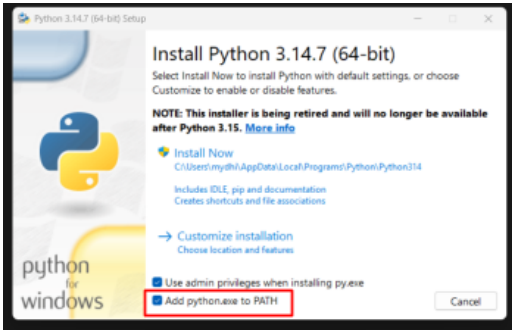
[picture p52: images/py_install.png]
Python Install
 — Python installer screenshot with "Add python.exe to PATH" checkbox highlighted.

> <!-- 📷 **`image9`** — Terminal showing `python --version` → `Python 3.14.7`. -->

### 2. Install the required packages

- Still in Command Prompt (close and reopen it first if you just installed Python).
- Type:
  ```bash
  pip install requests pandas scikit-learn
  ```
- It'll download and install for a minute or two — wait until the prompt returns with no red error text.

> <!-- 📷 **`image10`** — Terminal output of `pip install requests pandas scikit-learn` completing successfully. -->

### 3. Create a project folder and save your files there

- Make a folder to keep everything together, e.g. right-click on your `C:` drive in File Explorer → **New Folder** → name it `store_board`.
- Add `simulate_gateway.py` and `train_forecast.py` into that folder.

### 4. Set up Firebase and get your database URL

- Skip this if you already did it earlier.
- Go to [console.firebase.google.com](https://console.firebase.google.com) → **create a project** → **Build** → **Realtime Database** → **Create Database** (test mode).
- Copy the `databaseURL` shown — it looks like:
  ```
  https://your-project-default-rtdb.firebaseio.com
  ```
- Example URL used in this project:
  ```
  https://aiot-inventory-predictor-default-rtdb.asia-southeast1.firebasedatabase.app/
  ```

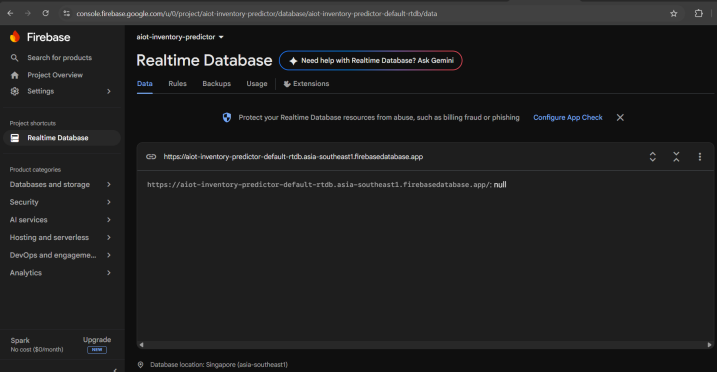
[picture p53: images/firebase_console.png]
Firebase Console
   — Firebase console "Project Overview" welcome screen after project creation.

><!--- > 📷 **`image12`** — Firebase "Set up database" dialog, choosing the Realtime Database location (e.g. Singapore asia-southeast1). -->

><!--- 📷 **`image13`** — Firebase security rules step — choosing **Start in Test mode**. -->

><!--- 📷 **`image14`** — Firebase Realtime Database "Data" tab showing the empty database with its URL. -->

### 5. Paste your Firebase URL into both scripts

- Right-click `simulate_gateway.py` → **Open with** → **Notepad**.
- Find the line starting `FIREBASE_DB_URL` near the top, replace the placeholder text with your real URL (keep the quote marks), save (**Ctrl+S**), close.
- Do the exact same thing in `train_forecast.py`.

- Example URL: 
  ```c
  FIREBASE_DB_URL = "https://aiot-inventory-predictor-default-rtdb.asia-southeast1.firebasedatabase.app/"

  ```

> <!---📷 **`image15`** — Firebase console with the database URL highlighted, annotated with an arrow labeled "URL to paste in variable `FIREBASE_DB_URL`". -->

### 6. Run the simulator first — it creates the test data

- In Command Prompt, type:
  ```bash
  cd .\src\
  cd .\store_board\
  python simulate_gateway.py
  ```

Example output:
```
PS F:\aiot-inventory-predictor\src\store_board> python simulate_gateway.py
Simulated gateway starting — reporting every 30s. Ctrl+C to stop.

[00:09:05] Pushing readings...
  BIN-R10K-08      8399 pcs  (340.0g)  [ok]
  BIN-C100N-06     1199 pcs  (28.0g)   [ok]
  BIN-CONUSBC16     339 pcs  (612.0g)  [ok]
  BIN-IC-M328P      899 pcs  (810.0g)  [ok]
  BIN-LED-R06      5199 pcs  (31.0g)   [ok]
```

><!-- > 📷 **`image16`** — Terminal showing the simulator's first batch of pushed readings. -->

><!-- 📷 **`image17`** — Terminal showing a later batch of readings and the `Stopped.` message after Ctrl+C. -->

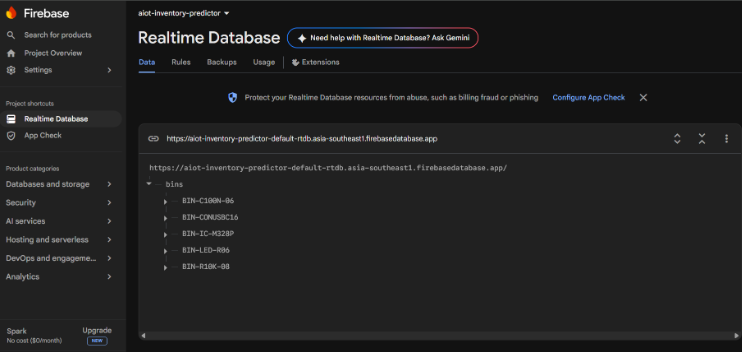
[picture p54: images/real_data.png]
Realtime Data
   — Firebase Realtime Database "Data" tab showing the `bins` node populated with entries like `BIN-C100N-06`, `BIN-CONUSBC16`, etc.

⚠️ Leave this window open and running — it pushes a new reading every 30 seconds and needs to run for **at least 5 minutes** before there's enough data to train on.

### 7. Open a second window and run the training script

- **Don't close the simulator's window.** Open a **new** Command Prompt window (same way as step 1), type `cd C:\store-board` again, then:
  ```bash
  python train_forecast.py
  ```
- This one runs once and exits — rerun it any time to refresh predictions with newer data.

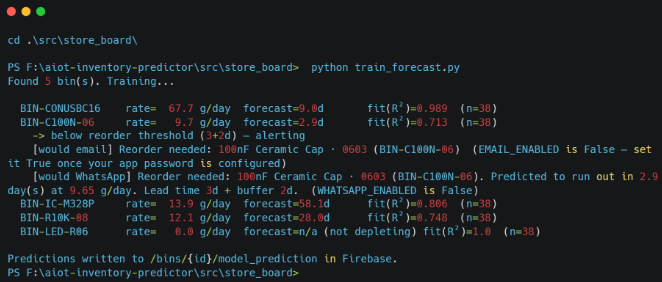
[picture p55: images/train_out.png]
 — Terminal output of `train_forecast.py`, showing per-bin rate/forecast/fit lines and reorder alert output.

### 8. What success looks like

Once `train_forecast.py` runs, you should see one line per bin, like:

```
BIN-R10K-08   rate=285.3 g/day  forecast=27.4d  fit(R²)=0.94  (n=12)
```

- If instead you see only 4 point(s) logged — need 10 — that just means the simulator hasn't been running long enough yet. Let it keep going a bit longer and rerun.
- At 30-second intervals, 10 minutes gives you about 20 readings per bin — double the minimum of 10 the training script needs.
- To stop the simulator: click into that Command Prompt window and press **Ctrl+C**. You'll see a `Stopped.` message, and the window is free to close.

### 9. Output Analysis

Reading each column:

| Column | Meaning |
|---|---|
| `rate` | The consumption speed the model learned from real data (grams/day) — not an assumption |
| `forecast` | Days until that bin hits zero, at the learned rate |
| `R²` | How confidently the model believes its own trend line, from 0 to 1. Closer to 1.0 = a clean, consistent depletion pattern. Lower = noisier, less certain |

> **`BIN-C100N-06` triggered the alert** — its forecast of 2.9 days is below its 3+2 = 5 day threshold, so the script correctly flagged it as needing a reorder. Right now it only printed what it *would have* sent, because email/WhatsApp are still switched off — that's expected, not a failure. This is the reorder logic working exactly as designed, end to end, on real data.

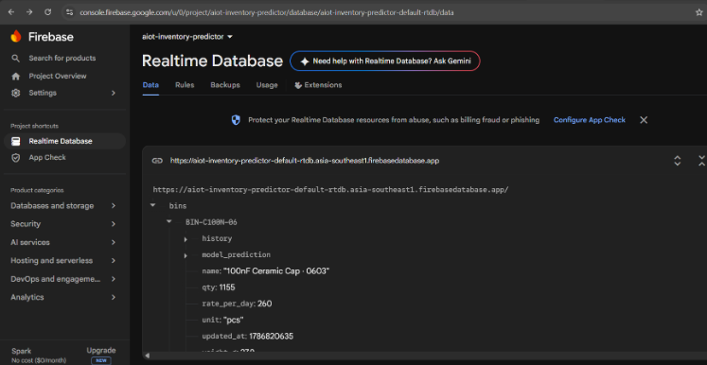
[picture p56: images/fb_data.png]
Realtime Data
  — Firebase Realtime Database showing a bin's `model_prediction` node with fields like `name`, `qty`, `rate_per_day`, `unit`, `updated_at`.

### How to enable Email and WhatsApp

**Email:**

- By default `EMAIL_ENABLED = False`, so right now it just prints `[would email]` — safe to test with the simulator without spamming a real inbox.
- To actually turn emails on:
  1. On the Gmail account you'll send from: turn on **2-Step Verification**, then go to **Google Account → Security → App Passwords** and generate one (Gmail requires this — it won't accept your normal password).

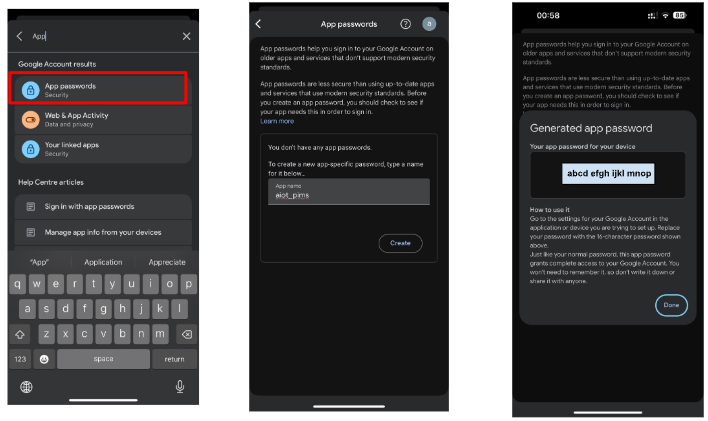
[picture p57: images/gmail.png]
Gmail settings
  — Google Account "App passwords" settings screen. Generating a new app password, naming it (e.g. "aiot_pims").

  2. Paste that into `EMAIL_APP_PASSWORD`, fill in `EMAIL_FROM` / `EMAIL_TO`, set `EMAIL_ENABLED = True`.
  ```c
EMAIL_ENABLED = True
EMAIL_FROM = "aXXXXXXXXX@gmail.com"
EMAIL_APP_PASSWORD = "xxxx xxxx xxxx xxxx"   # not your normal password 
EMAIL_TO = "bXXXXXXX@gmail.com"
```

- Two things set as defaults that you should sanity-check once real data exists:
  - The **24-hour cooldown** between repeat alerts for the same bin — change `ALERT_COOLDOWN_HOURS` if you want it more/less frequent.

```c
ALERT_COOLDOWN_HOURS = 24
```

  - The **3+2 day default lead time** — that's a placeholder until you know each real component's actual reorder time.
  ```c
DEFAULT_REORDER_LEAD_DAYS = 3
DEFAULT_REORDER_BUFFER_DAYS = 2
```
- You can override this per bin by adding `reorder_lead_days` directly on that bin's node in Firebase.

**WhatsApp via CallMeBot — free, no signup, one HTTP call:**

- This is a well-known hobbyist service (confirmed still active) built for exactly this — sending yourself alerts from scripts, Arduino boards, home automation, etc.
- The catch: it's explicitly **personal-use only**, meaning it sends to your own WhatsApp number, not to arbitrary customers at scale.
- For this prototype — alerting the storekeeper (you, for the demo) — that's exactly the use case it's built for.

**Setup (do this once):**

1. Save `+34 644 33 66 63` to your phone contacts as anything you like (this is CallMeBot's official bot number — if it doesn't respond, check [callmebot.com](https://www.callmebot.com), they occasionally rotate to a backup number when the primary fills up).
2. From your own WhatsApp, message that contact:
   ```
   I allow callmebot to send me messages
   ```
3. Within a couple of minutes you'll get a reply containing your API key — save it, you'll need it in the script.

# Hardware setup
## Initial setup:

Reference Link: https://daplink.io/ 

#### Connections:
- Ribbon cable orientation — the cable has a colored stripe on one edge (marking pin 1). 

- It looks seated straight into both headers, but it's worth double-checking that the stripe lines up with the pin-1 marking (usually a small triangle, dot, or square pad) on both the PICO's connector and the target's header. 

- A cable seated backward or offset by one pin is a classic cause of exactly this "board not found" symptom, since the boards will still power up fine but SWD communication will fail.

- Give the MCU board its own power
The MAX32625PICO cannot supply power to every target board through the debug header alone. If your MCU is only powered through the PICO connection (rather than its own USB/power cable), connect a separate powered USB cable directly to the MCU board as well, so both boards are independently powered during programming.

### On Windows11 PC:
1. Download the firmware file.

2. While holding down the boards reset button, connect the boards USB debug port to the computer. It should enumerate and mount as ``` BOOTLOADER ``` or ``` MAINTENANCE ```. For boards that enumerate as ``` BOOTLOADER ``` see our blog to determine if an update for the DAPLink bootloader is available.

3. Drag-and-drop the firmware file onto the mounted drive.
Wait for the file copy operation to complete.

4. Power cycle the board - Disconnect the USB cable from the board to remove power, then reconnect it normally without holding any buttons.

5. It will now enumerate and mount as ``` DAPLIN ``` or the name of the board.

6. Windows has removed the wmic command, and the older Maxim daplink tool, so try the below method:

##### Export the compiled binary
In Arduino IDE, go to Sketch → Export Compiled Binary. This saves the .bin file into your sketch's own folder permanently, instead of a temp folder that gets wiped — open the sketch folder afterward (Sketch → Show Sketch Folder) and you'll see it there.

##### Open the DAPLINK drive
Open File Explorer and confirm the DAPLINK drive is mounted (it should show a drive letter next to the label DAPLINK, alongside DETAILS.TXT).

##### Copy the .bin file onto the DAPLINK drive
Simply drag the exported .bin file from your sketch folder and drop it onto the DAPLINK drive, just like copying a file to a USB stick. The drive will briefly disappear and remount as it flashes the firmware.

##### Check for success
If something went wrong, a FAIL.TXT file will appear on the drive explaining why. If it succeeds, the board will reset and your Blink sketch should start running — with Auto Reset enabled on your board, this happens automatically.

#### Note: 
Eventhough i flashed the board using windows 11 PC, Later i switched to ubuntu 20.04 LTS, becuase driver support was limited in windows for me. 

---
[← Back: Software Architecture & Code](software-architecture.md) · [← Back to README](../README.md)

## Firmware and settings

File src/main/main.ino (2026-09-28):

/*
   MAX32630FTHR -> NodeMCU sensor bridge (UART, push-based)

   No handshake, no request/response: this board just pushes a fresh
   sensor reading over Serial2 every 2 seconds, unprompted. NodeMCU only
   ever needs to listen and relay - removing the request/response
   pattern removes the deadlock risk it had (both sides silently
   waiting to hear from the other before speaking first).

   Builds on two things already confirmed working in this project:
    - Serial2's hardware genuinely initializes (UART_Init returns 0),
      once the debug console and Serial2 are matched to the same baud
      rate - this chip shares one clock divider across every UART.
    - Default Serial2 pins: P3_0 (RX), P3_1 (TX).

 *     *** Load Sensor ***
   Connections:
   HX711            Aries Board
   VCC          -   3.3V
   GND          -   GND
   Dout         -   P5_5 (pin 45 in software)
   sck          -   P5_4 (pin 44 in software)

 *     *** OLED (SSD1306) ***
   Requires: Adafruit SSD1306, Adafruit GFX Library, Adafruit BusIO
   OLED       MAX32630 (Arduino pins 28/29)
   GND        GND
   VCC        3V3
   SDA        P3_4
   SCL        P3_5

 *     *** Ultrasonic (HC-SR04) ***
   Important: ECHO outputs 5V - use a voltage divider (ECHO -> 1k -> P4_0,
   P4_0 -> 2k -> GND) before connecting to the board. TRIG is fine direct.
   GND          -   GND
   VCC          -   3V3
   ECHO         -   P4_0
   TRIG         -   P5_6

 *     *** IR Sensor ***
   Active-HIGH module (HIGH = object detected, LOW = clear).
   Used here to estimate picks: on hand-arrival we snapshot the weight;
   on hand-departure we wait for the scale to settle, then the weight
   drop / weightPerPiece gives an estimated pick quantity.
   GND          -   GND
   VCC          -   3V3
   SIG          -   P3_3

 *     *** RYG LED (stock level indicator) ***
   GND          -   GND
   R            -   P5_0
   Y            -   P5_1
   G            -   P5_2
   >50% of totalRygCount  -> Green solid
   21-50%                 -> Yellow solid
   <=20%                  -> Red solid

 *     *** Piezo Buzzer (power-switched) ***
   Buzzer VCC   -> Board 3V3
   Buzzer GND   -> Transistor Collector
   Buzzer SIG   -> Board GND (tied permanently low, not used for control)
   Transistor Emitter -> Board GND
   Transistor Base    -> 1k resistor -> P5_3
   This module self-latches its internal oscillator on a SIG pulse and
   won't stop from SIG alone - GPIO here instead switches power to it
   via the transistor, which guarantees it turns off.
   Beeps for 5s when stock level transitions into Red (<=20%).
*/



#include <HX711_ADC.h> //weight sensor 
#include <Wire.h>
#include <Adafruit_GFX.h>
#include <Adafruit_SSD1306.h>


//weight sensor pins:
const int HX711_dout = 45; //Connect dout of sensor to GPIO-2 of aries board
const int HX711_sck = 44; //Connect dout of sensor to GPIO-3 of aries board

// --- OLED config ---
#define SCREEN_WIDTH 128
#define SCREEN_HEIGHT 64      // change to 32 if you have a 128x32 display instead
#define OLED_ADDR 0x3C        // common default - change if the scanner found a different address (e.g. 0x3D)
Adafruit_SSD1306 display(SCREEN_WIDTH, SCREEN_HEIGHT, &Wire, -1); // -1 = no dedicated reset pin
// -------------------

// --- Ultrasonic (HC-SR04) config ---
#define TRIG_PIN P5_6
#define ECHO_PIN P4_0

unsigned long lastDistanceReadTime = 0;
const unsigned long distanceReadInterval = 1000; // how often to trigger a new distance reading (ms)
float latestDistanceCm = 0; // cached, updated by getDistanceData()
// ------------------------------------

// --- IR sensor / pick estimation config ---
#define IR_PIN P3_3

int lastIrState = LOW;
unsigned long lastIrChangeTime = 0;
const unsigned long irDebounceMs = 50; // debounce for the raw IR signal itself

const unsigned long pickSettleMs = 1000; // time to let the scale restabilize after a hand leaves, before trusting the new weight
bool awaitingSettle = false;
unsigned long settleStartTime = 0;
float weightBeforePick = 0;
long irEventCount = 0;          // raw hand-detected events - diagnostic only, not sent
long picksEstimatedTotal = 0;   // cumulative estimated picks, derived from weight drop after each hand detection - this is what gets sent
long lastPickQty = 0;           // most recent single pick's estimate - diagnostic only, not sent
// -------------------------

// --- RYG LED status indicator config ---
#define LED_RED    P5_0
#define LED_YELLOW P5_1
#define LED_GREEN  P5_2

const long totalRygCount = 12; // total capacity for this bin - fixed for now; make this user-configurable later if needed
// -------------------------

// --- Buzzer alert config ---
#define BUZZER_PIN P5_3

const unsigned long buzzerDurationMs = 5000; // how long to keep power on once triggered
bool buzzerActive = false;
unsigned long buzzerStartTime = 0;

bool wasRed = false;       // tracks previous red state, so the buzzer fires only on entering red - not every cycle while it stays red
bool currentlyRed = false; // set by rygLed_update(), read by buzzer_update()
// -------------------------

// --- Bin identity & metadata (edit per deployment - sent to NodeMCU, which relays to Firebase) ---
const char* binId             = "BIN-RYG-08";
const char* binName           = "RYG LED Sensor - 0805";   // avoid special chars like Omega/middot - keep ASCII
const char* binCategory       = "LEDs";
const char* binDepartment     = "Assembly";
const char* binUnit           = "pcs";
const int   binRatePerDay     = 3;
const char* binSupplier       = "Digikey";
const float binPrice          = 0.4;
const char* batchId           = "B-3301";
const char* batchFirstScanned = "2026-07-20";
const long  batchInitialQty   = 12;

unsigned long lastMetadataSendTime = 0;
const unsigned long metadataResendInterval = 30000; // resend periodically so NodeMCU catches it even if it missed the boot-time send
// ------------------------------------------------------------

// --- inventory calibration for THIS bin (fill these in) ---
const float containerTareGrams = 55.89;   // weight of the empty reel/box, measured once
const float weightPerPiece     = 3.55;   // ryg tested - grams per single component, measured once
const float noiseThreshold     = 0.5;    // grams - anything below this is treated as "no weight"
// ------------------------------------------------------------

//HX711 constructor:
HX711_ADC LoadCell(HX711_dout, HX711_sck);

unsigned long t = 0;  // paces the load-cell debug print
unsigned long lastSendTime = 0;
const unsigned long sendInterval = 2000; // how often to push over Serial2
float latestWeight = 0; // cached, updated by getSensorData() every loop pass
long lastSentCount = -1;   // tracks previous "Sent" value so OLED can show + or - on change

void hx711_setup() {
  float calibrationValue; // calibration value
  calibrationValue = 530.0; // we need to calculate this before to get correct weight measurement

  LoadCell.begin();
  unsigned long stabilizingtime = 2000; // tare preciscion can be improved by adding a few seconds of stabilizing time
  boolean _tare = true; //set this to false if you don't want tare to be performed in the next step
  LoadCell.start(stabilizingtime, _tare);
  if (LoadCell.getTareTimeoutFlag()) {
    Serial.println("Timeout, check MCU>HX711 wiring and pin designations");
  }
  else {
    LoadCell.setCalFactor(calibrationValue); // set calibration factor (float)
    Serial.println("Startup is complete");
  }

  while (!LoadCell.update());
  Serial.print("Calibration value: ");
  Serial.println(LoadCell.getCalFactor());
  Serial.print("HX711 measured conversion time ms: ");
  Serial.println(LoadCell.getConversionTime());
  Serial.print("HX711 measured sampling rate HZ: ");
  Serial.println(LoadCell.getSPS());
  Serial.print("HX711 measured settlingtime ms: ");
  Serial.println(LoadCell.getSettlingTime());
  Serial.println("Note that the settling time may increase significantly if you use delay() in your sketch!");
  if (LoadCell.getSPS() < 7) {
    Serial.println("!!Sampling rate is lower than specification, check MCU>HX711 wiring and pin designations");
  }
  else if (LoadCell.getSPS() > 100) {
    Serial.println("!!Sampling rate is higher than specification, check MCU>HX711 wiring and pin designations");
  }
}

// Averages several readings into one stable value.
// Handy for one-off jobs like measuring containerTareGrams by hand
// (put the empty bin on the scale, call this, read the result off
// the serial monitor, then paste that number into containerTareGrams above).
float getAveragedWeight(int numReadings) {
  float sum = 0;
  int count = 0;
  while (count < numReadings) {
    if (LoadCell.update()) {
      sum += LoadCell.getData();
      count++;
    }
  }
  return sum / numReadings;
}

float getSensorData() {
  //float weight;
  static boolean newDataReady = 0;
  const int serialPrintInterval = 500; //increase value to slow down serial print activity

  // check for new data/start next conversion:
  if (LoadCell.update())
    newDataReady = true;

  // get smoothed value from the dataset:
  if (newDataReady) {
    if (millis() > t + serialPrintInterval) {
      float raw = LoadCell.getData();
      latestWeight = (fabs(raw) < noiseThreshold) ? 0.0 : raw;
      Serial.print("Load_cell output val: ");
      Serial.println(latestWeight);
      newDataReady = 0;
      t = millis();
    }
  }

  // receive command from serial terminal, send 't' to initiate tare operation:
  if (Serial.available() > 0) {
    char inByte = Serial.read();
    if (inByte == 't') LoadCell.tareNoDelay();
  }

  // check if last tare operation is complete:
  if (LoadCell.getTareStatus() == true) {
    Serial.println("Tare complete");
  }

  return latestWeight;
}

//OLED setup function
void oled_setup() {
  Wire.begin(); // master mode, default pins (SDA = pin 28, SCL = pin 29)

  if (!display.begin(SSD1306_SWITCHCAPVCC, OLED_ADDR)) {
    Serial.println("SSD1306 not found - check wiring/address, or run the I2C scanner");
    while (true) {
      delay(1000);  // halt here rather than continue with a display that isn't there
    }
  }

  display.clearDisplay();
  display.setTextSize(2);
  display.setTextColor(SSD1306_WHITE);
  display.setCursor(10, 25);
  display.println("Ready");
  display.display();
}

void oled_showCount(long count) {
  char symbol = ' ';   // no symbol on the very first reading - nothing to compare against yet

  if (lastSentCount != -1) {
    if (count > lastSentCount) symbol = '+';
    else if (count < lastSentCount) symbol = '-';
  }
  lastSentCount = count;

  display.clearDisplay();
  display.setTextSize(4);
  display.setTextColor(SSD1306_WHITE);
  display.setCursor(60, 25);
  if (symbol != ' ') display.print(symbol);
  display.println(count);
  display.display();
}

void ultrasonic_setup() {
  useVDDIOH(TRIG_PIN);
  useVDDIOH(ECHO_PIN);

  pinMode(TRIG_PIN, OUTPUT);
  pinMode(ECHO_PIN, INPUT);

  digitalWrite(TRIG_PIN, LOW);
}

float getDistanceData() {
  if (millis() - lastDistanceReadTime >= distanceReadInterval) {
    lastDistanceReadTime = millis();

    // Send a 10us trigger pulse
    digitalWrite(TRIG_PIN, LOW);
    delayMicroseconds(2);
    digitalWrite(TRIG_PIN, HIGH);
    delayMicroseconds(10);
    digitalWrite(TRIG_PIN, LOW);

    // Measure echo pulse width (timeout ~25ms ≈ 4m range, avoids hanging if no echo)
    long duration = pulseIn(ECHO_PIN, HIGH, 25000);

    if (duration > 0) {
      // distance(cm) = duration(us) / 58  →  speed of sound ≈ 343 m/s
      latestDistanceCm = duration / 58.0;
      Serial.print("Distance: ");
      Serial.print(latestDistanceCm);
      Serial.println(" cm");
    } else {
      Serial.println("No echo received (out of range or no object)");
    }
  }

  return latestDistanceCm;
}

void ir_setup() {
  useVDDIOH(IR_PIN);
  pinMode(IR_PIN, INPUT);
  lastIrState = digitalRead(IR_PIN);
}

void pollPickEstimator() {
  int currentState = digitalRead(IR_PIN);

  if (currentState != lastIrState && millis() - lastIrChangeTime >= irDebounceMs) {
    lastIrChangeTime = millis();
    lastIrState = currentState;

    if (currentState == HIGH) {
      // hand just arrived - remember the weight right before it starts picking
      irEventCount++;
      weightBeforePick = latestWeight;
      awaitingSettle = false; // cancel any pending settle from a previous, unfinished pick
      Serial.println("Hand detected - capturing baseline weight");
    } else {
      // hand just left - start the settle timer before trusting the new weight
      settleStartTime = millis();
      awaitingSettle = true;
      Serial.println("Hand removed - waiting for scale to settle");
    }
  }

  if (awaitingSettle && millis() - settleStartTime >= pickSettleMs) {
    awaitingSettle = false;
    float weightDrop = weightBeforePick - latestWeight;

    if (weightDrop > (weightPerPiece / 2.0)) { // require at least half a piece's worth before counting anything
      long pickedCount = (long)round(weightDrop / weightPerPiece);
      if (pickedCount > 0) {
        picksEstimatedTotal += pickedCount;
        lastPickQty = pickedCount;
        Serial.print("Estimated pick: ");
        Serial.print(pickedCount);
        Serial.print(" piece(s). Running total: ");
        Serial.println(picksEstimatedTotal);
      }
    } else {
      Serial.println("No significant weight drop - not counted as a pick");
    }
  }
}

void rygLed_setup() {
  useVDDIOH(LED_RED);
  useVDDIOH(LED_YELLOW);
  useVDDIOH(LED_GREEN);

  pinMode(LED_RED, OUTPUT);
  pinMode(LED_YELLOW, OUTPUT);
  pinMode(LED_GREEN, OUTPUT);

  digitalWrite(LED_RED, LOW);
  digitalWrite(LED_YELLOW, LOW);
  digitalWrite(LED_GREEN, LOW);
}

void rygLed_update(long count) {
  float percentRemaining = (totalRygCount > 0) ? (100.0 * count / totalRygCount) : 0;

  bool red = false, yellow = false, green = false;

  if (percentRemaining <= 20.0) {
    red = true;
  } else if (percentRemaining <= 50.0) {
    yellow = true;
  } else {
    green = true;
  }

  digitalWrite(LED_RED, red ? HIGH : LOW);
  digitalWrite(LED_YELLOW, yellow ? HIGH : LOW);
  digitalWrite(LED_GREEN, green ? HIGH : LOW);

  currentlyRed = red;
}

void buzzer_setup() {
  useVDDIOH(BUZZER_PIN);
  pinMode(BUZZER_PIN, OUTPUT);
  digitalWrite(BUZZER_PIN, HIGH); // HIGH = off, based on your wiring's actual behavior
}

void buzzer_start() {
  buzzerActive = true;
  buzzerStartTime = millis();
  digitalWrite(BUZZER_PIN, LOW); // LOW = on, based on your wiring's actual behavior
  Serial.println("Buzzer ON");
}

void buzzer_stop() {
  buzzerActive = false;
  digitalWrite(BUZZER_PIN, HIGH); // HIGH = off, based on your wiring's actual behavior
  Serial.println("Buzzer OFF");
}

void buzzer_update(bool isRed) {
  if (isRed && !wasRed && !buzzerActive) { // ignore re-triggers while a beep is already playing
    buzzer_start();
  }
  wasRed = isRed;

  if (buzzerActive && millis() - buzzerStartTime >= buzzerDurationMs) {
    buzzer_stop();
  }
}

void sendBinMetadata() {
  Serial2.print("META|");
  Serial2.print(binId);             Serial2.print('|');
  Serial2.print(binName);           Serial2.print('|');
  Serial2.print(binCategory);       Serial2.print('|');
  Serial2.print(binDepartment);     Serial2.print('|');
  Serial2.print(binUnit);           Serial2.print('|');
  Serial2.print(binRatePerDay);     Serial2.print('|');
  Serial2.print(binSupplier);       Serial2.print('|');
  Serial2.print(binPrice);          Serial2.print('|');
  Serial2.print(batchId);           Serial2.print('|');
  Serial2.print(batchFirstScanned); Serial2.print('|');
  Serial2.print(batchInitialQty); Serial2.print('|');
  Serial2.println(weightPerPiece);
}

void setup() {
  Serial.begin(9600);   // matches Serial2's baud - required, see note above
  Serial2.begin(9600);  // UART link to NodeMCU
  Serial.println("\nMAX32630FTHR UART bridge starting...");
  hx711_setup();
  oled_setup();
  ultrasonic_setup();
  ir_setup();
  rygLed_setup();
  buzzer_setup();
  sendBinMetadata();
}


void loop() {
  getSensorData();          // poll load cell - every pass, no delay
  getDistanceData();        // poll ultrasonic - self-gated to distanceReadInterval internally
  pollPickEstimator();      // self-debounced/self-timed internally, no delay needed
  buzzer_update(currentlyRed); // checked every pass so the 5s cutoff stays precise

  if (millis() - lastMetadataSendTime >= metadataResendInterval) {
    lastMetadataSendTime = millis();
    sendBinMetadata();
  }

  if (millis() - lastSendTime >= sendInterval) {
    lastSendTime = millis();

    long pieceCount = (long)round((latestWeight - containerTareGrams) / weightPerPiece);
    if (pieceCount < 0) pieceCount = 0;
    rygLed_update(pieceCount);

    float netWeight = latestWeight - containerTareGrams; // subtract bin's own weight, so this is just the components
    if (netWeight < 0) netWeight = 0;                     // clamp, same reasoning as pieceCount


    char msg[80];
    sprintf(msg, "DATA|%s|%ld|%.1f|%ld|%.2f", binId, pieceCount, latestDistanceCm, picksEstimatedTotal, netWeight);
    oled_showCount(pieceCount);

    Serial2.println(msg);
    Serial.print("Sent: ");
    Serial.println(msg);
  }
}

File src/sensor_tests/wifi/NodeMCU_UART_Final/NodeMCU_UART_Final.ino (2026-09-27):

/*
   NodeMCU <-> MAX32630FTHR <-> Firebase bridge (push-based, generic relay)

   MAX32630FTHR owns all the bin identity/metadata and decides what gets
   written where - this sketch just parses two message types it receives
   over MaxSerial and relays fields to Firebase. It doesn't know or care
   what a "resistor" or "category" is.

    META|<binId>|<name>|<category>|<department>|<unit>|<ratePerDay>|<supplier>|<price>|<batchId>|<firstScanned>|<initialQty>
      -> static bin info, sent once at boot + resent periodically as a safety net
    DATA|<binId>|<qty>|<distanceCm>|<picksEstimated>
      -> live values, sent every 2s. picksEstimated is a running total of
         estimated picks, derived on the MAX32630FTHR side by correlating
         IR hand-detection events with the load-cell weight drop.

   Wiring (unchanged from the original project):
   NodeMCU D7 (GPIO13, RX) <- MAX32630FTHR P3_1 (Serial2 TX)
   NodeMCU D8 (GPIO15, TX) -> MAX32630FTHR P3_0 (Serial2 RX) - unused by
     this simplified version, but fine to leave wired for future use
   NodeMCU 3.3V -> MAX32630FTHR 3V3, NodeMCU GND -> MAX32630FTHR GND
*/

#include <ESP8266WiFi.h>
#include <ESP8266HTTPClient.h>
#include <WiFiClientSecure.h>
#include <SoftwareSerial.h>

// ---------- Wi-Fi credentials ----------
#define WIFI_SSID       "GNXS-2.4G-32E5B0"   //put your wifi/hotspot name here
#define WIFI_PASSWORD   "12345678@"        //put your wifi/hotspot password here
// ---------- Firebase Realtime Database ----------
#define FIREBASE_HOST   "aiot-inventory-predictor-default-rtdb.asia-southeast1.firebasedatabase.app/"
//#define FIREBASE_HOST   "randomdata-643f2-default-rtdb.asia-southeast1.firebasedatabase.app"
#define FIREBASE_AUTH   ""

// ---------- UART link to MAX32630FTHR ----------
SoftwareSerial MaxSerial(13, 15); // RX, TX

const int BUF_SIZE = 160;   // must comfortably fit the longest META line
char rxBuffer[BUF_SIZE];
long eventCounter = 0;

String currentBinId = "";
String currentBatchId = "";
bool metadataReceived = false;

// ---------------------------------------------------------
// Reads one line (ending in '\n') from MaxSerial into rxBuffer.
// Only called once available() > 0, i.e. a line is already arriving,
// so the timeout here just guards against a partial/corrupted line
// missing its terminator, not against normal idle time.
// ---------------------------------------------------------
bool readLine() {
  int idx = 0;
  unsigned long startTime = millis();

  while (true) {
    if (MaxSerial.available() > 0) {
      char c = MaxSerial.read();
      if (c == '\n') {
        rxBuffer[idx] = '\0';
        return true;
      }
      if (idx < BUF_SIZE - 1) {
        rxBuffer[idx] = c;
        idx++;
      }
    }

    if (millis() - startTime > 3000) { // safety timeout - a full line should arrive well within this
      rxBuffer[idx] = '\0';
      return false;
    }
  }
}

void sendToFirebase(const String &path, const String &jsonValue) {
  if (WiFi.status() != WL_CONNECTED) {
    Serial.println("WiFi not connected, skipping Firebase write");
    return;
  }

  WiFiClientSecure client;
  client.setInsecure(); // skips certificate check - fine for bench testing only

  HTTPClient https;
  String url = String("https://") + FIREBASE_HOST + "/" + path + ".json";
  if (strlen(FIREBASE_AUTH) > 0) {
    url += "?auth=" + String(FIREBASE_AUTH);
  }

  if (https.begin(client, url)) {
    https.addHeader("Content-Type", "application/json");
    int httpCode = https.PUT(jsonValue);

    Serial.print(path);
    Serial.print(" -> HTTP ");
    Serial.println(httpCode);

    if (httpCode <= 0) {
      Serial.print("PUT failed: ");
      Serial.println(https.errorToString(httpCode));
    }
    https.end();
  } else {
    Serial.println("Unable to open HTTPS connection to Firebase");
  }
}

void handleMetadata(char *data) {
  char *binId        = strtok(data, "|");
  char *name         = strtok(NULL, "|");
  char *category     = strtok(NULL, "|");
  char *department   = strtok(NULL, "|");
  char *unit         = strtok(NULL, "|");
  char *ratePerDay   = strtok(NULL, "|");
  char *supplier     = strtok(NULL, "|");
  char *price        = strtok(NULL, "|");
  char *batchId      = strtok(NULL, "|");
  char *firstScanned = strtok(NULL, "|");
  char *initialQty   = strtok(NULL, "|");
  char *weightPerUnit = strtok(NULL, "|");

  Serial.println("--- META fields parsed ---");
  Serial.print("binId: "); Serial.println(binId ? binId : "(null)");
  Serial.print("name: "); Serial.println(name ? name : "(null)");
  Serial.print("category: "); Serial.println(category ? category : "(null)");
  Serial.print("department: "); Serial.println(department ? department : "(null)");
  Serial.print("unit: "); Serial.println(unit ? unit : "(null)");
  Serial.print("ratePerDay: "); Serial.println(ratePerDay ? ratePerDay : "(null)");
  Serial.print("supplier: "); Serial.println(supplier ? supplier : "(null)");
  Serial.print("price: "); Serial.println(price ? price : "(null)");
  Serial.print("batchId: "); Serial.println(batchId ? batchId : "(null)");
  Serial.print("firstScanned: "); Serial.println(firstScanned ? firstScanned : "(null)");
  Serial.print("initialQty: "); Serial.println(initialQty ? initialQty : "(null)");
  Serial.print("weightPerUnit: "); Serial.println(weightPerUnit ? weightPerUnit : "(null)");
  Serial.println("---------------------------");

  if (binId == NULL || batchId == NULL) {
    Serial.println("Malformed META line, skipping");
    return;
  }

  currentBinId = String(binId);
  currentBatchId = String(batchId);

  String base = "bins/" + currentBinId;
  sendToFirebase(base + "/name", "\"" + String(name) + "\"");
  sendToFirebase(base + "/category", "\"" + String(category) + "\"");
  sendToFirebase(base + "/department", "\"" + String(department) + "\"");
  sendToFirebase(base + "/unit", "\"" + String(unit) + "\"");
  sendToFirebase(base + "/rate_per_day", String(ratePerDay));
  sendToFirebase(base + "/supplier", "\"" + String(supplier) + "\"");
  sendToFirebase(base + "/price", String(price));
  sendToFirebase(base + "/batches/" + currentBatchId + "/id", "\"" + currentBatchId + "\"");
  sendToFirebase(base + "/batches/" + currentBatchId + "/firstScanned", "\"" + String(firstScanned) + "\"");
  sendToFirebase(base + "/batches/" + currentBatchId + "/initial", String(initialQty));
  if (weightPerUnit != NULL) {
    sendToFirebase(base + "/weightPerUnit", String(weightPerUnit));
  }

  metadataReceived = true;
  Serial.println("Bin metadata written to Firebase");
}
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

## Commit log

2026-08-19 added firebase url to gui with sample data
2026-08-31 board tested with blink pgm
2026-09-11 sensor tests
2026-09-11 weight sensor added doc
2026-09-17 camera module added
2026-09-21 camera added
2026-09-22 camera module libraries added
2026-09-22 design files added
    [back_cover_v6.step, back_cover_v6.stl, case_body_v6.step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]
2026-09-22 new design added for case
    [00_CASE_ASSEMBLY_printed_parts_only.step, 01_tower_body.step, 01_tower_body.stl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]
2026-09-23 all sensor test added
2026-09-27 weight sensor integrated demo code
2026-09-27 weight per sensor sending to firebase added
2026-09-29 schematics added
2026-09-29 updated schematic
2026-09-29 sensors added
